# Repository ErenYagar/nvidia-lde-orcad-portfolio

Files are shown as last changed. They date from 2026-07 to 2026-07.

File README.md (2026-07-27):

# PCIe Gen3 x4 → M.2 NVMe adapter

**An interview-ready OrCAD X / Allegro PCB system-design case study.**<br>
This repository documents a six-layer, low-profile PCIe add-in card that physically connects a host PCIe slot to an M.2 M-Key 2280 NVMe SSD. It is a **passive interposer, not a protocol converter**.

**Current status:** `Interview_Digital_Complete_Not_For_Fabrication`<br>
**Not claimed:** PCIe compliance, universal SSD support, chassis compatibility, bench qualification, SI/PI sign-off, thermal validation or fabrication-ready release.

## Start here

1. [Open the bilingual visual portfolio](portfolio/index.html)
2. [Read the technical case study — English](PROJECT_REPORT_EN.md) / [繁體中文](PROJECT_REPORT_ZH.md)
3. [Use the interview walkthrough — English](docs/INTERVIEW_GUIDE.md) / [繁體中文](docs/INTERVIEW_GUIDE_ZH.md)
4. [Trace every claim — English](docs/CLAIM_EVIDENCE_MATRIX.md) / [繁體中文](docs/CLAIM_EVIDENCE_MATRIX_ZH.md)
5. [Read the documentation audit — English](docs/DOCUMENTATION_AUDIT_EN.md) / [繁體中文](docs/DOCUMENTATION_AUDIT_ZH.md)

## What the board actually does

| Boundary | Implementation |
|---|---|
| Host/SSD data | J1 PCIe edge → eight data pairs + REFCLK/sideband → J2 M.2 M-Key 2280 |
| Power | PCIe slot 12 V → TPS25947-family eFuse → TPS543620 6 A buck → 5 mΩ Kelvin shunt → 3.3 V SSD |
| Telemetry | INA238 current monitor + TMP1075 temperature sensor + target-only I²C header |
| PCB baseline | Six layers, 120 × 64 mm preliminary envelope, 1.6 mm nominal |

The system interface and layer intent are defined in [`docs/interface_definition.md`](docs/interface_definition.md) and [`docs/system_block_diagram.md`](docs/system_block_diagram.md).

## Five design decisions

| Decision | Why it is in the case study | Current boundary |
|---|---|---|
| 12 V + eFuse + buck | Makes protection, conversion and hot-loop reviewable | Slot budget/eFuse behavior still open |
| 5 mΩ Kelvin shunt | Enables low-loss current telemetry | Calibration/bench correlation open |
| No added lane conditioning | Preserves transmitter ownership until specs are confirmed | CEM/M.2 controlled pin source blocked |
| L1/L6 referenced to L2/L5 | Makes return-path intent explicit | Width/gap/via geometry pending fabricator |
| Gerber + IPC-2581-C | Provides available manufacturing exchange | ODB++ unsupported; not fab-ready |

Full options and exit conditions: [`docs/architecture_tradeoff.md`](docs/architecture_tradeoff.md).

## Verification snapshot

| Item | Result |
|---|---|
| Native RevK DRC / unconnected / active rats / shape islands | 0 / 0 / 0 / 0 in current gate report |
| Differential-pair objects | 9 native pairs (8 data + REFCLK) |
| PSpice 5 A / 7 A window | Recorded model windows pass the 3.135 V screen; recovery reaches 3.109 V and fails |
| PSpice sweep | 27 cases retained, runtime-limited; no pass inferred |
| 3DX / STEP | Current-board native views and AP242/mm isolated re-import recorded |
| Manufacturing | Gerber, NC Drill, IPC-2581-C, BOM/P&P generated for engineering review |
| Hardware | No board measurement, enumeration, SI/PI or thermal result claimed |

Evidence sources: [`evidence/stage3/stage3_delivery_gate.md`](evidence/stage3/stage3_delivery_gate.md), [`pspice/stage2/profile_results.csv`](pspice/stage2/profile_results.csv), [`evidence/stage3/3d_status.md`](evidence/stage3/3d_status.md), [`manufacturing/stage3_final_revk/README.md`](manufacturing/stage3_final_revk/README.md).

## Repository map

- `schematic/` — connection matrix, symbol pins, footprint assignments and native Capture reports.
- `pcb/` — constraints, differential pairs, 3D model mapping and the native RevK board.
- `pspice/` — command-line profiles, recovery sweep records and model limits.
- `evidence/` — hash-bound gates, native 3DX screens, portfolio views and collision status.
- `manufacturing/` — Gerber, NC Drill, IPC-2581-C, BOM/P&P, STEP and export manifest.
- `scripts/` — standard-library validators and negative fixtures.

## Reproduce the data checks

```powershell
python scripts/validate_csv.py --root .
python scripts/check_bom_fields.py manufacturing/bom.csv
python scripts/check_duplicate_pins.py schematic/connection_matrix.csv schematic/symbol_pinmap.csv
python scripts/check_net_names.py schematic/connection_matrix.csv
python scripts/check_documentation_links.py --root .
python scripts/check_portfolio_i18n.py
python -m unittest discover -s scripts -p "test_*.py" -v
```

Expected interpretation is documented in [`VALIDATION_STATUS.md`](VALIDATION_STATUS.md); repo-specific public-package gaps are reported rather than suppressed.

## Next revision

Rev L must obtain controlled PCIe/M.2 pin sources and the current JLCPCB stack-up, close the PSpice recovery/eFuse gates, replace preliminary mechanical models, then perform DFM, fabrication and bench bring-up. Until then, this is an honest digital interview package—not a board-order instruction.

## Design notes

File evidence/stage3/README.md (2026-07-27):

# Stage 3 evidence

This folder records the audited routing/manufacturing candidate. It does not
claim fabrication readiness, PCIe compliance, completed physical bring-up or
bench qualification.

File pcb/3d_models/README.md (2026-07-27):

# 3D Model Store

本目錄只保存可追溯、授權允許且與 exact MPN／assembly相符的 mechanical models。
MDT420M01501 原廠 STEP 已於 2026-07-24 保存並完成來源與結構驗證；
footprint transform 與 collision review 尚未核准。

## Naming

```text
<manufacturer>_<mpn>_<document-revision>_<download-date>.<step|stp|iges|sab>
```

不得用 `connector.step`、`final.step` 等無法追溯名稱。原始 vendor file若必須保留
官方檔名，mapping CSV仍要記錄 exact MPN與 SHA-256。

## Required record

- manufacturer、exact MPN／assembly revision；
- official product／model URL；
- drawing number／revision；
- download date、login／license限制；
- file size、SHA-256、units；
- original or repaired copy；
- reviewer與 disposition。

## Current inventory and blockers

- `amphenol_mdt420m01501_vendor-c3d-rev-unstated_2026-07-24.stp`：
  exact official product-page model，AP214／mm，SHA-256
  `F5427DE4C21FD8C98D0425E09D63247DC632733ACE2211E52F6E282C68F593CD`。
  Vendor model revision未宣告；Allegro rotation／offset與collision仍待確認。
- PCIe bracket／standoff／exact SSD：尚未選定 exact model。
- Board assembly：Stage 1 native `.brd` 已存在；Stage 2 electrical board尚未建立。

禁止以相近 connector、generic 2280 block或其他專案的 3D model把 blocker標成已完成。

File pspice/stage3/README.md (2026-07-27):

# Stage 3 PSpice power closure

`pw01_recovery_closure_132u_8p2.cir` reruns the exact Stage 2 combined
startup/5 A/7 A/recovery profile with a 132 uF effective output-capacitance
corner and 3 mOhm aggregate ESR.

The value is a simulation candidate, not a released BOM value. It requires
capacitor part-number selection, DC-bias/temperature/tolerance evidence and
layout-parasitic correlation before power design freeze.

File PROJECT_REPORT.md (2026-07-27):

# PCIe Gen3 x4 → M.2 NVMe Adapter — Technical Case Study

語言 / Language：[`繁體中文版`](PROJECT_REPORT_ZH.md)｜[`English full version`](PROJECT_REPORT_EN.md)

**NVIDIA LDE interview portfolio · Rev K / RevK evidence · `Interview_Digital_Complete_Not_For_Fabrication`**<br>
這份報告把 repository 由「檔案清單」改成一個可追溯的 PCB system-design 故事。所有結論都連回原理圖資料、PSpice record、native Allegro/3DX evidence 或製造輸出；未量測或未取得受控來源的項目維持 open/block status。

> **Boundary:** 本板是 PCIe host 與 M.2 NVMe SSD 之間的 passive physical interposer，不是 PCIe protocol converter。未宣稱 PCIe compliance、universal SSD support、chassis compatibility、bench qualification、SI/PI sign-off 或 fabrication-ready。

## 1. Executive summary / 專案摘要

我設計一張 low-profile、half-length、六層的 PCIe Gen3 x4 add-in card，將主機的 PCIe edge connection 引到 M.2 M-Key 2280 NVMe connector。專題的重點不是畫一張漂亮板，而是把 system intent、pin/net interface、power integrity 假設、3DX/STEP mechanical handoff、CAM 輸出與 Python negative tests 串成可審查的工程流程。

目前 RevK 的 digital closure 包含 native board、current-board 3DX views、AP242/mm STEP re-import、DRC/connectivity/shape reports、Gerber/NC Drill/IPC-2581、BOM/P&P 與 validators。剩餘問題被保留在矩陣中：受控 CEM/M.2 physical pin source、JLCPCB stack-up/impedance freeze、exact mechanical context、power-model recovery failure、eFuse validation 與 physical bring-up。

- Board baseline: 120 × 64 mm preliminary envelope, 1.6 mm nominal, six copper layers.
- Power target: 3.3 V / 5 A normal; 7 A / 100 µs is an engineering pulse, not a product rating.
- Current board evidence: DRC 0, unconnected 0, active rats 0, shape islands 0, nine native differential-pair objects.
- Status: digital/interview package complete; fabrication and hardware qualification blocked by documented gates.

## 2. What the board actually does / 功能邊界

### Signal path

The host Root Complex remains the PCIe protocol owner. J1 routes four TX/RX lane pairs, REFCLK and sidebands to J2. J2 is the M.2 M-Key 2280 mating point for an NVMe SSD. There is no retimer, switch, bridge, firmware or packet conversion logic on this board.

### Power path

PCIe slot 12 V is protected, converted and sensed before reaching the SSD. A separate auxiliary path supports telemetry and debug without allowing the external I²C header to back-feed the board.

### Telemetry path

INA238 measures the 5 mΩ Kelvin shunt; TMP1075 measures local board temperature. J3 exposes GND/SCL/SDA/3.3 V sense only. Address, pull-up and alert ownership remain a review item.

See [`docs/interface_definition.md`](docs/interface_definition.md) and [`docs/system_block_diagram.md`](docs/system_block_diagram.md) for the source interface definition.

```mermaid
flowchart LR
  HOST[PCIe Root Complex / Slot] -->|J1: 4 TX/RX pairs + REFCLK + sideband| BOARD[Six-layer interposer]
  BOARD -->|J2: M.2 M-Key 2280| SSD[NVMe SSD]
  HOST -->|12 V slot power| EFUSE[TPS25947 family eFuse]
  EFUSE --> BUCK[TPS543620 6 A synchronous buck]
  BUCK --> SHUNT[5 mΩ Kelvin shunt]
  SHUNT --> SSD
  SHUNT --> INA[INA238 current monitor]
  BOARD --> TMP[TMP1075 temperature sensor]
  INA --> J3[J3 target-only I²C header]
  TMP --> J3
```

## 3. Requirements and verification contract / 需求與驗證

| Requirement | Design response | Current status |
|---|---|---|
| PCIe Gen3 x4 physical connection | Eight data pairs plus REFCLK pair, short paired corridors, no unowned lane capacitors | Logical intent verified; physical pin freeze blocked |
| M.2 M-Key 2280 interface | J2 placement, SSD envelope, longitudinal mechanical baseline | Preliminary; exact mating/chassis context open |
| Low-profile six-layer board | L1 components/high-speed, L2 GND, L3 sideband, L4 power, L5 GND, L6 low-speed/edge breakout | Native baseline verified; fabricator geometry pending |
| 3.3 V / 5 A normal target | eFuse → 6 A buck → Kelvin shunt power chain | Engineering target; not bench-qualified |
| 7 A / 100 µs pulse study | Official buck model profile plus retained raw logs | Simulation-limited; recovery screen fails |
| Reviewable release package | Reports, hash-bound evidence, CAM outputs, STEP and Python checks | Digital package complete; not fab release |

The claim-to-evidence details are in [`docs/CLAIM_EVIDENCE_MATRIX.md`](docs/CLAIM_EVIDENCE_MATRIX.md).

## 4. Architecture and trade-offs / 架構選擇

I compared Architecture A (slot 3.3 V distribution) with Architecture B (slot 12 V plus local conversion). The weighted worksheet scores A 3.85 and B 3.45, but I selected B for this interview project because it exposes eFuse behavior, buck control, current sensing, hot-loop placement and PSpice work in one board. This is an engineering-portfolio decision, not a claim that B is universally superior.

| Decision | Options considered | Selected implementation | Verification / remaining risk |
|---|---|---|---|
| Input power | Slot 3.3 V vs 12 V conversion | 12 V → TPS25947-family → TPS543620 | [`docs/architecture_tradeoff.md`](docs/architecture_tradeoff.md); slot budget and inrush still need controlled-source confirmation |
| Protection | Fuse, load switch, eFuse | Current-limit/soft-start eFuse candidate | Model functional validation failed; ILIM/dVdt/ITIMER/SOA not frozen |
| Buck size | Smaller regulator vs 6 A class | TPS543620, with 5 A normal target and 7 A pulse screen | Official model exists; system recovery is not closed |
| Current sensing | No telemetry vs shunt monitor | 5 mΩ four-terminal Kelvin shunt + INA238 | Routing intent documented; calibration/bench data open |
| Temperature | No sensor vs local monitor | TMP1075 near power/SSD zone | I²C ownership and measured thermal result open |
| High-speed conditioning | Add AC caps/CMC/ESD vs preserve lane | No added lane conditioning before transmitter ownership is confirmed | Avoids an unverified topology change; CEM/M.2 source gate remains |
| Layer strategy | Mixed reference planes vs symmetric references | L1/L6 reference L2/L5; L4 power; L3 sideband | Width/gap/via geometry pending JLCPCB stack-up |
| Manufacturing exchange | ODB++/IPC-356 vs available exports | Gerber + NC Drill + IPC-2581-C; ODB++ unavailable, IPC-356 empty excluded | Output generation verified, DFM/fab approval open |

## 5. Capture and electrical interface / 原理圖與介面

The intended Capture deliverable is a seven-page hierarchy with formal symbols, pin map, footprint assignments, annotation, ERC and netlist reports. The public evidence is deliberately machine-readable:

- [`schematic/connection_matrix.csv`](schematic/connection_matrix.csv) is the logical source of nets, pins and statuses.
- [`schematic/symbol_pinmap.csv`](schematic/symbol_pinmap.csv) records symbol-level pins.
- [`schematic/footprint_assignment.csv`](schematic/footprint_assignment.csv) binds references to packages.
- [`schematic/orcad/stage2/reports/erc_report.txt`](schematic/orcad/stage2/reports/erc_report.txt) is the native-tool ERC evidence.

The key design discipline is to keep a logical name stable while refusing to invent a physical connector pin number. Therefore `PENDING_J1_*` and `PENDING_J2_*` are not silently promoted to `Confirmed_Official`; the B12/CLKREQ# and M.2 pin-32 conflict is called out in [`docs/pcie_m2_pin_mapping.md`](docs/pcie_m2_pin_mapping.md).

## 6. Power design and PSpice / 電源與模擬

The power calculation starts with `P = V × I`, a 5 mΩ shunt, effective capacitor rather than nominal label value, and a stated efficiency assumption. The full assumptions and calculations are in [`docs/power_budget.md`](docs/power_budget.md) and [`docs/component_selection.md`](docs/component_selection.md).

| Profile | Recorded observation | Disposition |
|---|---|---|
| Solver smoke | PSpice command-line solver concluded | Simulated pass; not a power-stage result |
| Startup / soft-start | 820 µs window ended while soft-start was active | Partial, not steady-state proof |
| 5 A steady | 3.149 V minimum in the recorded combined profile | Passes the 3.135 V screen for that model window only |
| 7 A / 100 µs | 3.204 V minimum in the recorded pulse window | Passes that model window only; 8.656 A peak inductor current is a margin concern |
| Recovery | 3.109 V minimum while PGOOD remained high | **Simulated failure** against the 3.135 V lower screen |
| eFuse isolated run | Encrypted model did not reach valid output startup | Functional validation failed / human review required |
| Loop stability / Monte Carlo | Model does not expose a supported small-signal/statistical path | `Not_Supported_By_Model` |
| COUT/ESR/CFF sweep | 27 cases saved with hashes, but runtime-limited | `Not_Concluded_Runtime_Limit`; no pass inferred |

The 132 µF / 3 mΩ / 8.2 pF candidate was a diagnostic rerun, not a released BOM value. The exact runtime record and hashes are in [`pspice/stage3/run_record.md`](pspice/stage3/run_record.md) and [`pspice/stage3/recovery_sweep/recovery_sweep_results.csv`](pspice/stage3/recovery_sweep/recovery_sweep_results.csv). A technically correct next step is to reduce the model/runtime problem, correlate layout parasitics, and rerun before making any supported-SSD claim.

## 7. PCB implementation and high-speed intent / PCB 與高速規劃

The native RevK board contains placement, copper-layer intent, shapes and nine differential-pair objects. The placement order is connector/SSD/mechanical envelope → PCIe corridors → eFuse/buck hot-loop → shunt/telemetry → debug points. L2 and L5 are GND references; L4 contains the named power regions. The current evidence reports DRC 0, unconnected 0, active rats 0 and zero shape islands.

This is digital PCB closure, not SI/PI closure. Pair widths, gaps, via drill/pad, anti-pads, reference layer, length skew and back-drill remain `Pending_Fabricator_Confirmation` until the actual JLCPCB stack-up and governing PCIe/M.2 requirements are loaded into Constraint Manager. See [`pcb/constraints.csv`](pcb/constraints.csv), [`pcb/differential_pairs.csv`](pcb/differential_pairs.csv) and [`evidence/stage3/constraint_manager_status.md`](evidence/stage3/constraint_manager_status.md).

## 8. Mechanical review, 3DX and STEP / 機構與 3D

Native 3DX views are evidence of the current board database, not decoration. The repository keeps engineering UI views in [`evidence/stage3/3dx_native_revk/`](evidence/stage3/3dx_native_revk/) and cleaner portfolio views in [`evidence/stage3/portfolio_revk/`](evidence/stage3/portfolio_revk/). The assembly STEP is AP242/mm and has an isolated native DRA readback recorded in [`evidence/stage3/3d_status.md`](evidence/stage3/3d_status.md).

The SSD body and several mechanical bodies are conservative or drawing-derived envelopes. Exact chassis, bracket, standoff, cable and mating J2 transforms are not all controlled, so `3D-01`/`3D-08` can be preliminary-clear while other collision cases remain blocked. A rendered image cannot upgrade a missing model to a collision Pass.

## 9. Manufacturing and release / 製造輸出

| Output | Current state | Boundary |
|---|---|---|
| Gerber artwork | Generated and hash-listed | Engineering review; not DFM approval |
| NC Drill | Generated, two drill files | Tooling/board-house review still required |
| IPC-2581-C | Generated | Intelligent exchange present; not a fabrication sign-off |
| BOM / P&P | Generated preliminary | Procurement, alternates and assembly review open |
| STEP | Generated preliminary and re-imported | Exact mechanical fit open |
| IPC-356 | Empty output excluded | Not claimed as delivered |
| ODB++ | Not supported by installed tool | Not claimed as delivered |

The package-level status and artifact hashes are in [`manufacturing/stage3_final_revk/README.md`](manufacturing/stage3_final_revk/README.md), [`manufacturing/stage3_final_revk/export_status.csv`](manufacturing/stage3_final_revk/export_status.csv) and [`manufacturing/stage3_final_revk/artifact_manifest.csv`](manufacturing/stage3_final_revk/artifact_manifest.csv).

## 10. Automation and negative tests / 自動化

The project uses standard-library Python (`csv`, `argparse`, `pathlib`, `unittest`) as a review layer around native Cadence reports. Typical commands are:

```powershell
python scripts/validate_csv.py --root .
python scripts/check_bom_fields.py manufacturing/bom.csv
python scripts/check_duplicate_pins.py schematic/connection_matrix.csv schematic/symbol_pinmap.csv
python scripts/check_net_names.py schematic/connection_matrix.csv
python scripts/check_documentation_links.py --root .
python scripts/check_portfolio_i18n.py
python -m unittest discover -s scripts -p "test_*.py" -v
```

Negative fixtures cover missing BOM columns/MPN, duplicate pins, invalid nets, Stage 2 missing pin/pad mismatch/unplaced component, stale hash, missing evidence and false routing claims. The validators test data contracts; they do not parse proprietary `.brd`/`.dsn` binaries or replace human review of native Cadence reports.

## 11. Results and limitations / 結果與限制

| Area | Result | Confidence |
|---|---|---|
| System architecture and interface narrative | Closed as a reviewable design intent | Verified against source docs |
| Native board digital closure | DRC/connectivity/shape counters closed for RevK | Verified by current gate report |
| Power topology | Implemented as a design baseline | Preliminary |
| Official buck profile | 5 A and 7 A windows recorded; recovery fails | Simulation-limited |
| eFuse behavior | Isolated validation did not conclude | Blocked/open |
| Constraint Manager | Pair objects exist; impedance geometry not frozen | Blocked by stack-up/spec |
| 3DX/STEP | Current-board views and round-trip evidence exist | Verified for handoff loop; fit preliminary |
| Manufacturing files | Digital outputs generated | Preliminary, not fab-ready |
| Physical bring-up | No board measurement | Open |

## 12. Rev L / next revision plan

Rev L should be a controlled ECO, not a cosmetic redraw:

1. Obtain legal PCIe CEM and M.2 controlled specifications; freeze J1/J2 physical pins and record revision/page evidence.
2. Import the current JLCPCB six-layer stack-up; calculate and freeze width/gap/via geometry and update Constraint Manager.
3. Close the 3.109 V recovery issue with a faster/partitioned model or measured correlation; rerun 5 A, 7 A/100 µs and line/load corners.
4. Validate TPS25947 current-limit, soft-start, inrush and latch-off behavior with a supported model or bench plan.
5. Replace preliminary mechanical envelopes with exact vendor STEP/drawing transforms; rerun `3D-01`–`3D-08`.
6. Run DFM/CAM review, obtain a board-house quote, fabricate a small lot, and then execute safe power-up → SSD insertion → enumeration → link width/speed → NVMe identify → stress → thermal sequence.

## 13. Demonstrated skills / 展示的能力

- Translating a system requirement into connector, lane, sideband, power and telemetry interfaces.
- Making an architecture trade-off visible instead of hiding it in a schematic.
- Building a Capture-to-Allegro source chain with symbol/pin/footprint traceability.
- Reasoning about buck current, effective capacitance, Kelvin sensing, hot-loop placement and transient limits.
- Defining differential-pair intent and reference-plane strategy without inventing fabricator geometry.
- Using native 3DX/STEP as an auditable MCAD handoff, not as a substitute for exact fit.
- Preserving failed/partial simulation evidence and writing validators/negative tests around native-tool reports.
- Communicating scope, uncertainty and release gates—the core behavior expected from a junior board-design engineer.

## 14. Interview walkthrough / 面試用法

- **30 seconds:** show the hero image and say “passive PCIe Gen3 x4 to M.2 adapter; six layers; protected 12 V to 3.3 V power; current result is digital interview closure, not a fabricated product.”
- **2 minutes:** use the architecture diagram, explain why Architecture B was selected, then show DRC/connectivity and 3DX/STEP evidence.
- **5 minutes:** open the Capture matrix, power profile table, nine differential pairs and manufacturing status. Mention the 3.109 V recovery failure before the interviewer asks.
- **10 minutes:** walk through the claim matrix, the B12/Pin32 pin-source gate, JLCPCB stack-up dependency, eFuse validation gap, and the Rev L closure plan.

The complete question-and-answer script is [`docs/INTERVIEW_GUIDE.md`](docs/INTERVIEW_GUIDE.md); the claim-to-evidence index is [`docs/CLAIM_EVIDENCE_MATRIX.md`](docs/CLAIM_EVIDENCE_MATRIX.md).

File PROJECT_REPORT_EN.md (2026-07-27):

# PCIe Gen3 x4 → M.2 NVMe Adapter — Technical Case Study (English)

繁體中文版：[`PROJECT_REPORT_ZH.md`](PROJECT_REPORT_ZH.md)｜Current master report with evidence links: [`PROJECT_REPORT.md`](PROJECT_REPORT.md)

**Status: `Interview_Digital_Complete_Not_For_Fabrication`**

## 1. Executive summary

This project is a low-profile, half-length, six-layer PCIe Gen3 x4 add-in card that physically connects a host PCIe edge connector to an M.2 M-Key 2280 NVMe SSD. It is a passive physical interposer, not a protocol converter: the host Root Complex and the NVMe controller remain the protocol endpoints.

The public package connects Capture interface data, native Allegro placement and constraints, 3DX/STEP handoff, PSpice profiles, CAM outputs, BOM/P&P and Python validators. It does not claim PCIe compliance, universal SSD support, chassis compatibility, bench qualification or fabrication readiness.

## 2. Actual function and boundary

- **Signal:** J1 PCIe edge → four lanes of TX/RX, REFCLK and sidebands → J2 M.2 M-Key 2280.
- **Power:** `P12V_SLOT` → TPS25947 family eFuse → TPS543620 6 A buck → 5 mΩ Kelvin shunt → `P3V3_NVME`.
- **Telemetry:** INA238 current monitor, TMP1075 temperature sensor and target-only I²C header.
- **Excluded:** PCIe switch, retimer, bridge, firmware, packet conversion and host enumeration logic.

Source documents: [`docs/interface_definition.md`](docs/interface_definition.md) and [`docs/system_block_diagram.md`](docs/system_block_diagram.md).

## 3. Requirements and verification contract

| Requirement | Design response | Current status |
|---|---|---|
| PCIe Gen3 x4 physical path | Eight data pairs, REFCLK and sidebands | Logical intent present; physical pin freeze blocked |
| M.2 M-Key 2280 | J2 placement, SSD envelope and retention baseline | Preliminary |
| Six layers / 1.6 mm nominal | L1/L6 signal, L2/L5 GND, L3 control, L4 power | Native baseline present; fabricator geometry pending |
| 3.3 V / 5 A normal target | eFuse, 6 A buck and Kelvin shunt | Engineering target; not bench-qualified |
| 7 A / 100 µs pulse study | Official buck-model transient profile | Simulation-limited |
| Reviewable release package | Reports, hashes, 3DX, STEP, CAM and validators | Digital package complete |

## 4. Architecture and design decisions

I compared slot 3.3 V distribution with slot 12 V plus local conversion. Architecture B was selected because it exposes protection, conversion, current sensing, hot-loop placement and PSpice reasoning in one interview project; it is not presented as universally superior.

| Decision | Selection | Reason and remaining risk |
|---|---|---|
| Input power | 12 V + eFuse + buck | Reviewable protection/conversion; slot budget and inrush are not closed by a controlled source |
| Regulator | TPS543620, 6 A class | 5 A normal and short pulse study; recovery still fails |
| Current sense | 5 mΩ four-terminal Kelvin shunt + INA238 | Low drop and observable rail; calibration/bench data open |
| High-speed conditioning | No added AC caps, termination, CMC or ESD | Waits for transmitter ownership and CEM/M.2 source confirmation |
| Layer strategy | L1/L6 referenced to L2/L5, L4 power | Width/gap/via depend on JLCPCB stack-up |
| Manufacturing exchange | Gerber + NC Drill + IPC-2581-C | ODB++ unsupported; empty IPC-356 excluded |

## 5. Capture and electrical interface

`schematic/connection_matrix.csv` is the logical source; `symbol_pinmap.csv`, `footprint_assignment.csv` and the native ERC report provide pin-to-footprint traceability. Because the controlled PCIe CEM/M.2 documents are not included in the public package, J1/J2 critical physical pins remain `Pending_Human_Verification`. The B12/CLKREQ# and M.2 pin-32 revision conflict is recorded instead of guessed.

## 6. Power and PSpice

The power estimate uses `P = V × I`, a 5 mΩ shunt, effective capacitance and explicit efficiency assumptions.

| Profile | Observation | Disposition |
|---|---|---|
| Solver smoke | Command-line solver concluded | Simulated |
| 5 A steady | 3.149 V minimum in the recorded window | Passes that model window only |
| 7 A / 100 µs | 3.204 V minimum in the recorded window | Passes that model window only |
| Recovery | 3.109 V, below the 3.135 V screen | **Simulated failure** |
| eFuse isolated run | No valid output startup reached | Functional validation failed |
| COUT/ESR/CFF sweep | 27 cases stopped by runtime limit | Not concluded |

The 132 µF candidate is not a released BOM value. No supported-SSD claim is inferred from the partial or failed runs.

## 7. PCB and high-speed intent

The RevK native board contains placement, power shapes, return-path intent and nine differential-pair objects (eight data plus REFCLK). The current gate report records DRC 0, unconnected 0, active rats 0 and zero shape islands.

This is digital PCB closure, not SI/PI sign-off. Pair width, gap, via, anti-pad, reference layer, skew and back-drill must wait for the JLCPCB stack-up and governing specification.

## 8. Mechanical review, 3DX and STEP

Native 3DX screenshots, portfolio views and AP242/mm STEP re-import are bound to the current RevK board hash. SSD, J2, standoff, bracket and host-chassis inputs are not all exact controlled models. Collision cases therefore remain `Preliminary_Clear` or `Blocked_Missing_Exact_Model`; a polished image cannot upgrade a missing model to Pass.

## 9. Manufacturing outputs

Gerber, NC Drill, IPC-2581-C, BOM, preliminary P&P, assembly-drawing evidence and STEP are exported. IPC-356 was empty and excluded; ODB++ is unsupported by the installed tool. This is an engineering-review package, not a direct fabrication release.

## 10. Automation and negative tests

The Python layer uses `csv`, `argparse`, `pathlib` and `unittest` to check CSV schemas, BOM fields, duplicate pins, net naming and Stage 2/3 evidence contracts. Negative fixtures cover missing columns/MPN, duplicate pins, invalid nets, pad mismatch, unplaced components, stale hashes, missing evidence and false routing claims. Python does not parse proprietary `.brd`/`.dsn` files and does not replace native Cadence review.

## 11. Results and limitations

| Area | Result |
|---|---|
| System architecture | Reviewable design intent closed |
| Native PCB digital closure | RevK DRC/connectivity/shape counters closed |
| Power topology | Preliminary baseline |
| PSpice | 5 A/7 A windows recorded; recovery failure |
| Constraint Manager | Pair objects present; impedance geometry not frozen |
| 3DX/STEP | Handoff loop verified; exact fit preliminary |
| Manufacturing | Digital outputs generated; not fab-ready |
| Hardware | No physical measurement claimed |

## 12. Rev L plan

Obtain controlled CEM/M.2 specifications, freeze J1/J2 physical pins, import the current JLCPCB stack-up, close recovery and eFuse behavior, replace exact mechanical models, then perform DFM, fabrication, safe power-up, enumeration, Gen3 x4 link, NVMe identify, stress and thermal testing.

## 13. Demonstrated skills

Requirements decomposition, architecture trade-offs, Capture/Allegro traceability, buck/shunt/power reasoning, differential-pair constraints, 3DX/STEP handoff, CAM automation, negative testing, failure disclosure and release-gate communication.

## 14. Interview walkthrough

- **30 seconds:** “I designed a passive PCIe Gen3 x4 to M.2 2280 physical adapter and built the Capture, power, Allegro, 3DX/STEP, CAM and validation workflow.”
- **2 minutes:** Explain Architecture B, DRC/connectivity, 3DX/STEP and the power chain.
- **5 minutes:** Show the 3.109 V recovery failure, nine pair objects, the pin-source gate and fabrication blockers.
- **10 minutes:** Use the [bilingual interview guide](docs/INTERVIEW_GUIDE.md) and [claim matrix](docs/CLAIM_EVIDENCE_MATRIX.md) for an evidence-based design review.

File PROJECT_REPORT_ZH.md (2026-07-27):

# PCIe Gen3 x4 → M.2 NVMe 轉接板：技術專題報告（繁體中文）

英文完整版：[`PROJECT_REPORT_EN.md`](PROJECT_REPORT_EN.md)｜目前混合版主報告：[`PROJECT_REPORT.md`](PROJECT_REPORT.md)

**狀態：`Interview_Digital_Complete_Not_For_Fabrication`**

## 1. 專案摘要

本專題設計一張 low-profile、half-length、六層 PCIe Gen3 x4 add-in card，將主機 PCIe edge connector 實體連接到 M.2 M-Key 2280 NVMe SSD。它是 passive physical interposer，不是 protocol converter；Host Root Complex 與 NVMe controller 仍是協定端點。

目前完成的工作包含 Capture 介面資料、Allegro native board、placement、differential-pair objects、3DX/STEP handoff、PSpice profile、CAM 輸出、BOM/P&P 與 Python validators。Fabrication release、PCIe compliance、通用 SSD、chassis fit 與實體 bring-up 均未宣稱完成。

## 2. 實際功能與邊界

- **訊號：** J1 PCIe edge → 4 lanes 的 TX/RX、REFCLK、sideband → J2 M.2 M-Key 2280。
- **供電：** `P12V_SLOT` → TPS25947 family eFuse → TPS543620 6 A buck → 5 mΩ Kelvin shunt → `P3V3_NVME`。
- **遙測：** INA238 電流 monitor、TMP1075 溫度 sensor、target-only I²C header。
- **不包含：** PCIe switch、retimer、bridge、firmware、封包轉換或 host enumeration logic。

來源：[interface definition](docs/interface_definition.md)、[system block diagram](docs/system_block_diagram.md)。

## 3. 需求與驗證契約

| 需求 | 設計回應 | 目前狀態 |
|---|---|---|
| PCIe Gen3 x4 physical path | 八組 data pairs、REFCLK、sideband | Logical intent 有；physical pin freeze blocked |
| M.2 M-Key 2280 | J2 placement、SSD envelope、retention baseline | Preliminary |
| 六層、1.6 mm nominal | L1/L6 signal、L2/L5 GND、L3 control、L4 power | Native baseline 有；fabricator geometry pending |
| 3.3 V / 5 A normal | eFuse、6 A buck、Kelvin shunt | Engineering target，未 bench-qualified |
| 7 A / 100 µs pulse | Official buck model transient profile | Simulation-limited |
| 可審查交付 | reports、hash、3DX、STEP、CAM、validators | Digital package complete |

## 4. 架構選擇與設計決策

我比較了 slot 3.3 V distribution 與 slot 12 V + local conversion。最後選 Architecture B，因為它能在一個面試專題中呈現 eFuse、buck control、current sensing、hot-loop placement 與 PSpice；這不代表 B 在所有產品上都優於 A。

| 決策 | 選擇 | 理由與未完成風險 |
|---|---|---|
| 輸入電源 | 12 V + eFuse + buck | 可審查保護與轉換；slot budget/inrush 未由 controlled source 關閉 |
| Regulator | TPS543620 6 A | 5 A normal 與短暫 pulse；recovery 仍失敗 |
| 電流感測 | 5 mΩ 四端 Kelvin shunt + INA238 | 低壓降、可遙測；calibration/bench 未完成 |
| 高速調整 | 暫不加 AC caps、termination、CMC、ESD | 等 transmitter ownership 與 CEM/M.2 pin source 確認 |
| Layer strategy | L1/L6 參考 L2/L5，L4 為 power | Width/gap/via 等 JLCPCB stack-up 確認 |
| Manufacturing exchange | Gerber + NC Drill + IPC-2581-C | ODB++ 不支援；IPC-356 空檔排除 |

## 5. Capture 與電氣介面

`schematic/connection_matrix.csv` 是 logical source；`symbol_pinmap.csv`、`footprint_assignment.csv` 與 native ERC report 形成 pin-to-footprint traceability。由於受控 PCIe CEM/M.2 文件尚未納入公開 package，J1/J2 critical physical pins 保持 `Pending_Human_Verification`。B12/CLKREQ# 與 M.2 pin 32 的版本衝突被記錄，而不是猜測。

## 6. 電源與 PSpice

功率估算使用 `P = V × I`、5 mΩ shunt、effective capacitance 與明示的效率假設。主要結果：

| Profile | 結果 | 狀態 |
|---|---|---|
| Solver smoke | command-line solver concluded | Simulated |
| 5 A steady | 3.149 V minimum in recorded window | 僅該 model window pass |
| 7 A / 100 µs | 3.204 V minimum in recorded window | 僅該 model window pass |
| Recovery | 3.109 V，低於 3.135 V screen | **Simulated failure** |
| eFuse isolated run | 未達有效 output startup | Functional validation failed |
| COUT/ESR/CFF sweep | 27 cases 被 runtime limit 中止 | Not concluded |

因此目前不能由模擬推導 supported-SSD claim，也不能把 132 µF candidate 當成 released BOM。

## 7. PCB 與高速設計

RevK native board 已有 placement、power shapes、return-path intent 與九組 differential-pair objects（八組 data + 一組 REFCLK）。目前 gate report 記錄 DRC 0、unconnected 0、active rats 0、shape islands 0。

這是 digital PCB closure，不是 SI/PI sign-off。Pair width、gap、via、anti-pad、reference layer、skew 與 back-drill 必須等 JLCPCB stack-up 與 governing spec 到位後才能 freeze。

## 8. 機構、3DX 與 STEP

Native 3DX screenshots、portfolio views 與 AP242/mm STEP re-import 都已綁定目前 RevK board hash。SSD、J2、standoff、bracket 與 host chassis 並非全部 exact controlled models，因此碰撞案例只能是 `Preliminary_Clear` 或 `Blocked_Missing_Exact_Model`，不能由漂亮圖片升級為 Pass。

## 9. 製造輸出

Gerber、NC Drill、IPC-2581-C、BOM、preliminary P&P、assembly drawing evidence 與 STEP 均已輸出。IPC-356 為空檔並排除；安裝工具不支援 ODB++。所以這是 engineering review package，不是直接上傳板廠的 fabrication release。

## 10. 自動化與 negative tests

Python 使用 `csv`、`argparse`、`pathlib`、`unittest`，檢查 CSV schema、BOM 欄位、duplicate pins、net naming、Stage 2/3 evidence contract。Negative fixtures 覆蓋 missing column/MPN、duplicate pin、invalid net、pad mismatch、unplaced component、stale hash、missing evidence 與 false routing claim。Python 不解析 proprietary `.brd`/`.dsn`，也不取代 native Cadence review。

## 11. 結果與限制

| 區域 | 結果 |
|---|---|
| System architecture | Reviewable design intent closed |
| Native PCB digital closure | RevK DRC/connectivity/shape counters closed |
| Power topology | Preliminary baseline |
| PSpice | 5 A/7 A windows recorded；recovery failure |
| Constraint Manager | Pair objects 有；impedance geometry 未 freeze |
| 3DX/STEP | Handoff loop verified；exact fit preliminary |
| Manufacturing | Digital outputs generated；not fab-ready |
| Hardware | No physical measurement claimed |

## 12. Rev L 計畫

取得受控 CEM/M.2 規格、凍結 J1/J2 physical pins、匯入當期 JLCPCB stack-up、關閉 recovery 與 eFuse、替換 exact mechanical models，再執行 DFM、下板、上電、enumeration、Gen3 x4 link、NVMe identify、stress 與 thermal sequence。

## 13. 展示的能力

需求拆解、架構 trade-off、Capture/Allegro traceability、buck/shunt/power reasoning、differential-pair constraint、3DX/STEP handoff、CAM automation、negative testing、failure disclosure 與 release-gate communication。

## 14. 面試說法

- **30 秒：** 我設計的是 passive PCIe Gen3 x4 到 M.2 2280 physical adapter，並完成 Capture、power、Allegro、3DX/STEP、CAM 與驗證流程。
- **2 分鐘：** 說明 Architecture B、DRC/connectivity、3DX/STEP 與 power chain。
- **5 分鐘：** 主動展示 3.109 V recovery failure、nine pairs、pin-source gate 與 fabrication blockers。
- **10 分鐘：** 使用 [雙語面試指南](docs/INTERVIEW_GUIDE.md) 與 [claim matrix](docs/CLAIM_EVIDENCE_MATRIX.md) 做 evidence-based design review。

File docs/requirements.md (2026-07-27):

# Requirements and Traceability

## 系統邊界

本專案設計單一 PCIe Gen3 x4 Add-in Card 至單一 M.2 2280 M-Key NVMe SSD。外部系統包含 host PCIe slot、NVMe SSD、I²C reader 與量測儀器；板上不包含 PCIe switch、retimer、redriver、MCU 或第二顆 SSD。

## Requirement matrix

| ID | Requirement | 類型 | 來源／理由 | 驗證方法 | 目前狀態 |
|---|---|---|---|---|---|
| SYS-001 | 板卡應提供 PCIe Gen3 x4 host-to-NVMe data path | Functional | 專案目標；[PCI-SIG CEM 3.0](https://pcisig.com/PCIExpress/Specs/CEM/CardElectromechanical_3.0) | net review、constraint report、planned enumeration | `Planned` |
| SYS-002 | 應支援單一 M.2 2280 M-Key NVMe SSD | Functional／Mechanical | 專案目標；M.2 governing spec 待取得 | drawing review、3D clearance、planned fit check | `Pending_Human_Verification` |
| SYS-003 | 板形應為 low-profile、half-length | Mechanical | 專案目標；PCIe CEM mechanical definition | outline dimension audit、bracket／chassis check | `Pending_Human_Verification` |
| IF-001 | Lane 0–3、P/N、TX/RX、REFCLK 與 sideband mapping 必須逐 pin 可追溯 | Interface | governing PCIe／M.2 requirements | 雙來源 pin review、CSV checker、schematic inspection | `Pending_Human_Verification` |
| IF-002 | 板上不得任意增加 PCIe lane AC coupling、termination、CMC 或 ESD | Signal integrity | 避免未經規格支持的 channel discontinuity | schematic BOM audit、design review | `Planned` |
| IF-003 | PERST#、CLKREQ#、PEWAKE#、PRSNT 應依 applicable specification 實作 | Interface | PCIe CEM／M.2 | pin map review、ERC、planned functional test | `Pending_Human_Verification` |
| PWR-001 | 主電源路徑應為 12 V slot → eFuse → buck → 3.3 V NVMe | Power | architecture decision | schematic review、netlist、planned power-up | `Planned` |
| PWR-002 | eFuse 應提供受控 slew／inrush、current protection 與 fault／PG visibility | Protection | Rev A safety／debug requirement；已選 [TI TPS259472LRPWR](https://www.ti.com/product/TPS25947/part-details/TPS259472LRPWR) | [power budget](power_budget.md)、ILIM／dV/dt／ITIMER／SOA 計算、PSpice、planned bench fault test | `Engineering_Assumption` |
| PWR-003 | 3.3 V buck 應以 5 A steady-state 為設計點 | Power | engineering target，不是 SSD universal rating | calculation、thermal estimate、PSpice、planned load test | `Engineering_Assumption` |
| PWR-004 | 電源應以 7 A / 100 µs load pulse 作 transient validation stimulus | Power transient | margin test；不是 continuous rating | PSpice load-step profile、planned electronic-load test | `Engineering_Assumption` |
| PWR-005 | 若 slot power、thermal 或 transient Gate 不通過，應限制支援 SSD 清單 | Safety／Product | 防止 overclaim | [supported SSD matrix](../validation/supported_ssd_matrix.csv)、release checklist 與 per-device evidence | `Planned` |
| MON-001 | 應量測 3.3 V NVMe rail 的 current、bus voltage 與 calculated power | Telemetry | debug／validation goal；[TI INA238](https://www.ti.com/product/INA238/part-details/INA238AIDGSR) | register readback、DMM correlation；尚未量測 | `Not_Yet_Measured` |
| MON-002 | 應提供 PCB 鄰近溫度 sensing，並明示不等同 SSD junction temperature | Telemetry | thermal debug；[TI TMP1075](https://www.ti.com/product/TMP1075/part-details/TMP1075DR) | I²C readback、reference thermometer correlation | `Not_Yet_Measured` |
| MON-003 | 應提供獨立 1×4 I²C header：GND、SCL、SDA、3.3 V sense，禁止外部回灌 | Interface／Safety | 專案邊界；[ADI ADP198](https://www.analog.com/en/products/adp198.html) reverse-current-blocking function | U5／RISO1 schematic review、label review、unpowered injection and output-short checks | `Planned` |
| PCB-001 | PCB 應使用六層結構，L1/L2 與 L6/L5 提供連續高速 reference | Layout | architecture baseline | stack-up／plane review | `Engineering_Assumption` |
| PCB-002 | 最終 impedance geometry 必須由投板當下板廠 stack-up 凍結 | Manufacturing | [JLCPCB calculator guide](https://jlcpcb.com/help/article/user-guide-to-the-jlcpcb-impedance-calculator) | 保存 calculator、stack-up、quote evidence | `Pending_Fabricator_Confirmation` |
| PCB-003 | PCIe pairs 應以短、直、同層、對稱 transition 與鄰近 return vias 為原則 | Signal integrity | return-path control | Constraint Manager report、layout review | `Planned` |
| PCB-004 | Buck hot loop、switch-node keepout、Kelvin shunt 與 thermal vias 應完成專項 review | Power integrity | datasheet／layout best practice | layout review checklist、DRC | `Planned` |
| CAD-001 | OrCAD schematic 必須可重開、annotation 可重現、ERC 無未解釋項 | Tool／Quality | portfolio quality gate | native round-trip、ERC log | `Planned` |
| SIM-001 | 每個 PSpice profile 應記錄 model、condition、time step、stop time、probe 與 criteria | Simulation | reproducibility | profile review、run log | `Planned` |
| SIM-002 | 不支援的 loop stability／Monte Carlo 應標為 `Not_Supported_By_Model`，不得偽造 | Integrity | evidence policy | model／license audit | `Planned` |
| REL-001 | Release package 應包含 Gerber、NC Drill、IPC netlist、BOM、P&P、assembly drawing 與 checklist | Manufacturing | handoff readiness | CAM／package manifest audit | `Planned` |
| VAL-001 | Bring-up 應依 visual → shorts → current-limited power → rails → SSD → enumeration → stress 順序 | Validation／Safety | controlled bring-up | test traveler 與 debug log | `Planned` |
| VAL-002 | 實測前，enumeration、link width／speed、power、ripple、thermal 均維持 `Not_Yet_Measured` | Integrity | truth-in-evidence rule | repository status audit | `Not_Yet_Measured` |
| DOC-001 | 每個 critical data row 應有 source、status 與 review note | Traceability | project quality gate | CSV validation、peer review | `Planned` |
| DOC-002 | 所有對外材料不得宣稱 PCIe compliance | Portfolio integrity | project scope | README／slides／resume text audit | `Planned` |

## 驗收情境

1. **Pin conflict negative case**：同一 connector pin 指向不同 net 時，checker 必須 exit `1`，且 Gate 1 不得通過。
2. **Missing source negative case**：critical power／pin／impedance row 標為 `Confirmed_Official` 但沒有 `Source_Document` 時必須失敗。
3. **Power margin failure**：7 A pulse 造成 unacceptable droop、current limit 或 thermal margin 不足時，修正 power stage 或限制 SSD，不可修改 pass criteria 掩蓋問題。
4. **Fabricator change**：stack-up revision 改變時，重新計算 geometry 並重跑 Constraint Gate，不沿用舊 trace width。
5. **No hardware case**：即使 CAD 與 simulation 完整，只能報告 `Planned` bring-up／`Not_Yet_Measured` results。

## 需求變更控制

新增 SSD form factor、Gen4／Gen5、額外 connector、retimer 或 MCU 均視為 scope change，必須建立新 requirement、architecture review 與 revision；Rev A 不預留 speculative circuitry。

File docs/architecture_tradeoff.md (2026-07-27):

# Power Architecture Trade-off

## 問題定義

NVMe SSD 需要 3.3 V 電源。Rev A 有兩個合理來源：

- **Architecture A**：直接使用 PCIe slot 3.3 V，經 eFuse／load switch、sense 與 filtering 後送至 SSD。
- **Architecture B**：使用 PCIe slot 12 V，經 eFuse 後由 synchronous buck 轉為 3.3 V。

本比較評估的不只是 BOM 數量，也包含 slot power boundary、inrush、thermal、PSpice 可驗證性、layout difficulty 與 NVIDIA LDE 面試價值。

## 比較矩陣

評分採 1（不利）至 5（有利）；分數是 `Engineering_Assumption`，在正式 power budget 前只用於決策排序。

| 評估面向 | 權重 | A：slot 3.3 V | B：12 V + buck | 判讀 |
|---|---:|---:|---:|---|
| 電路簡潔度 | 15% | 5 | 2 | A 元件少、轉換損耗少 |
| 可用電流／power flexibility | 20% | 2 | 4 | B 可能較容易配置較高 3.3 V load，但仍受 CEM slot budget 限制 |
| Inrush／fault control | 10% | 4 | 4 | 兩者皆可用 eFuse；B 還需管理 buck startup |
| Efficiency／thermal | 15% | 5 | 3 | A 少一級轉換；B 必須實證 efficiency 與溫升 |
| Noise／SI coexistence | 10% | 5 | 3 | B 增加 switch node 與 hot loop |
| PSpice／power-debug 展示價值 | 15% | 2 | 5 | B 可展示 startup、transient、control 與 layout judgment |
| Layout／bring-up 風險 | 10% | 5 | 3 | B 的 placement、return path 與 thermal 難度較高 |
| BOM／availability | 5% | 5 | 3 | B 料件較多且 exact variants 必須管控 |
| **加權分數** | **100%** | **3.85** | **3.45** | 分數不是唯一決策依據 |

## 決策

Rev A **暫定採 Architecture B**：

```text
P12V_SLOT
  -> TPS25947-family eFuse
  -> P12V_PROTECTED
  -> TPS543620 synchronous buck
  -> P3V3_PRE_SENSE
  -> 5 mΩ Kelvin shunt
  -> P3V3_NVME
```

原因不是 B 的加權分數較高，而是本作品集的主要目標包含 power budget、soft-start、inrush、load transient、Power Good、PSpice 與 power-layout review。這些能力與 LDE／board design 面試的關聯度高，且可以用明確 Gate 控制風險。

決策狀態為 `Engineering_Assumption`，尚未 Power Design Freeze。

## B 架構的強制退出條件

若任一條成立，Rev A 必須回到 Architecture A 或限制支援 SSD：

1. 正式 CEM 資料顯示 slot 12 V power／inrush 無法涵蓋定義負載與 margin。
2. TPS543620 在實際 Vin、temperature、frequency、inductor 與 PCB thermal 條件下不能支援 5 A steady-state。
3. 7 A / 100 µs stimulus 觸發 unacceptable droop、current limit 或 instability，且合理 Cout／layout 無法修正。
4. eFuse SOA、latch behavior 或 current-limit tolerance 與 buck startup 不相容。
5. switching converter 與 PCIe lane 的 placement／return-path isolation 在 low-profile half-length outline 內無法成立。
6. exact parts、footprints、models 或供應狀態無法在 release 前確認。

## 主要元件決策邊界

- [TPS543620](https://www.ti.com/product/TPS543620) 的官方產品頁列出 4–18 V input、6 A synchronous buck、Power Good、soft-start 與 PSpice transient model。這只證明元件功能，不代表本系統已通過 5 A／7 A case。
- [TPS25947](https://www.ti.com/product/TPS25947) family 提供可調 soft-start／current protection 及不同 fault behavior；已由 TI Rev. C truth table 選定 `TPS259472LRPWR`（active current limit、PG／PGTH、latch-off）。此確認只涵蓋料號功能與 Pin，不代表 slot power、ILIM、dV/dt、SOA 或 fault coordination 已通過。
- 5 mΩ shunt、INA238 gain range、rail drop、power dissipation 與 error budget必須整體計算，不以單一額定值選料。

## Decision record

| 項目 | 結論 | 狀態 | 下一個證據 |
|---|---|---|---|
| Power source | 優先 12 V slot | `Engineering_Assumption` | CEM slot power review |
| Protection | TPS259472LRPWR | `Engineering_Assumption` | ILIM／dV/dt／ITIMER／SOA 與 slot-power coordination |
| Buck | TPS543620 | `Engineering_Assumption` | component calculation + PSpice |
| Load envelope | 5 A normal；7 A / 100 µs stimulus | `Engineering_Assumption` | target SSD data + transient result |
| Fallback | Architecture A 或 restricted SSD list | `Planned` | Gate 2 decision |

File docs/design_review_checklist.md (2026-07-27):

# Design Review Checklist

本清單是 release gate，不是工作完成宣告。未勾選項目均為 `Planned`；只有附 evidence path、reviewer 與日期的項目才可勾選。

## SRR — System Requirements Review

- [ ] 系統邊界固定為 PCIe Gen3 x4、單一 M.2 2280 M-Key NVMe。
- [ ] Low-profile、half-length mechanical requirement 已由適用 CEM 文件確認。
- [ ] In-scope／out-of-scope 與不宣稱 PCIe compliance 的限制已簽核。
- [ ] 每個 requirement 具有來源、verification method 與 status。
- [ ] 5 A normal 與 7 A / 100 µs transient 已明示為 design stimulus。
- [ ] 所有實機結果仍為 `Not_Yet_Measured`，除非有原始量測 evidence。

## PDR — Architecture and Component Review

- [ ] Architecture A／B 比較的假設、權重與退出條件已 review。
- [ ] PCIe slot power／inrush boundary 已由 [PCI-SIG CEM 3.0](https://pcisig.com/PCIExpress/Specs/CEM/CardElectromechanical_3.0) 確認。
- [ ] TPS543620 operating point、switching frequency、inductor、Cin、Cout、feedback、soft-start 與 thermal 已計算。
- [ ] TPS25947 exact orderable MPN、latch-off／auto-retry、PG／FLT、current limit、timer 與 slew 已確認。
- [ ] INA238 shunt range、calibration、error budget 與 Kelvin connection 已確認。
- [ ] TMP1075 address、placement 與量測語意已確認。
- [ ] MDT420M01501 與 MDT320M01001 exact drawings／3D files 可追溯。
- [ ] `pcb/3d_model_mapping.csv` 的 critical model hash、datum、transform與 collision evidence通過 `check_3d_models.py`。
- [ ] 每個實裝料具有 lifecycle、datasheet status、footprint status 與 alternative。
- [ ] Top risks 有 owner、mitigation 與 closure evidence。

## Gate 1 — Pin Mapping Freeze

- [ ] PCIe edge 與 M.2 connector 的 orientation／view definition 已鎖定。
- [ ] Lane 0–3 的 TX/RX direction 已以 host 與 device 視角交叉確認。
- [ ] 每組 differential pair 的 P/N polarity 已確認。
- [ ] REFCLK P/N 已確認。
- [ ] PERST#、CLKREQ#、PEWAKE# 的 direction、voltage domain 與 pull-up ownership 已確認。
- [ ] PRSNT pins／lane-width indication 已確認。
- [ ] M-Key pin definition 與 no-connect／reserved pins 已確認。
- [ ] AC coupling transmitter ownership 已確認，且 BOM 沒有重複 capacitor。
- [ ] 每個 critical row 具 governing spec 與第二份公開原廠設計 evidence。
- [ ] `check_duplicate_pins.py` 與 `check_net_names.py` 通過。
- [ ] `Pending_Human_Verification` critical pins 為 0。

## Schematic CDR

- [ ] 七頁 hierarchy 與 page-to-page ports 一致。
- [ ] Symbols 以 exact datasheet pinout 建立並完成 independent check。
- [ ] Power net、signal net、sideband、test point 命名符合規則。
- [ ] eFuse／buck compensation or internally compensated design、enable、PG、fault path 完整。
- [ ] I²C address、pull-ups、header pinout 與 back-power prevention 完整。
- [ ] Test points 可量測 input、protected 12 V、3.3 V、PGOOD、I²C 與 GND。
- [ ] Annotation、BOM、connection matrix 與 footprint assignment 一致。
- [ ] ERC 無未解釋 error／warning。
- [ ] Native project 可關閉後重新開啟，且 netlist 可重建。

## Gate 2 — Power Design Freeze

- [ ] Target SSD official power information 或明確 restricted envelope 已建立。
- [ ] Slot input、eFuse、buck、shunt 與 connector 的 steady-state power budget 已閉合。
- [ ] 5 A case 包含 efficiency、loss、junction／board temperature 與 derating。
- [ ] 7 A / 100 µs case 包含 inductor current、current limit、Cout droop 與 recovery。
- [ ] MLCC DC-bias、tolerance、temperature 與 aging 影響已納入。
- [ ] Inductor saturation、RMS current 與 thermal rating 已確認。
- [ ] Shunt power、pulse、TCR 與 INA238 full-scale 均有 margin。
- [ ] eFuse startup SOA 與 fault recovery sequence 已確認。
- [ ] Gate failure 時的 Architecture A／restricted SSD fallback 已決策。

## PSpice Review

- [ ] Vendor model URL、revision、download date 與 hash 已保存。
- [ ] Vendor example circuit 可在本機重現，或已記錄 limitation。
- [ ] Startup、input ramp、soft-start、inrush profiles 已建立。
- [ ] 10→100% load step 與 100→10% release 已建立。
- [ ] 7 A / 100 µs pulse 已建立且條件清楚。
- [ ] Line transient、ripple、inductor current、switch-node 與 PGOOD 已建立。
- [ ] Tolerance／derating profiles 已建立。
- [ ] 每個 profile 有 time step、stop time、probe、criteria 與 expected behavior。
- [ ] Loop stability／Monte Carlo 若模型或 license 不支援，已標為 `Not_Supported_By_Model`。
- [ ] 所有圖表標為 `Simulated`，且不描述成 measured。

## Gate 3 — PCB Constraint Freeze

- [ ] 投板當下 JLCPCB 1.6 mm 六層 stack-up 與 quote evidence 已保存。
- [ ] Differential impedance geometry 由 [JLCPCB calculator](https://jlcpcb.com/help/article/user-guide-to-the-jlcpcb-impedance-calculator) 與 governing spec 決定。
- [ ] L1/L2 與 L6/L5 reference 關係已確認。
- [ ] Pair spacing、intra-pair skew、length、via count 與 layer-transition rule 已輸入 Constraint Manager。
- [ ] Plane-crossing prohibition 與 return-via rule 已輸入。
- [ ] Power current／width rules 已由 copper temperature-rise estimate 支持。
- [ ] Constraint export 可追溯至 source table，無 silent default。

## Placement and Routing Review

- [ ] Board outline、edge-finger datum、bracket、M.2 connector、2280 standoff 與 keepout 已確認。
- [ ] 1:1 connector／standoff print check 已完成。
- [ ] SSD top／bottom component envelope 與 chassis clearance 已確認。
- [ ] PCIe breakout 短、直、對稱，pair 無不必要 layer change。
- [ ] 每個 high-speed transition 有鄰近 GND return vias。
- [ ] Pair 無跨 plane split、void 或 reference discontinuity。
- [ ] Buck Cin–switch–inductor–Cout hot loop 最小化。
- [ ] Switch-node copper 受控並遠離 PCIe lane／telemetry sense。
- [ ] Shunt high-current path 與 Kelvin sense 分離。
- [ ] Thermal vias、copper spreading 與 solder-mask intent 已 review。
- [ ] Test points 在裝上 SSD／bracket 後仍可接近。
- [ ] DRC、unconnected report、return-path review 與 power-layout review 無未解釋項。

## Manufacturing Release Review

- [ ] Gerber／ODB++ output 只由實際可用 license 產生。
- [ ] NC Drill、IPC netlist、BOM、P&P、assembly drawing 與 fabrication notes 版本一致。
- [ ] CAM preview 檢查 board outline、drill、mask、paste、legend、edge fingers 與 slots。
- [ ] Controlled-impedance notes 與 stack-up revision 一致。
- [ ] DNI、polarity、pin-1、connector／standoff assembly notes 清楚。
- [ ] AVL 與 lifecycle 在 release date 重新確認。
- [ ] Release archive 具有 revision、date、manifest 與 checksum。

## Bring-up Readiness Review

- [ ] Visual inspection、short check 與 current-limited startup 順序已寫入 traveler。
- [ ] 無 SSD 上電的 voltage、current、PGOOD、ripple criteria 已定義。
- [ ] SSD 安裝後的 inrush／steady-state criteria 已定義。
- [ ] Linux `lspci -vv`、`nvme-cli`、`fio`、`smartctl`、`dmesg` evidence 保存方式已定義。
- [ ] Windows Device Manager、HWiNFO、CrystalDiskInfo／Mark 只作輔助證據。
- [ ] Cold boot、warm boot、不同 SSD 與 thermal stress test matrix 已定義。
- [ ] Fault tree、debug log 與 ECO template 可用。
- [ ] 未執行項目保持 `Planned`／`Not_Yet_Measured`。

## Portfolio Claim Audit

- [ ] README、slides、resume 與口頭稿沒有「PCIe compliant」或等價誤導。
- [ ] 每個數字可連回 official source、calculation、simulation 或 measurement。
- [ ] `Estimated`、`Simulated` 與 `Not_Yet_Measured` 在圖表標題／caption 可見。
- [ ] 未完成 Gate 與設計限制被主動揭露。
- [ ] 面試回答能說明 trade-off、failure mode、verification method 與 ECO path，而非只背規格值。

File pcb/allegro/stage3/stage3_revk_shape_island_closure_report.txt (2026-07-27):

AUDIT|STAGE3_REVK_SHAPE_ISLAND_CLOSURE|25.1_S040
SOURCE_REVJ_POWER_PLANES_SHA256|8B6D0C33D19083539C2BB4A085946B1B7E497F232747259FB62230CDA859069F
VIA_PADSTACK|S3_VIA_D0P20_P0P45|DRILL_MM|0.20|PAD_MM|0.45
VIA|P3V3_NVME|(31.4278 42.7)|(ETCH/TOP ETCH/BOTTOM)
VIA|P3V3_NVME|(99.0 61.0)|(ETCH/TOP ETCH/BOTTOM)
VIA|P3V3_PRE_SENSE|(83.7 49.55)|(ETCH/TOP ETCH/BOTTOM)
P3V3_NVME_N_BRANCHES|1
P3V3_PRE_SENSE_N_BRANCHES|1
P3V3_NVME_UNCONNECTED|0
P3V3_PRE_SENSE_UNCONNECTED|0
DRC_STATE|t
DRC_COUNT|0
FINAL_VIA_GEOMETRY|Pending_Fabricator_Confirmation
FAB_READY_CLAIM|PROHIBITED

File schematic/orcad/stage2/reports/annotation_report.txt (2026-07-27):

Stage 2 Capture Annotation Audit
Tool interface: OrCAD Capture 25.1 DBO/ISCF batch after native GUI ERC
DSN: C:/project/orcad_project/nvidia-lde-orcad-portfolio/schematic/orcad/stage2/native_25_1/PCIE_GEN3_X4_NVME_ADAPTER_REVA_STAGE2_ELECTRICAL.dsn
DSN_SHA256: 64261FAF970518F368E9EF253A3A45221CCB31A39DCB3D761A88AD4A55D0320C
Annotated_Reference_Count: 61
Unique_Reference_Count: 61
02_PCIE_EDGE_INTERFACE: 1
03_M2_NVME_INTERFACE: 1
04_POWER_INPUT_PROTECTION: 11
05_3V3_POWER: 22
06_POWER_TELEMETRY: 8
07_DEBUG_AND_TESTPOINTS: 18
Result: PASS

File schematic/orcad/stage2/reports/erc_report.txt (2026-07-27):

Stage 2 Electrical Connectivity and ERC Audit
Method: OrCAD Capture 25.1 S040 native GUI ERC + DBO reopen + ISCF connectivity audit
Native Capture GUI ERC: Executed_2026-07-24_21:00_Asia_Taipei
ERC_Report: schematic/orcad/stage2/native_25_1/PCIE_GEN3_X4_NVME_ADAPTER_REVA_STAGE2_ELECTRICAL.DRC
ERC_Report_SHA256: D0043343B76331BD9B987E3013F9A86B03B905B07D3A7DA215F26813708F8814
ERC_Error_Records: 0
ERC_Warning_Records: 0
Post_ERC_DBO_Page_Count: 7
Post_ERC_DBO_Part_Instance_Count: 61
Native_DSN_SHA256: 64261FAF970518F368E9EF253A3A45221CCB31A39DCB3D761A88AD4A55D0320C
Controlled PCI-SIG/M.2 governing specifications: Access_Exception_Documented
Expected_Design_Nets: 53
Actual_ISCF_Nets: 54
Physical_Pin_Endpoints: 251
Missing_Design_Nets: NONE
Documented_Extra_Nets: P3V3_SLOT_UNUSED
P3V3_SLOT_UNUSED disposition: intentionally isolated J1 slot-power contacts
Scope_Limitation: ERC result covers configured Capture electrical and physical rules only
Compliance/Fab-ready claim: PROHIBITED
Result: PASS_WITH_DOCUMENTED_LIMITATIONS

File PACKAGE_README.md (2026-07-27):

# NVIDIA LDE OrCAD RevK interview package

Status：`Interview_Digital_Complete`

Fabrication_Ready：`false`

This archive is the curated interview handoff for the RevK native Allegro board. It includes the current board database, reusable SKILL sources, package/STEP mapping library, Capture reports, PSpice raw recovery evidence, current-board 3DX captures, portfolio views and engineering manufacturing exports.

Primary board SHA-256：

`C772E9C3CD7A04A2CE3FBD1F5AE659E0935B786B235B17354DB83371BB4FF3EA`

Important limitations：

- Do not upload this archive to a PCB fabricator.
- Differential-pair impedance geometry is still `Pending_Fabricator_Confirmation`.
- PCIe CEM／M.2 controlled-spec sign-off is incomplete.
- PSpice governing recovery is a disclosed 3.109 V failure; the 27 candidate cases were runtime-limited.
- Exact mechanical context and physical bring-up are not complete.
- IPC-356 zero-byte output is excluded; its console log is retained under diagnostics.
- ODB++ is `Not_Supported_By_Installed_Tool`; IPC-2581-C is included.

Start with the root `README.md`, then review:

1. `evidence/stage3/stage3_delivery_gate.md`
2. `evidence/stage3/constraint_manager_status.md`
3. `manufacturing/stage3_final_revk/README.md`
4. `manufacturing/stage3_final_revk/artifact_manifest.csv`
5. `validation/stage3_fabrication_and_bringup_gate.md`

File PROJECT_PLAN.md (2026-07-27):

# 專案執行計畫

## 目標與成功條件

目標是在八週內建立一套可審查、可追溯、可由 Cadence native flow 延伸至投板的 Rev A 設計作品集。成功不以「文件很多」判定，而以需求閉環、design gate、可重現工具輸出與誠實的證據狀態判定。

成功條件：

1. PCIe Gen3 x4、M.2 M-Key、sideband 與 power connectivity 均可追溯至來源。
2. 5 A steady-state 與 7 A / 100 µs transient stimulus 均有計算、PSpice 設定與 pass/fail criteria。
3. 六層 stack-up、impedance geometry 與 routing constraints 由投板當下板廠資料凍結。
4. OrCAD、PSpice、PCB 與製造輸出均能由同一版 source data 重建。
5. 實機未測項目持續標為 `Not_Yet_Measured`，不宣稱 compliance。

## 八週工作分解

| 時程 | 工作包 | 可交付成果 | Gate／驗收 |
|---|---|---|---|
| Week 1 | Repository baseline | 核心文件、CSV schema、初版 BOM／net matrix／constraints、四個檢查器 | 檔案 manifest 完整；valid fixtures 通過；negative fixtures 正確失敗 |
| Week 1–2 | Architecture and power definition | A/B trade-off、推薦與備選料、power／thermal／derating 計算 | Power Design Gate；slot power 與 exact MPN 已確認 |
| Week 2–3 | OrCAD Capture | 七頁階層式 schematic、symbols、footprints、ERC、netlist | Pin Mapping Gate；native project round-trip；ERC 無未解釋項 |
| Week 3–4 | PSpice | startup、inrush、load／line transient、ripple、tolerance profiles | 每個 profile 可重現；結果只依實際 run 標為 `Simulated` |
| Week 4–6 | PCB implementation | outline、placement、stack-up、constraints、routing reviews、DRC | PCB Constraint Gate；return path、mechanical、DRC 全數審查 |
| Week 6–7 | Release and bring-up preparation | Gerber、drill、BOM、P&P、assembly、release package、test plan | CAM／release checklist 通過；未下板項目為 `Planned` |
| Week 7–8 | Portfolio packaging | 10 頁簡報、三種 pitch、履歷 bullets、問答、project story | 技術主張皆可連回文件或工具證據 |

## Design gates

### Gate 1 — Pin Mapping Freeze

通過條件：

- PCIe edge 與 M.2 connector 的 lane 0–3、P/N、TX/RX direction 已逐 pin 覆核。
- REFCLK、PERST#、CLKREQ#、PEWAKE# 與 PRSNT 已確認。
- AC coupling capacitor ownership 已由 governing specification 確認；本板沒有未經證實的額外 coupling。
- 每個 critical row 都有 official source 與第二份公開原廠設計交叉檢查。
- `Pending_Human_Verification` 數量為 0，且 reviewer／日期留痕。

未通過時：不得進行正式 Capture 接線或宣稱 pin map 正確。

### Gate 2 — Power Design Freeze

通過條件：

- PCIe slot 12 V pin、available power、inrush／hot-plug 邊界由正式 CEM 資料確認。
- exact TPS25947-family MPN、fault response、current limit、slew rate 與 thermal SOA 已決定。
- 5 A steady-state 與 7 A / 100 µs stimulus 的 input、output、inductor、shunt、loss、temperature rise 與 derating 已計算。
- TPS543620 transient model 已保存版本、URL、取得日期與 hash。
- 支援的 SSD 清單與排除條件已建立；超出 verified envelope 的 SSD 不列為支援。

未通過時：限制支援範圍，不以 6 A nominal rating 推論 7 A transient 能力。

### Gate 3 — PCB Constraint Freeze

通過條件：

- 投板當下的 JLCPCB 1.6 mm 六層 stack-up 與 impedance calculator evidence 已保存。
- differential impedance、trace geometry、reference layer、via rule、spacing、skew 與 length rule 已由適用規格及 stack-up 共同決定。
- L1/L2 與 L6/L5 reference relationship 無 plane split；layer transition 有鄰近 return vias。
- high-current loop、switch-node keepout、Kelvin sense、thermal via 與 test-point access 已審查。

未通過時：所有 geometry 維持 `Pending_Fabricator_Confirmation`，不得 release。

## 執行順序與相依性

```mermaid
flowchart LR
    R["Requirements + source log"] --> A["Architecture decision"]
    A --> P["Power calculations"]
    R --> M["Pin mapping"]
    P --> G2{"Power Gate"}
    M --> G1{"Pin Gate"}
    G1 --> S["OrCAD schematic"]
    G2 --> S
    S --> PS["PSpice profiles"]
    S --> C["PCB constraints"]
    C --> G3{"Constraint Gate"}
    G3 --> L["Placement + routing"]
    PS --> RV["Release review"]
    L --> RV
    RV --> B["Planned bring-up"]
    RV --> I["Interview package"]
```

## 工作紀律

- 每項結論都先記錄 source、assumption 與 status，再進入 CAD。
- 每個里程碑只升級有證據的狀態；`Planned` 不等於 `Simulated`，`Simulated` 不等於 measured。
- 任何 model convergence failure、tool limitation 或 license limitation 都保存 log，不補畫波形。
- Native Cadence files 只由已驗證的 GUI／batch flow 產生；Tcl／SKILL automation 若使用，標為 experimental 並保留人工覆核。
- 任一變更若影響需求、pin mapping、power、constraint 或 manufacturing output，必須記錄於 `CHANGELOG.md` 並重新跑受影響的 gate。

## 發行判定

Rev A 只有在三個 Gate、ERC、PSpice review、DRC、footprint／mechanical review 與 CAM checklist 全數無未解釋項目時才可標記 `Release_Candidate`。是否製作實體板是另一個決策；未製作時，bring-up 與量測仍維持 `Planned`／`Not_Yet_Measured`。

## 2026-07-23 Gate snapshot

- Gate 1 未通過：NVIDIA 公開資料已提供 lane／sideband 候選交叉檢查，但 CEM 3.0
  的 B12 為 reserved，而較新設計把它用作 `CLKREQ#`；M.2 pin 32 也有 GND／NC
  revision 差異。所有 critical physical Pin 繼續保持 `PENDING_*`。
- Gate 2 未通過：TPS543620 與 TPS25947x 官方 PSpice ZIP、版本與 SHA-256 已保存，
  但 isolated TPS25947x smoke test 功能驗收失敗；slot power、inrush、eFuse 設定與
  7 A／100 µs canonical transient 尚未關閉。
- Gate 3 未通過：JLCPCB 當期 quote／stack-up／calculator evidence 尚未凍結，
  geometry 繼續為 `Pending_Fabricator_Confirmation`。
- Capture executable 與可見 license 已確認；Rev A native save／reopen／ERC／netlist
  round-trip 尚未完成。

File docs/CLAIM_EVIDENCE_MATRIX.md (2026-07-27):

# Claim / evidence matrix

語言 / Language：[`繁體中文版`](CLAIM_EVIDENCE_MATRIX_ZH.md)｜English canonical version is this file

Status vocabulary: `VERIFIED` = directly supported by a current repository artifact; `PRELIMINARY` = design intent or review evidence, not a released qualification; `SIMULATION-LIMITED` = a recorded simulation result with model/runtime boundary; `BLOCKED` = a required input or gate is missing; `OPEN` = not yet measured or not concluded.

| Claim | Status | Why it matters | Evidence path | What it proves | What it does not prove |
|---|---|---|---|---|---|
| The board is a passive PCIe-to-M.2 physical interposer, not a protocol converter | VERIFIED | Prevents an incorrect system description | [`docs/interface_definition.md`](interface_definition.md) | Host and SSD remain protocol endpoints; logical lanes and sidebands are defined | Successful host enumeration or protocol compliance |
| Architecture B is 12 V slot input → eFuse → synchronous buck → shunt → 3.3 V SSD | PRELIMINARY | Shows the power trade-off and review boundary | [`docs/architecture_tradeoff.md`](architecture_tradeoff.md), [`docs/system_block_diagram.md`](system_block_diagram.md) | Selected topology and rationale | Closed component settings or bench power performance |
| Six-layer 120 × 64 mm low-profile baseline exists | PRELIMINARY | Defines the mechanical/electrical design envelope | [`evidence/stage3/final_release_status.md`](../evidence/stage3/final_release_status.md), [`evidence/stage3/3d_status.md`](../evidence/stage3/3d_status.md) | Current native board baseline | CEM-controlled outline, chassis fit, or fabrication release |
| Current RevK native board reports DRC=0, unconnected=0, active rats=0 and shape islands=0 | VERIFIED | Demonstrates digital PCB closure | [`evidence/stage3/stage3_delivery_gate.md`](../evidence/stage3/stage3_delivery_gate.md) | These current-board report counters | SI/PI, manufacturability, or electrical performance |
| Eight data pairs plus one REFCLK pair are defined | VERIFIED | Makes high-speed intent reviewable | [`pcb/differential_pairs.csv`](../pcb/differential_pairs.csv), [`evidence/stage3/constraint_manager_status.md`](../evidence/stage3/constraint_manager_status.md) | Nine logical/native pair objects exist | Frozen impedance geometry or routed eye quality |
| PCIe lane, sideband and power logical names are complete | PRELIMINARY | Provides a stable source interface | [`schematic/connection_matrix.csv`](../schematic/connection_matrix.csv), [`docs/interface_definition.md`](interface_definition.md) | P/N naming and net intent | Correct physical J1/J2 pin numbers |
| Critical J1/J2 physical pin mapping is frozen | BLOCKED | Incorrect pin mapping can damage function or violate the spec | [`docs/pcie_m2_pin_mapping.md`](pcie_m2_pin_mapping.md) | The unresolved conflict is documented | Any claim that B12/Pin32 or all critical pins are confirmed |
| No extra lane AC caps, termination, CMC or ESD are inserted | PRELIMINARY | Avoids changing transmitter ownership before source review | [`docs/interface_definition.md`](interface_definition.md) | Current design choice | That the choice is compliant under every CEM/M.2 revision |
| 3.3 V / 5 A is the normal design target | PRELIMINARY | Establishes the power sizing target | [`docs/power_budget.md`](power_budget.md), [`docs/component_selection.md`](component_selection.md) | Engineering target and calculation basis | Qualified continuous SSD support |
| 7 A / 100 µs is an engineering transient pulse | SIMULATION-LIMITED | Tests transient headroom above the nominal target | [`pspice/stage2/profile_results.csv`](../pspice/stage2/profile_results.csv) | A recorded profile and threshold window | A supported SSD power envelope or thermal endurance |
| Startup, 5 A, 7 A and PGOOD windows were run with the official buck macro-model | SIMULATION-LIMITED | Shows a repeatable power-analysis workflow | [`pspice/stage2/profile_results.csv`](../pspice/stage2/profile_results.csv) | Raw profile dispositions and observations | Layout parasitics, thermal behavior, or silicon guarantee |
| The completed 88 µF official-model run reaches 3.109 V in recovery | SIMULATION-LIMITED | A visible failure is more credible than a hidden pass | [`pspice/stage2/profile_results.csv`](../pspice/stage2/profile_results.csv) | Recovery screen failure and retained diagnostic | A final capacitor recommendation or stable design |
| The 27-corner COUT/ESR/CFF sweep concluded | OPEN | Prevents overclaiming a tuning result | [`pspice/stage3/recovery_sweep/recovery_sweep_results.csv`](../pspice/stage3/recovery_sweep/recovery_sweep_results.csv), [`pspice/stage3/run_record.md`](../pspice/stage3/run_record.md) | Cases, hashes and runtime-limited dispositions | Any sweep pass/fail closure |
| The TPS25947x eFuse behavior is validated | BLOCKED | Inrush and fault protection are system safety gates | [`pspice/stage2/profile_results.csv`](../pspice/stage2/profile_results.csv) | The public profile table records `Fail_Functional_Validation` and its limitation | Current-limit, latch-off, SOA or inrush proof |
| INA238 and TMP1075 telemetry paths are designed | PRELIMINARY | Demonstrates observability and debug intent | [`docs/interface_definition.md`](interface_definition.md), [`schematic/connection_matrix.csv`](../schematic/connection_matrix.csv) | Shunt/temperature/I²C source paths | Correct address, firmware, calibration, or measured telemetry |
| Native 3DX screenshots are tied to the current board | VERIFIED | Makes the visual portfolio traceable | [`evidence/stage3/3dx_native_revk/`](../evidence/stage3/3dx_native_revk/), [`evidence/stage3/3d_status.md`](../evidence/stage3/3d_status.md) | RevK board status and native view evidence | Exact host chassis or connector mating fit |
| Assembly STEP exports in AP242/mm and re-imports into an isolated native DRA | VERIFIED | Demonstrates an MCAD handoff loop | [`evidence/stage3/3d_status.md`](../evidence/stage3/3d_status.md), [`manufacturing/stage3_final_revk/pcie_gen3_x4_nvme_adapter_reva_revk_final_preliminary.step`](../manufacturing/stage3_final_revk/pcie_gen3_x4_nvme_adapter_reva_revk_final_preliminary.step) | Units/orientation/readback record | Exact model transforms or production mechanical acceptance |
| All 3D collision cases pass | BLOCKED | Collision proof depends on exact models and rules | [`evidence/stage3/3d_status.md`](../evidence/stage3/3d_status.md), [`pcb/3d_model_mapping.csv`](../pcb/3d_model_mapping.csv) | Preliminary/blocked dispositions are recorded | A `Pass` for missing exact models |
| Gerber, NC Drill and IPC-2581-C are generated | VERIFIED | Shows digital manufacturing-output generation | [`manufacturing/stage3_final_revk/export_status.csv`](../manufacturing/stage3_final_revk/export_status.csv), [`manufacturing/stage3_final_revk/README.md`](../manufacturing/stage3_final_revk/README.md) | Files exist with export records | DFM approval or a board-house quote |
| ODB++ is complete and IPC-356 is usable | OPEN | Prevents a false manufacturing-format claim | [`manufacturing/stage3_final_revk/export_status.csv`](../manufacturing/stage3_final_revk/export_status.csv) | ODB++ unsupported and IPC-356 empty are disclosed | Any claim that those formats were delivered |
| Supported SSD list is qualified | PRELIMINARY | Limits the user-facing product claim | [`validation/supported_ssd_matrix.csv`](../validation/supported_ssd_matrix.csv) | Reference-policy structure and constraints | Universal SSD compatibility or bench qualification |
| CSV validators and negative fixtures are repeatable | VERIFIED | Shows rule-driven design automation | [`scripts/validate_csv.py`](../scripts/validate_csv.py), [`scripts/test_validators.py`](../scripts/test_validators.py), [`scripts/testdata/`](../scripts/testdata/) | Schema/negative-test behavior | Correctness of native binary databases or board performance |
| Fabrication-ready release exists | BLOCKED | Separates interview closure from a board-house release | [`evidence/stage3/final_release_status.md`](../evidence/stage3/final_release_status.md), [`manufacturing/stage3_final_revk/README.md`](../manufacturing/stage3_final_revk/README.md) | The explicit false status and blockers | That the board can be uploaded without ECO/DFM review |
| Physical enumeration, Gen3 x4 link, NVMe identify and thermal results exist | OPEN | These are the final hardware validation steps | [`PROJECT_PLAN.md`](../PROJECT_PLAN.md), [`VALIDATION_STATUS.md`](../VALIDATION_STATUS.md) | The gap is acknowledged | Any measured hardware outcome |

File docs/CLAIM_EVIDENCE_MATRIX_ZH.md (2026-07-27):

# Claim / Evidence Matrix（繁體中文）

English version：[`CLAIM_EVIDENCE_MATRIX.md`](CLAIM_EVIDENCE_MATRIX.md)

狀態定義：`VERIFIED` = 有目前 repository artifact 直接支持；`PRELIMINARY` = 設計意圖或初步審查；`SIMULATION-LIMITED` = 有模型／runtime 邊界的模擬結果；`BLOCKED` = 必要輸入或 gate 缺少；`OPEN` = 尚未量測或尚未結論。

| Claim | 狀態 | 為何重要 | Evidence | 證明什麼 | 不證明什麼 |
|---|---|---|---|---|---|
| 板子是 passive PCIe-to-M.2 physical interposer，不是 protocol converter | VERIFIED | 避免錯誤描述系統功能 | [`docs/interface_definition.md`](interface_definition.md) | Host 與 SSD 仍是協定端點 | 成功 enumeration 或 compliance |
| Architecture B 為 12 V → eFuse → buck → shunt → 3.3 V | PRELIMINARY | 說明電源 trade-off | [`docs/architecture_tradeoff.md`](architecture_tradeoff.md) | topology 與選擇理由 | 完整元件設定或 bench performance |
| 六層、120 × 64 mm、1.6 mm nominal baseline 存在 | PRELIMINARY | 定義設計 envelope | [`evidence/stage3/final_release_status.md`](../evidence/stage3/final_release_status.md) | 目前 native baseline | CEM outline、chassis fit、fab release |
| RevK native board DRC=0、unconnected=0、active rats=0、shape islands=0 | VERIFIED | 證明 digital PCB closure | [`evidence/stage3/stage3_delivery_gate.md`](../evidence/stage3/stage3_delivery_gate.md) | 目前 board counters | SI/PI、製造性或電氣性能 |
| 有八組 data pairs 加一組 REFCLK pair | VERIFIED | 讓高速意圖可審查 | [`pcb/differential_pairs.csv`](../pcb/differential_pairs.csv) | 九組 logical/native pair objects | Frozen impedance 或 eye quality |
| PCIe lane、sideband、power logical names 完整 | PRELIMINARY | 提供穩定 source interface | [`schematic/connection_matrix.csv`](../schematic/connection_matrix.csv) | P/N naming 與 net intent | J1/J2 正確 physical pin numbers |
| J1/J2 critical physical pins 已 freeze | BLOCKED | 錯誤 mapping 會破壞功能 | [`docs/pcie_m2_pin_mapping.md`](pcie_m2_pin_mapping.md) | B12/Pin32 conflict 被記錄 | 所有 pin 已 Confirmed |
| 沒有加入 lane AC caps、termination、CMC、ESD | PRELIMINARY | 保留 transmitter ownership | [`docs/interface_definition.md`](interface_definition.md) | 目前設計選擇 | 所有規格版本下的 compliance |
| 3.3 V / 5 A 是 normal design target | PRELIMINARY | 定義 power sizing | [`docs/power_budget.md`](power_budget.md) | engineering target | qualified continuous SSD support |
| 7 A / 100 µs 是 transient pulse study | SIMULATION-LIMITED | 測試 transient headroom | [`pspice/stage2/profile_results.csv`](../pspice/stage2/profile_results.csv) | profile 與 threshold window | supported SSD power rating |
| Startup、5 A、7 A、PGOOD profile 已執行 | SIMULATION-LIMITED | 顯示可重複的 power analysis | [`pspice/stage2/profile_results.csv`](../pspice/stage2/profile_results.csv) | raw disposition 與觀察 | layout parasitics、thermal、silicon guarantee |
| 88 µF official-model recovery 到 3.109 V | SIMULATION-LIMITED | failure 沒有被隱藏 | [`pspice/stage2/profile_results.csv`](../pspice/stage2/profile_results.csv) | recovery screen failure | final capacitor recommendation |
| 27-case COUT/ESR/CFF sweep 已結案 | OPEN | 防止誤稱 tuning pass | [`pspice/stage3/recovery_sweep/recovery_sweep_results.csv`](../pspice/stage3/recovery_sweep/recovery_sweep_results.csv) | cases、hash、runtime disposition | sweep pass/fail closure |
| TPS25947x eFuse behavior 已 validation | BLOCKED | inrush/fault 是安全 gate | [`pspice/stage2/profile_results.csv`](../pspice/stage2/profile_results.csv) | `Fail_Functional_Validation` | current-limit、latch-off、SOA proof |
| INA238/TMP1075 telemetry paths 已設計 | PRELIMINARY | 建立 observability | [`docs/interface_definition.md`](interface_definition.md) | shunt/temp/I²C paths | address、calibration、measured telemetry |
| Native 3DX screenshots 綁定目前 board | VERIFIED | 讓視覺 evidence 可追溯 | [`evidence/stage3/3dx_native_revk/`](../evidence/stage3/3dx_native_revk/) | RevK status 與 native views | exact host/chassis mating fit |
| AP242/mm STEP 可 export 且可 isolated re-import | VERIFIED | 證明 MCAD handoff loop | [`evidence/stage3/3d_status.md`](../evidence/stage3/3d_status.md) | units/orientation/readback | exact transforms 或 production acceptance |
| 所有 3D collision cases 都 Pass | BLOCKED | 需要 exact model/rule | [`evidence/stage3/3d_status.md`](../evidence/stage3/3d_status.md) | preliminary/blocked dispositions | 缺模型時的 Pass |
| Gerber、NC Drill、IPC-2581-C 已生成 | VERIFIED | 證明 digital manufacturing output | [`manufacturing/stage3_final_revk/export_status.csv`](../manufacturing/stage3_final_revk/export_status.csv) | files 與 export records | DFM approval 或 board-house quote |
| ODB++ 完整且 IPC-356 可用 | OPEN | 防止格式 overclaim | [`manufacturing/stage3_final_revk/export_status.csv`](../manufacturing/stage3_final_revk/export_status.csv) | 不支援／空檔已揭露 | 這兩種格式已交付 |
| Supported SSD list 已 qualification | PRELIMINARY | 限制產品聲明 | [`validation/supported_ssd_matrix.csv`](../validation/supported_ssd_matrix.csv) | reference-policy structure | universal compatibility 或 bench qualification |
| CSV validators 與 negative fixtures 可重複 | VERIFIED | 展示 rule-driven automation | [`scripts/`](../scripts/) | schema/negative-test behavior | native binary correctness 或 board performance |
| Fabrication-ready release 已存在 | BLOCKED | 區分 interview closure 與板廠 release | [`evidence/stage3/final_release_status.md`](../evidence/stage3/final_release_status.md) | 明確 false status 與 blockers | 可直接下單 |
| Physical enumeration、Gen3 x4、NVMe identify、thermal 已完成 | OPEN | 這是最終硬體驗證 | [`PROJECT_PLAN.md`](../PROJECT_PLAN.md) | gap 被承認 | 任何 measured hardware outcome |

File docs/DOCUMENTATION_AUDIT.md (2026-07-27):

# Documentation audit — NVIDIA LDE OrCAD portfolio

語言 / Language：[`繁體中文版`](DOCUMENTATION_AUDIT_ZH.md)｜[`English full version`](DOCUMENTATION_AUDIT_EN.md)

Audit date: 2026-07-27  
Scope: public repository at `ErenYagar/nvidia-lde-orcad-portfolio`  
Method: repository file inventory, path checks, evidence/status review, claim scan, and validator execution.

## 1. What the repository is

This is a self-directed, interview-oriented PCB system-design case study for a six-layer PCIe Gen3 x4 add-in card that provides a physical PCIe-to-M.2 M-Key 2280 NVMe connection. The board does not translate PCIe protocol, enumerate a device by itself, or contain a PCIe switch/retimer. The host Root Complex and the NVMe controller remain the protocol endpoints; the board contributes connector pin mapping, power delivery, telemetry, placement, constraints, mechanical review, and release automation.

The current public baseline is Rev K / RevK evidence with status `Interview_Digital_Complete_Not_For_Fabrication`. The repository deliberately keeps native design artifacts and evidence close to the explanation, while excluding private credentials, personal contact data, and oversized/private simulation binaries.

## 2. Evidence that is already strong

| Area | Current evidence | Audit reading |
|---|---|---|
| System intent | [`docs/interface_definition.md`](interface_definition.md), [`docs/system_block_diagram.md`](system_block_diagram.md) | Clear host/edge/M.2/SSD/power/telemetry boundaries; passive interposer is explicit. |
| Architecture choice | [`docs/architecture_tradeoff.md`](architecture_tradeoff.md) | Options, weighted trade-off, selected 12 V + eFuse + buck chain, and exit conditions are recorded. |
| Component reasoning | [`docs/component_selection.md`](component_selection.md) | Official links, candidates, alternatives, and assumptions are separated. |
| Capture/electrical interface | [`schematic/connection_matrix.csv`](../schematic/connection_matrix.csv), [`schematic/symbol_pinmap.csv`](../schematic/symbol_pinmap.csv), [`schematic/orcad/stage2/reports/erc_report.txt`](../schematic/orcad/stage2/reports/erc_report.txt) | Reviewable machine-readable source tables and native-tool reports exist. |
| Power simulation | [`pspice/stage2/profile_results.csv`](../pspice/stage2/profile_results.csv), [`pspice/stage3/run_record.md`](../pspice/stage3/run_record.md) | Results are recorded with limitations; the 3.109 V recovery failure is not hidden. |
| PCB closure | [`evidence/stage3/stage3_delivery_gate.md`](../evidence/stage3/stage3_delivery_gate.md), [`evidence/stage3/constraint_manager_status.md`](../evidence/stage3/constraint_manager_status.md) | Current board has native DRC/connectivity/shape closure and nine differential pairs; impedance freeze is not claimed. |
| 3D/MCAD | [`evidence/stage3/3d_status.md`](../evidence/stage3/3d_status.md), [`evidence/stage3/3dx_native_revk/`](../evidence/stage3/3dx_native_revk/) | Native 3DX screens and AP242/mm STEP round-trip are hash-bound to RevK. |
| Manufacturing outputs | [`manufacturing/stage3_final_revk/README.md`](../manufacturing/stage3_final_revk/README.md), [`manufacturing/stage3_final_revk/export_status.csv`](../manufacturing/stage3_final_revk/export_status.csv) | Gerber, NC Drill, IPC-2581, BOM and preliminary P&P are present, but the package is explicitly not a fab release. |
| Automation | [`scripts/validate_csv.py`](../scripts/validate_csv.py), [`scripts/test_validators.py`](../scripts/test_validators.py) and the other `check_*.py` scripts | CSV schemas, negative fixtures, and repeatable command-line checks make the evidence auditable. |

## 3. Missing or weak evidence (result-only gaps)

These are not documentation failures; they are genuine engineering gates that the current result does not close.

1. The governing PCIe CEM/M.2 controlled specifications are not available in the public package, so critical J1/J2 physical pin numbers remain `Pending_Human_Verification`. The documented B12/CLKREQ# and M.2 pin-32 conflict is intentionally not guessed.
2. JLCPCB's current controlled-impedance six-layer stack-up and calculator output are not frozen. Pair width/gap, via geometry, anti-pad, reference-layer, skew and back-drill values therefore remain pending.
3. Exact mechanical context is incomplete: host chassis, bracket drawing, standoffs, cable and mating J2/SSD models are not all controlled exact models. Collision records are preliminary or blocked, not Pass.
4. The governing official-model PSpice sequence contains a 3.109 V recovery minimum against a 3.135 V lower screen. The 27-corner sweep and 132 uF candidate were runtime-limited; they are not a pass.
5. The isolated TPS25947x smoke run did not reach a valid output startup. Consequently there is no closed eFuse inrush/current-limit/latch-off claim.
6. No physical board, oscilloscope, Bode/impedance measurement, thermal camera, NVMe enumeration, or Gen3 x4 bench result is included. DRC and simulation are not substitutes for those measurements.
7. IPC-356 was empty and excluded; ODB++ is unavailable in the installed tool. IPC-2581-C is included as the intelligent manufacturing exchange instead.

## 4. Missing design reasons

Several items are intentionally absent rather than forgotten:

- No PCIe AC-coupling capacitors, termination, CMC, or ESD parts were added because transmitter ownership and the controlled pin specification were not closed.
- No protocol converter, retimer, switch, firmware, or host-side enumeration logic is in the architecture because the requested function is a passive physical adapter.
- No universal-SSD statement is made because the power, mechanical, firmware, and thermal envelope has not been qualified across devices.
- No fabricated-board result is represented by a 3DX render; portfolio images are presentation views backed by the native board and status reports.
- Raw/oversized private artifacts are not copied into the public repository; the manifest records the public evidence boundary.

## 5. Repetition and overclaim risks found before this audit

The earlier documents repeated the same status vocabulary and limitation paragraph in several places without a single claim-to-evidence index. That made it easy for a reader to see `DRC=0` or `STEP exported` without immediately seeing what those facts do not prove. The new report, matrix and interview guide use the same links and explicitly separate `VERIFIED`, `PRELIMINARY`, `SIMULATION-LIMITED`, `BLOCKED`, and `OPEN`.

The following phrases must always be qualified in portfolio copy: `PCIe compliance`, `fabrication-ready`, `universal SSD`, `chassis compatibility`, `bench qualification`, `exact fit`, `SI sign-off`, and `thermal validation`. In this repository they are used only to state that the claim is not made or is still open.

## 6. Evidence not previously surfaced enough

The repository contains useful evidence that was easy to miss from the old README: the native ERC report, the nine-pair constraint status, the power/shape audit, the AP242 re-import result, the 27-case recovery-sweep manifest, the eFuse failed-validation record, and the negative CSV fixtures. The revised entry points link these artifacts directly instead of listing directories without context.

## 7. Documentation acceptance criteria

- A reader can answer what the board does, what it deliberately does not do, and where each important claim is proven within two clicks.
- Every quantitative claim in the report has a source/status link or is labeled an engineering assumption.
- Simulation failures and runtime limits remain visible.
- Portfolio language is suitable for an interview but never implies PCIe compliance, fabrication release, universal SSD support, chassis fit, or bench qualification.
- Existing Cadence binaries, board files, simulation logs, CAM files and evidence images are preserved byte-for-byte.

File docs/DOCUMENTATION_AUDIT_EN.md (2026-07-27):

# Documentation Audit (English)

繁體中文版：[`DOCUMENTATION_AUDIT_ZH.md`](DOCUMENTATION_AUDIT_ZH.md)｜Current master audit: [`DOCUMENTATION_AUDIT.md`](DOCUMENTATION_AUDIT.md)

Scope: public repository `ErenYagar/nvidia-lde-orcad-portfolio`. Method: file inventory, path checks, evidence/status review, claim scan and Python validators.

## 1. Repository position

This is an interview-oriented PCB system-design case study for a six-layer PCIe Gen3 x4 add-in card to M.2 M-Key 2280 NVMe physical interposer. It does not implement PCIe protocol conversion, a retimer, a switch or firmware. The engineering story connects system intent, pin/net interfaces, power assumptions, 3DX/STEP, CAM and automated checks.

The public baseline is Rev K / RevK evidence with status `Interview_Digital_Complete_Not_For_Fabrication`.

## 2. Strong evidence already present

| Area | Evidence | Audit conclusion |
|---|---|---|
| System intent | [`docs/interface_definition.md`](interface_definition.md), [`docs/system_block_diagram.md`](system_block_diagram.md) | Host, edge, M.2, SSD, power and telemetry boundaries are explicit |
| Architecture | [`docs/architecture_tradeoff.md`](architecture_tradeoff.md) | Options, selection rationale and exit conditions are recorded |
| Capture | [`schematic/connection_matrix.csv`](../schematic/connection_matrix.csv), ERC report | Machine-readable source and native reports are retained |
| PSpice | [`pspice/stage2/profile_results.csv`](../pspice/stage2/profile_results.csv) | The 3.109 V recovery failure is visible |
| PCB | [`evidence/stage3/stage3_delivery_gate.md`](../evidence/stage3/stage3_delivery_gate.md) | Native DRC/connectivity/shape closure and nine pair objects are evidenced |
| 3D/MCAD | [`evidence/stage3/3d_status.md`](../evidence/stage3/3d_status.md) | Native 3DX and AP242/mm STEP round-trip are hash-bound |
| Manufacturing | [`manufacturing/stage3_final_revk/README.md`](../manufacturing/stage3_final_revk/README.md) | Gerber, NC Drill, IPC-2581, BOM/P&P exist but are not a fab release |
| Automation | [`scripts/`](../scripts/) | Schema, negative fixtures and command-line checks are repeatable |

## 3. Genuine open engineering evidence

1. Controlled PCIe CEM/M.2 specifications are not included; J1/J2 physical pins remain `Pending_Human_Verification`.
2. The current JLCPCB stack-up and impedance width/gap/via geometry are not frozen.
3. Exact host chassis, bracket, standoff, cable, J2 and SSD models are incomplete; collisions remain preliminary or blocked.
4. The official buck model reaches 3.109 V in recovery against a 3.135 V screen; the 27-case sweep is runtime-limited.
5. The TPS25947x isolated run did not reach valid output startup.
6. No physical board, oscilloscope, Bode/impedance, thermal-camera, NVMe-enumeration or Gen3 x4 bench results are included.
7. IPC-356 was empty and ODB++ is limited by the installed tool; IPC-2581-C is the available intelligent exchange.

## 4. Deliberately absent design elements

- Lane AC capacitors, termination, CMC and ESD were not added before transmitter ownership is confirmed by controlled sources.
- No protocol converter, retimer, switch or firmware is present because this is a passive adapter.
- No universal-SSD, chassis-compatibility or bench-qualification claim is made.
- A 3DX render is handoff/placement evidence, not proof of exact fit or physical test.

## 5. Overclaim risks

`PCIe compliance`, `fabrication-ready`, `universal SSD`, `chassis compatibility`, `bench qualification`, `exact fit`, `SI sign-off` and `thermal validation` must always be qualified as unclaimed or incomplete. The claim matrix links each boundary to evidence.

## 6. Documentation acceptance standard

- A reader can find what the board does, does not do and where the evidence lives within two clicks.
- Every quantitative claim has a status or evidence path.
- Failures, runtime limits, missing models and fabrication blockers remain visible.
- Original Cadence binaries, PCB, PSpice, CAM and images are not rewritten.

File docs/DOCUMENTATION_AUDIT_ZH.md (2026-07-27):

# 文件審查報告（繁體中文）

English version：[`DOCUMENTATION_AUDIT_EN.md`](DOCUMENTATION_AUDIT_EN.md)｜目前主審查檔：[`DOCUMENTATION_AUDIT.md`](DOCUMENTATION_AUDIT.md)

審查範圍：public repository `ErenYagar/nvidia-lde-orcad-portfolio`。方法包含檔案盤點、路徑檢查、evidence/status review、claim scan 與 Python validators。

## 1. Repository 定位

這是一個面試導向的 PCB system-design case study，主題是六層 PCIe Gen3 x4 add-in card 到 M.2 M-Key 2280 NVMe 的 physical interposer。它不做 PCIe protocol conversion、retimer、switch 或 firmware。重點是把 system intent、pin/net interface、power assumptions、3DX/STEP、CAM 與自動化檢查連成一條可追溯流程。

目前 public baseline 是 Rev K / RevK evidence，狀態為 `Interview_Digital_Complete_Not_For_Fabrication`。

## 2. 已有的強證據

| 領域 | 證據 | 審查結論 |
|---|---|---|
| System intent | [`docs/interface_definition.md`](interface_definition.md)、[`docs/system_block_diagram.md`](system_block_diagram.md) | Host、edge、M.2、SSD、power、telemetry 邊界清楚 |
| Architecture | [`docs/architecture_tradeoff.md`](architecture_tradeoff.md) | Options、選擇理由與 exit conditions 有記錄 |
| Capture | [`schematic/connection_matrix.csv`](../schematic/connection_matrix.csv)、ERC report | Machine-readable source 與 native report 有保存 |
| PSpice | [`pspice/stage2/profile_results.csv`](../pspice/stage2/profile_results.csv) | 3.109 V recovery failure 沒有被隱藏 |
| PCB | [`evidence/stage3/stage3_delivery_gate.md`](../evidence/stage3/stage3_delivery_gate.md) | Native DRC/connectivity/shape closure 與九組 pair objects 有證據 |
| 3D/MCAD | [`evidence/stage3/3d_status.md`](../evidence/stage3/3d_status.md) | Native 3DX 與 AP242/mm STEP round-trip 有 hash 綁定 |
| Manufacturing | [`manufacturing/stage3_final_revk/README.md`](../manufacturing/stage3_final_revk/README.md) | Gerber、NC Drill、IPC-2581、BOM/P&P 已輸出但非 fab release |
| Automation | [`scripts/`](../scripts/) | Schema、negative fixtures 與 command-line checks 可重複 |

## 3. 真正未關閉的工程證據

1. PCIe CEM/M.2 controlled specifications 未納入 public package，J1/J2 physical pins 仍為 `Pending_Human_Verification`。
2. JLCPCB 當期 stack-up、impedance width/gap/via 尚未 freeze。
3. Exact host chassis、bracket、standoff、cable、J2 與 SSD models 不完整，因此 collision 只能 preliminary 或 blocked。
4. 官方 buck model 的 recovery 最低 3.109 V，低於 3.135 V screen；27-case sweep runtime-limited。
5. TPS25947x eFuse isolated run 未達有效 output startup。
6. 沒有 physical board、oscilloscope、Bode/impedance、thermal camera、NVMe enumeration 或 Gen3 x4 bench results。
7. IPC-356 為空檔，ODB++ 受安裝工具限制；IPC-2581-C 作為可用替代交換格式。

## 4. 有意不加入的設計

- 沒有自行添加 lane AC capacitors、termination、CMC、ESD，因 transmitter ownership 尚未由 controlled specification 確認。
- 沒有 protocol converter、retimer、switch 或 firmware，因本案是 passive adapter。
- 沒有 universal-SSD、chassis compatibility 或 bench qualification 宣稱。
- 3DX render 只作 placement/hand-off evidence，不代替 exact fit 或 physical test。

## 5. 主要 overclaim 風險

`PCIe compliance`、`fabrication-ready`、`universal SSD`、`chassis compatibility`、`bench qualification`、`exact fit`、`SI sign-off` 與 `thermal validation` 必須在所有對外材料中加上「未宣稱／尚未完成」的限定。Claim matrix 已將這些限制與 evidence 綁定。

## 6. 審查後的文件標準

- 讀者兩次點擊內能知道板子做什麼、不做什麼、證據在哪裡。
- 每個量化 claim 都有 status 或 evidence path。
- Failure、runtime limit、missing model 與 fabrication blocker 保持可見。
- 原始 Cadence binary、PCB、PSpice、CAM 與圖片未被改寫。

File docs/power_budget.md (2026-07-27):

# 電源預算與 Power Design Gate

## 文件狀態

- 設計階段：Rev A pre-freeze
- 架構：`P12V_SLOT` → TPS259472L eFuse → TPS543620 → `P3V3_PRE_SENSE` → 5 mΩ Kelvin shunt → `P3V3_NVME`
- 正常負載：3.3 V / 5 A
- 壓力測試：3.3 V / 7 A、100 µs；這是 `Engineering_Assumption`，不是 TPS543620 的連續額定宣稱
- 計算狀態：`Estimated`
- 模擬與量測狀態：`Planned` / `Not_Yet_Measured`

## 一頁結論

| 項目 | 正常 5 A | 7 A / 100 µs | 判讀 |
|---|---:|---:|---|
| SSD 輸出功率 | 16.500 W | 23.100 W | `P = V × I` |
| 5 mΩ shunt 壓降 | 25.05 mV | 35.05 mV | shunt 電流含 SSD 5/7 A 與下游 local 10 mA |
| shunt 損耗 | 0.126 W | 0.246 W | 100 µs 值不是連續熱額定 |
| `P3V3_PRE_SENSE` | 3.325 V / 5.010 A | 3.335 V / 7.010 A | feedback 在 shunt 後的 `P3V3_NVME` 時的估算 |
| Buck 輸出端需求 | 16.659 W | 23.379 W | `P = VPRE × ISHUNT`，未重複加總 shunt loss |
| Buck 輸入功率，η=90% 假設 | 18.509 W | 25.976 W | 效率尚待 PSpice／bench；此處是保守預算假設 |
| 12 V 端 Buck 電流 | 1.542 A | 2.165 A | 未含 eFuse 損耗 |
| eFuse 損耗，28.2 mΩ typ | 0.068 W | 0.134 W | 以 slot-side 1.548 A / 2.176 A 估算 |
| Slot 12 V 估算電流 | 1.548 A | 2.176 A | 未加入 connector/copper loss |

計算細節與機器可讀數字保留於原始工作包；public package 以本文件與
`pspice/stage2/profile_results.csv` 作為可審查摘要。PCIe CEM 插槽允許功率、inrush 與 12 V tolerance 尚未以
可授權的正式規格完成覆核，所以本文件**不宣告 Power Design Freeze**。

## 預算邊界

1. 5 A 是 SSD branch 的設計點；INA238、TMP1075、PGOOD pull-up 與 LED 的合計先保留
   10 mA allowance。現行接法為 shunt 後 `P3V3_NVME` 經 FB1 至 `P3V3_AUX`，所以 shunt、
   Buck output 與 upstream 計算使用 5.010 A / 7.010 A。
2. Buck 預算效率固定用 90%，目的為估計上游功率，不把它當作 TPS543620 保證值。
3. eFuse 計算使用 28.2 mΩ typical 與 45 mΩ worst-case 兩個 datasheet 值；worst-case 正常負載
   以 1.548 A 估算約 0.108 W。
4. Connector、edge finger、plane、via 與電感 core loss 尚未納入 slot 電流；layout 完成後必須
   由實際銅幾何補算。
5. 7 A 載入會使 TPS543620 超過 6 A continuous rating；只有 100 µs transient profile 通過且
   無 hiccup、PGOOD fault、過度 droop 或元件額定超限時，才可列為支援情境。

## 電壓回授與 shunt 壓降

Rev A 首選由 `P3V3_NVME` 端做 Kelvin feedback，使控制器補償 shunt 的 25.05 mV 正常壓降。
這條 sense trace 不承載負載電流，必須遠離 SW node，並在 OrCAD/ERC 與 layout review 中確認
沒有錯接。若模型或穩定度審查不允許 remote sense，則改在 `P3V3_PRE_SENSE` sense，並把
25.05 mV / 35.05 mV 壓降直接列入 SSD 端電壓 pass/fail。

## Power Design Gate

下列項目全部完成才可 Freeze：

- 以正式 PCIe CEM 文件確認 slot power、12 V operating range 與 inrush envelope。
- 取得目標 SSD 的 vendor power envelope；若超過本預算，建立明確 supported-SSD list。
- 依 [Supported SSD matrix](../validation/supported_ssd_matrix.csv) 保存 reference
  model／capacity／firmware與 qualification evidence；目前 supported-device table為空。
- 在 OrCAD PSpice 實跑 startup、5 A normal、5→7 A/100 µs、line transient 與 tolerance profiles。
- 驗證 high current-limit 模式下 7 A pulse 的 peak inductor current，不得碰到 8.6 A minimum
  high-side limit；模型量得的 margin 必須記錄。
- 以確切 MLCC 料號的 DC-bias 曲線確認 `COUT_EFFECTIVE ≥ 44 µF`；44 µF 只是初版下限。
- 以 PCB 實際銅面重算 TPS543620、TPS259472L、L1 與 shunt 溫升。
- 實板確認 `P3V3_NVME` 在正式 SSD tolerance 內；正式 tolerance 未確認前，內部設計目標用
  3.135 V 至 3.465 V（±5%）並標 `Engineering_Assumption`。
- 依官方 TPS25947 資料與本文件後續建立 eFuse setting worksheet；public package 未包含 worksheet
  關閉 UVLO、OVCSEL、CdVdt、RILM、CITIMER、PGTH、SOA 與 fault-policy corners；
  特別確認 472L 的 active-current-limit／thermal latch 行為是否符合系統需求。

## 可追溯來源

- TI, **TPS543620 datasheet Rev. C**, SLUSDR5C：4–18 V、6 A、Table 7-4/7-5、Table 8-2、
  Equation 6–19。<https://www.ti.com/lit/ds/symlink/tps543620.pdf>
- TI, **TPS25947 datasheet Rev. C**, SLVSFC9C：TPS259472L 功能、RON、ILIM、dVdt 與 thermal。
  <https://www.ti.com/lit/ds/symlink/tps25947.pdf>
- TI, **INA238 datasheet Rev. B**, SLYS025B：ADCRANGE 與 shunt full-scale。
  <https://www.ti.com/lit/ds/symlink/ina238.pdf>
- Vishay, **WSK2512 Power Metal Strip Resistors, 4-Terminal**：ordering code 與額定。
  <https://www.vishay.com/docs/30108/wsk2512.pdf>

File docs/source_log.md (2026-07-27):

# Source Log

存取日期：2026-07-23。此表記錄官方來源的存在與預定用途；`Confirmed_Official` 表示來源本身已由原廠／標準組織發布，不代表本板設計已因此完成驗證。

| ID | 官方來源 | 發行者／版本或日期 | 使用章節／圖表 | 支援的設計決策 | 來源狀態 | 設計審查狀態 |
|---|---|---|---|---|---|---|
| SRC-001 | [PCI Express Card Electromechanical Specification Revision 3.0](https://pcisig.com/PCIExpress/Specs/CEM/CardElectromechanical_3.0) | PCI-SIG；Rev 3.0；2013-07-21 | 受控本的 connector pin、power、PRSNT、mechanical 章節；尚未取得 | edge mechanical、slot power／inrush、PRSNT、sideband boundary | `Confirmed_Official` | `Pending_Human_Verification` |
| SRC-002 | [PCI Express CEM specification overview](https://pcisig.com/specification-overview/pci-express-cem) | PCI-SIG；動態入口 | Specification overview 全頁 | 確認 CEM 與 Base Specification 的治理關係及版本入口 | `Confirmed_Official` | `Pending_Human_Verification` |
| SRC-003 | [NVM Express Base Specification](https://nvmexpress.org/specification/nvm-express-base-specification/) | NVM Express；ratified revision portal；存取 2026-07-23 | revision／download index | NVMe protocol 背景與 validation vocabulary | `Confirmed_Official` | `Planned` |
| SRC-004 | [NVMe Power Governance webinar](https://nvmexpress.org/wp-content/uploads/NVMe_Power_Governance_Webinar_FINAL.pdf) | NVM Express；webinar deck；日期依 PDF | power state／power governance slides | 5 A normal 與 7 A / 100 µs stimulus 的治理背景；不可取代目標 SSD datasheet | `Confirmed_Official` | `Planned` |
| SRC-005 | [PCI Express M.2 Specification Revision 5.1 landing page](https://pcisig.com/PCIExpress/Spec/M.2/_5.1) | PCI-SIG；Rev 5.1；2024-05-20；存取 2026-07-23 | 公開 metadata；受控 pin table／ECN 副本尚未保存 | 候選 governing revision；J2 pin、key、power、sideband、reserved／NC 必須由受控本確認 | `Confirmed_Official` | `Pending_Human_Verification` |
| SRC-006 | [Jetson AGX Orin Developer Kit Carrier Board Specification](https://developer.nvidia.com/assets/embedded/secure/jetson/agx_orin/jetson_agx_orin_devkit_carrier_board_specification_sp) | NVIDIA；SP-10900-001 v1.2；2024-12；存取 2026-07-23；local SHA-256 `D817A69767B9E11EFAA9B54037B87039A16BFF3E5A7C41255CE3B75E47322CAC` | Table 2-8 pp.14–15；Table 2-13 pp.19–20；local `evidence/official_sources/NVIDIA_Jetson_AGX_Orin_Carrier_Board_Spec_SP-10900-001_v1.2.pdf` | CEM x8 與 M.2 M-Key 的第二份公開原廠候選 mapping 交叉檢查；不取代 governing spec | `Confirmed_Official` | `Pending_Human_Verification` |
| SRC-007 | [Cadence PCB Design and Analysis](https://www.cadence.com/en_US/home/tools/pcb-design-and-analysis.html) | Cadence；動態產品頁 | OrCAD X／PSpice／Allegro capability sections | 工具能力與 native database 邊界 | `Confirmed_Official` | `Planned` |
| SRC-008 | [OrCAD X and PSpice FAQ](https://www.cadence.com/en_US/home/tools/pcb-design-and-analysis/orcad/faqs.html) | Cadence；動態 FAQ | license、PSpice、compatibility FAQ | license tier、PSpice feature、database compatibility 注意事項 | `Confirmed_Official` | `Pending_Human_Verification` |
| SRC-009 | [TPS543620 product page](https://www.ti.com/product/TPS543620) | Texas Instruments；datasheet Rev C；model Rev A portal | Features、design tools／simulation、package／ordering | 6 A buck selection、PG、model availability | `Confirmed_Official` | `Pending_Human_Verification` |
| SRC-010 | [TPS543620 datasheet](https://www.ti.com/lit/ds/symlink/tps543620.pdf) | Texas Instruments；SLUSDR5C；Rev C；2021-06 | Table 5-1；Sections 6–8；Tables 7-4／7-5／8-2；Figure 8-30；Equations 6–20 | U2 pin map、1 MHz MODE/FSEL、L/C/feedback、current limit、layout、thermal | `Confirmed_Official` | `Pending_Human_Verification` |
| SRC-011 | [TPS259472LRPWR orderable page](https://www.ti.com/product/TPS25947/part-details/TPS259472LRPWR) | Texas Instruments；exact orderable；存取 2026-07-23 | ordering／package／status fields | eFuse exact MPN 與 ordering identity | `Confirmed_Official` | `Engineering_Assumption` |
| SRC-012 | [TPS25947 datasheet](https://www.ti.com/lit/ds/symlink/tps25947.pdf) | Texas Instruments；SLVSFC9C；Rev C；2026-05 | device comparison；Table 5-1；Sections 6–8；SOA／ILIM／dVdt equations | U1 pins 1–10、latch-off、PG／PGTH、SOA 與設定值計算方法 | `Confirmed_Official` | `Pending_Human_Verification` |
| SRC-013 | [INA238AIDGSR product page](https://www.ti.com/product/INA238/part-details/INA238AIDGSR) | Texas Instruments；exact orderable；存取 2026-07-23 | features、package／ordering | power monitor exact MPN、range 與 package | `Confirmed_Official` | `Pending_Human_Verification` |
| SRC-014 | [INA238 datasheet](https://www.ti.com/lit/ds/symlink/ina238.pdf) | Texas Instruments；SLYS025B；Rev B | Table 4-1；ADC range／register／layout sections | U3 pin map、ADCRANGE=1、shunt full-scale、calibration、averaging | `Confirmed_Official` | `Pending_Human_Verification` |
| SRC-015 | [TMP1075DR product page](https://www.ti.com/product/TMP1075/part-details/TMP1075DR) | Texas Instruments；SOIC-8 exact orderable；存取 2026-07-23 | features、package／ordering | board-temperature monitor exact MPN 與 package | `Confirmed_Official` | `Pending_Human_Verification` |
| SRC-016 | [TMP1075 datasheet](https://www.ti.com/lit/ds/symlink/tmp1075.pdf) | Texas Instruments；current revision at access date | Table 5-1；address、register、operating、layout sections | U4 pin map、address straps、accuracy 與 placement semantics | `Confirmed_Official` | `Pending_Human_Verification` |
| SRC-017 | [Amphenol PCIe M.2 Gen3／Gen4 connector overview](https://www.amphenol-cs.com/media/wysiwyg/files/documentation/datasheet/ssio/ssio_pcie_m2.pdf) | Amphenol Communications Solutions；family datasheet | product-selection table、mechanical family overview | connector family、key、height、data-rate capability 初篩 | `Confirmed_Official` | `Pending_Human_Verification` |
| SRC-018 | [MDT420M01501 product page](https://www.amphenol-cs.com/product/mdt420m01501.html)／[CMDT420X01501 drawing](https://cdn.amphenol-cs.com/media/wysiwyg/files/drawing/cmdt420x01501.pdf) | Amphenol；exact part Active；0.5 mm pitch、4.2 mm height、Key M、30 µin Au；drawing Rev A Released 2021-11-19；4 pages；存取 2026-07-23 | exact-part drawing／STEP 入口已確認；本機 automated download 被 CDN 403 阻擋，尚無 local PDF／hash／overlay | 主選 connector identity 與 source acquisition；pad、hold-down、datum、origin、keepout、seating plane仍不可 freeze | `Confirmed_Official` | `Pending_Human_Verification` |
| SRC-019 | [MDT320M01001 product page](https://www.amphenol-cs.com/product/mdt320m01001.html)／[MDTXXXXXX001 family drawing](https://cdn.amphenol-cs.com/media/wysiwyg/files/drawing/mdtxxxxxx001.pdf) | Amphenol；exact part Active；0.5 mm pitch、3.2 mm height、Key M、30 µin Au；產品頁連結為 generic family drawing；存取 2026-07-23 | generic drawing／STEP 入口已確認；exact suffix applicability、revision、local hash與1.0 mm stack-height差異待審 | 備選 connector 不可視為 drop-in；footprint 與 Z-chain維持 pending | `Confirmed_Official` | `Pending_Human_Verification` |
| SRC-020 | [WSK2512 four-terminal datasheet](https://www.vishay.com/docs/30108/wsk2512.pdf) | Vishay；document 30108；current revision at access date | Electrical Specifications、Dimensions、Global Part Numbering | `WSK25125L000FEA` identity、5 mΩ、1%、four-terminal land、power／TCR review | `Confirmed_Official` | `Pending_Human_Verification` |
| SRC-021 | [JLCPCB Impedance Calculator Guide](https://jlcpcb.com/help/article/user-guide-to-the-jlcpcb-impedance-calculator) | JLCPCB；動態製程文件；存取 2026-07-23 | layer count、finished thickness、copper、routing/reference layer、target、pair gap與 coplanar gap input；4–8 layer calculator default material說明 | calculator input、material selection、stack-up mapping與 evidence 保存方式 | `Confirmed_Official` | `Pending_Fabricator_Confirmation` |
| SRC-022 | [JLCPCB multilayer standard laminated structures](https://jlcpcb.com/help/article/multi-layer-pcb-standard-laminated-structures) | JLCPCB；動態製程文件；存取 2026-07-23 | 6-layer／1.6 mm controlled-impedance候選；outer 1／2 oz、inner 0.5／1／2 oz ordering options；可用結構持續更新 | 投板時六層 1.6 mm stack-up候選；不得當成已凍結 order cross-section | `Confirmed_Official` | `Pending_Fabricator_Confirmation` |
| SRC-023 | [ADP198 product page](https://www.analog.com/en/products/adp198.html) | Analog Devices；production status；ADP198ACPZ-R7 | product status、package、model links | J3 3.3 V sense path reverse-current blocking 與 lifecycle | `Confirmed_Official` | `Engineering_Assumption` |
| SRC-024 | [ADP198 datasheet Rev. G](https://www.analog.com/media/en/technical-documentation/data-sheets/adp198.pdf) | Analog Devices；Rev G；2013-08 | Table 1；Table 5；Timing／Applications；CP-8-10 outline | U5 pin map、reverse current、EN／SEL、timing、package | `Confirmed_Official` | `Pending_Human_Verification` |
| SRC-025 | [XGL5050-152 product page](https://www.coilcraft.com/en-us/products/power/shielded-inductors/molded-inductor/xgl/xgl5050/xgl5050-152/) | Coilcraft；exact value page；存取 2026-07-23 | electrical specifications、dimensions、terminals | L1 1.5 µH、DCR、Isat、Irms 與 footprint candidate | `Confirmed_Official` | `Pending_Human_Verification` |
| SRC-026 | [C3225X7R1E106K250AC product page](https://product.tdk.com/en/search/capacitor/ceramic/mlcc/info?part_no=C3225X7R1E106K250AC) | TDK；exact MPN；存取 2026-07-23 | Production status、ratings、dimensions、characteristic data | C4/C5 10 µF 25 V X7R input candidate | `Confirmed_Official` | `Pending_Human_Verification` |
| SRC-027 | [C3225X7R1C226M250AC product page](https://product.tdk.com/en/search/capacitor/ceramic/mlcc/info?part_no=C3225X7R1C226M250AC) | TDK；exact MPN；存取 2026-07-23 | Production status、ratings、dimensions、characteristic data | C11–C14 22 µF 16 V X7R output candidate | `Confirmed_Official` | `Pending_Human_Verification` |
| SRC-028 | [2N7002 datasheet](https://www.diodes.com/datasheet/download/2N7002.pdf) | Diodes Incorporated；DS11303 Rev 40-2；2024-07 | pin-out、ordering information、maximum ratings、SOT-23 outline | Q1 G/S/D pin map、2N7002-7-F ordering 與 LED buffer limits | `Confirmed_Official` | `Pending_Human_Verification` |
| SRC-029 | [BLM21PG221SN1D datasheet](https://www.murata.com/en-eu/api/pdfdownloadapi?cate=cgsubChipFerriBead&partno=BLM21PG221SN1D) | Murata；product search datasheet；updated 2025-08-21 | ratings、packaging、dimensions、frequency characteristic | FB1 telemetry filter candidate 與 package | `Confirmed_Official` | `Pending_Human_Verification` |
| SRC-030 | [SMBJ family page](https://www.littelfuse.com/products/tvs-diodes/surface-mount/smbj.aspx) | Littelfuse；dynamic family page | electrical table、package／part selector | D2 DNP footprint candidate；不作已核准 clamp 宣稱 | `Confirmed_Official` | `Pending_Human_Verification` |
| SRC-031 | [Samtec TSW family page](https://www.samtec.com/products/tsw) | Samtec；dynamic family page | ordering code、dimensions、footprint | J3 TSW-104-08-L-S-RA candidate drawing與採購核對 | `Confirmed_Official` | `Pending_Human_Verification` |
| SRC-032 | [C1608X7R1C105K080AC product page](https://product.tdk.com/en/search/capacitor/ceramic/mlcc/info?part_no=C1608X7R1C105K080AC) | TDK；exact MPN；存取 2026-07-23 | Production status、1 µF／16 V／X7R ratings、dimensions | C18 protected sense-output capacitor candidate | `Confirmed_Official` | `Pending_Human_Verification` |
| SRC-033 | [DigiKey product search](https://www.digikey.com/) | DigiKey；authorized distributor dynamic pages；存取 2026-07-23 | qty-1 public price、stock、distributor lifecycle label | `manufacturing/cost_estimate.csv` budgetary price snapshot | `Engineering_Assumption` | `Estimated` |
| SRC-034 | [TPS543620 PSpice Transient Model SLUM787A](https://www.ti.com/lit/mo/slum787a/slum787a.zip) | Texas Instruments；web Rev A；internal Final 1.1／JUL2024；存取 2026-07-23；ZIP SHA-256 `6D335BA1C367AEED5340D26EC9D954BE63B2A30960C966F0CA5B50B3E54F9C7D` | `tps543620_trans.lib` SHA-256 `EDA49ED925B97ABB34C956E87C5DF490AB0EFB605D2C0F7792D67E8CDEC2441F`；feature/limitation PDF；`pspice/vendor_models/source_model_manifest.csv` | Buck transient model provenance、model capability 與 AC-01 limitation | `Confirmed_Official` | `Pending_Human_Verification` |
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

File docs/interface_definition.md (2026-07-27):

# 介面定義

## 文件目的與狀態

本文件定義 Rev A PCIe Gen3 x4 Add-in Card（AIC）轉 M.2 M-Key 2280 NVMe 的邏輯介面邊界。它是 Capture 接線、Constraint Manager 分類及 bring-up 的共同輸入，不是 PCIe compliance 證明。

截至 2026-07-23，PCIe CEM 3.0 與 M.2 controlled specification 的實體 Pin mapping 尚未完成雙來源逐 Pin 覆核。因此：

- 邏輯訊號名稱、方向與設計所有權已定義。
- J1 PCIe edge 與 J2 M.2 的實體 Pin number 一律維持 `Pending_Human_Verification`。
- 不得從網路圖片、第三方 pinout 或記憶填入 Pin number。
- `schematic/connection_matrix.csv` 是連接真相來源；本文件僅描述介面契約。
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

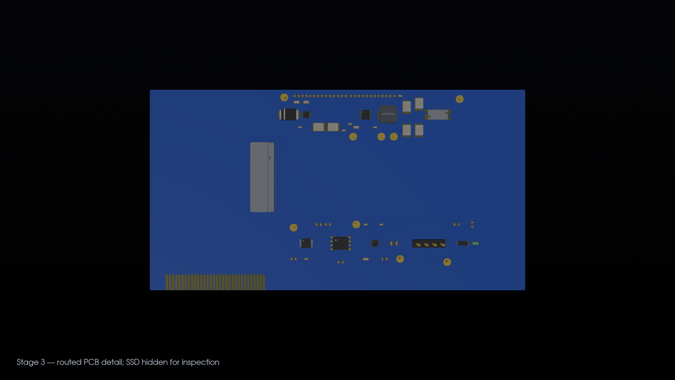
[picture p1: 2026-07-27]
evidence/stage3/portfolio_revk/stage3_top_pcb_detail.png

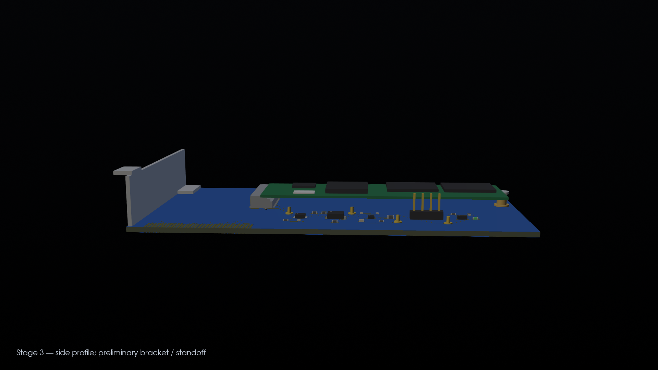
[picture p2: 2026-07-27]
evidence/stage3/portfolio_revk/stage3_side.png

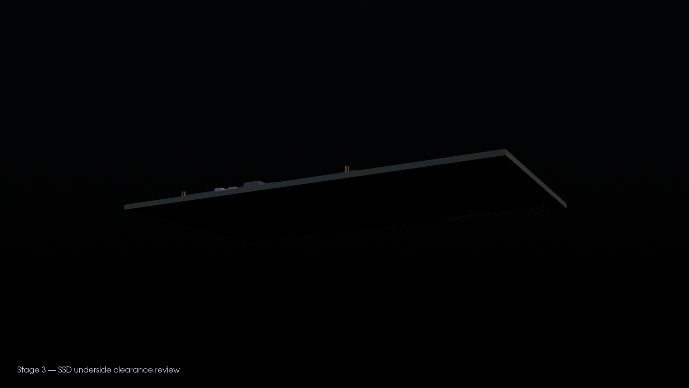
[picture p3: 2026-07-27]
evidence/stage3/portfolio_revk/stage3_ssd_underside.png

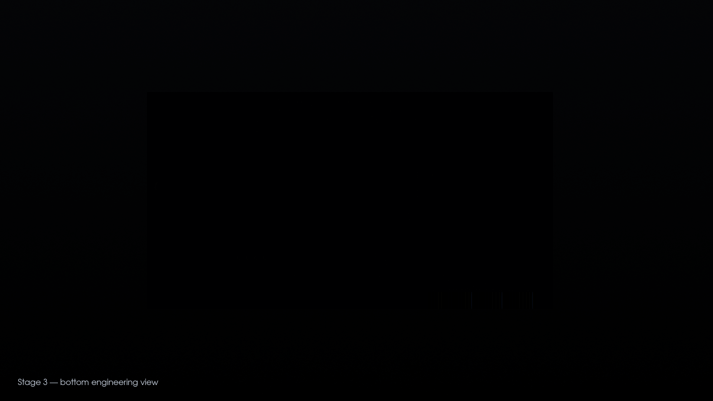
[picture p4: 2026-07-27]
evidence/stage3/portfolio_revk/stage3_bottom.png

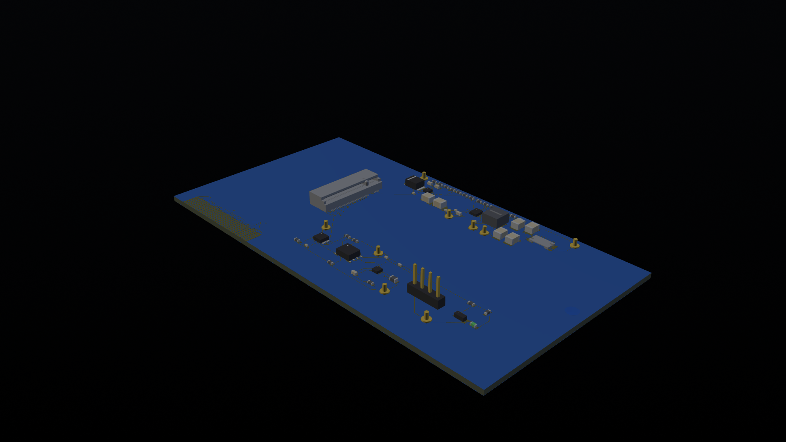
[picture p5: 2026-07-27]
evidence/stage3/portfolio_revk/stage3_hero_isometric_pcb_detail.png

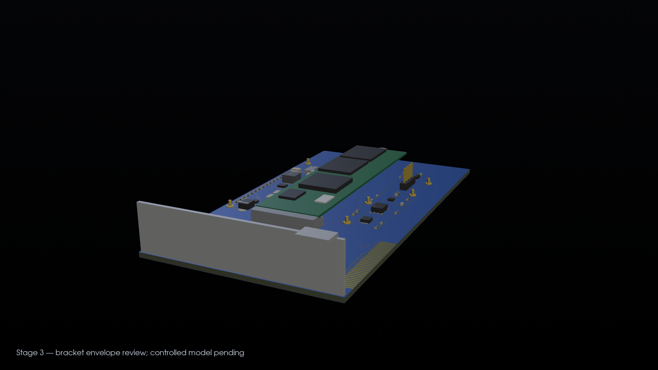
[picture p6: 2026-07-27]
evidence/stage3/portfolio_revk/stage3_bracket_review.png

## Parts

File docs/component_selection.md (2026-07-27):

# 元件候選集與 Rev A 推薦組

## 選型原則

本文件只把原廠資料已能支持的能力標成 `Confirmed_Official`。應用中的電流、熱、footprint、
供應鏈與模型相容性仍需在對應 Gate 完成。價格是 2026-07-23 的 qty-1 budgetary snapshot，
不是採購報價，也不會使尚未完成的 selection gate 自動關閉。

## Rev A 推薦組

| 功能 | 推薦料號／名義值 | 已知官方能力 | 專案狀態與理由 |
|---|---|---|---|
| eFuse | TI `TPS259472LRPWR` | 2.7–23 V family、active current limit、PG/PGTH、pin-selectable OVC；`L` variant在 thermal shutdown後 latch-off | exact MPN／Pin／fault behavior 為 `Confirmed_Official`；它不等同 ITIMER 到期即關斷的 `TPS259474L` circuit-breaker，OVCSEL、RILM、CdVdt、ITIMER、PGTH與SOA均保持 `Pending_Human_Verification` |
| Buck | TI `TPS543620RPYR` | 4–18 V、6 A、0.5–7 V、PGOOD、可選 0.5–4 ms soft-start、官方 PSpice transient model | `Engineering_Assumption`；1 MHz、high current-limit、1 ms soft-start baseline |
| 電感 | Coilcraft `XGL5050-152MEC` | 1.5 µH、DCR 4.7 mΩ typ/5.7 mΩ max、Isat 9.8 A（20% drop）、Irms 17.1 A（40°C rise） | 官方電氣值為 `Confirmed_Official`；footprint、hot inductance、core-loss、thermal 與供應仍待確認 |
| Buck local Cin | 2 × TDK `C3225X7R1E106K250AC` + HF bypass | 10 µF / 25 V / X7R / 1210、TDK `Production`；TI 要求 VIN–PGND local ceramic 與高頻 bypass | exact MPN 已進 BOM 但仍為 `Engineering_Assumption`；12 V DC-bias 未 Freeze |
| Buck Cout | 4 × TDK `C3225X7R1C226M250AC`；有效值設計下限 44 µF | 22 µF / 16 V / X7R / ±20% / 1210、TDK `Production` | exact MPN 已進 BOM 但仍為 `Engineering_Assumption`；88 µF nominal 不能等同 88 µF effective |
| Shunt | Vishay `WSK25125L000FEA` | WSK2512 四端、`5L000 = 0.005 Ω`、`F = 1%`、`EA` lead-free tape/reel | ordering identity `Confirmed_Official`；land pattern、pulse 與系統熱審查仍 pending |
| Power monitor | TI `INA238AIDGSR` | 16-bit I²C power monitor、2.7–5.5 V supply、ADCRANGE=1 為 ±40.96 mV | `Engineering_Assumption`；5 mΩ 時 nominal full-scale ±8.192 A，7 A=35 mV |
| Temperature | TI `TMP1075DR` | 1.7–5.5 V、I²C、D package | `Engineering_Assumption`；量 PCB local temperature，不宣稱 SSD controller junction temperature |

## 被動料候選但未核准

- Cin candidate：TDK `C3225X7R1E106K250AC`，10 µF / 25 V / X7R / 1210。
- Cout candidate：TDK `C3225X7R1C226M250AC`，22 µF / 16 V / X7R / ±20% / 1210。
- 上述 MPN 均為 `Pending_Human_Verification`：需在原廠 SimSurf/characteristic data 以 12 V 或
  3.3 V DC bias、溫度、AC ripple 取得 effective capacitance，再同步 manufacturing BOM。
- 若兩顆 Cin 在 12 V 的合計有效值不滿足設計需求，增加相同 MLCC 顆數或使用已驗證的
  25 V polymer bulk；不可只用 nominal µF 作結論。

原 Murata `GRM32ER71A226KE20L` 在 2026-07-23 的授權通路資料為 NRND，
`GRM188R71A105KA61D` 為 Obsolete；兩者已退出 Rev A 推薦組。原
`GRM21BR71E106KA73L` 未能以原廠／授權通路資料完成 lifecycle 證明，也不再作主選。

## A／B 組比較與相容性

下表的 `Drop-in` 只表示機械／Pin 層級候選，不代表可以跳過 simulation、thermal、
SI/PI、firmware 或 mechanical review。價格為 qty-1、USD、2026-07-23 snapshot。

| 功能 | Set A／單價 | Set B／單價 | Lifecycle／模型 | Drop-in 或必要 ECO | 結論 |
|---|---|---|---|---|---|
| PCIe edge | `CUSTOM-PCIE-GEN3-X4-EDGE`／PCB quote | N/A | Board feature／無模型 | 必須跟 CEM 與板廠共同凍結 | 無採購型 second source |
| M.2 connector | `MDT420M01501`／$4.09 | `MDT320M01001`／$2.42 | 兩者 Active；無 PSpice | Drawing、height、1:1 print、STEP fit 後才可判定 | B 是機構備選，不先稱 drop-in |
| eFuse | `TPS259472LRPWR`／$1.72 | `TPS259474LRPWR`／$1.72 | 兩者 Active；TPS25947 family transient model | RPW footprint 相同候選；overcurrent 行為不同，需設定與 fault-policy ECO | A 保留 latch-off baseline |
| Buck | `TPS543620RPYR`／$3.16 | `TPS543820RPYR`／約 $4.37 | 兩者 Active；A 有官方 PSpice，B model availability 待下載 smoke test | TI 宣稱 pin-to-pin family compatibility；仍需 BOM、MODE、thermal、transient 全重跑 | B 是 7 A pulse 失敗時首選 ECO |
| Current monitor | `INA238AIDGSR`／$3.26 | `INA226AIDGSR`／$2.66 | 兩者 Active；以 analytical/register model 為主 | DGS-10 相同不代表 Pin／register drop-in；需 symbol、firmware、range ECO | A 的 ±40.96 mV range 更符合本案 |
| Temperature | `TMP1075DR`／$0.54 | `TMP1075DGKR`／約 $0.46 | 兩者 Active；power transient 不需模型 | SOIC-8 與 VSSOP-8 不同 footprint | B 需要 PCB ECO |
| Sense reverse blocker | `ADP198ACPZ-R7`／$1.41 | `NO_EXACT_BACKUP_SELECTED` | A 為 Production；LTspice listed、PSpice 不宣稱 | 任何替代品都要證明 unpowered reverse-block／leakage | 未選定 B 是 release blocker |
| 5 mΩ Kelvin shunt | `WSK25125L000FEA`／$2.37 | `NO_EXACT_DROP_IN_SELECTED` | A Active；primitive R + parasitic | 必須同為四端、pulse/TC/land pattern 通過 | 未選定 B 是 supply-chain blocker |
| Inductor | `XGL5050-152MEC`／$4.11 | `XGL5050-182MEC`／quote | 兩者 Active；primitive L/DCR，飽和與 core loss 不完整 | 同系列 footprint 候選；L、DCR、Isat 變更需重算 | B 不是數值 drop-in |
| AUX ferrite | `BLM21PG221SN1D`／$0.11 | `RC0805JR-070RL`／約 $0.10 | 兩者 Active；primitive | B 會移除濾波功能，必須先通過 PI/EMI review | B 是 DNI／debug ECO，不是 second source |
| Buck Cin | `C3225X7R1E106K250AC`／$0.62 | `CL32B106KAULNNE`／$0.45 | 兩者 Active/Production；可用 vendor characteristic data | 1210 nominal match；仍比較 height、DC-bias、ESR/ESL、ripple | A 推薦 |
| Buck Cout | `C3225X7R1C226M250AC`／$0.61 | `GRM32ER71C226KEA8L`／$0.86 | 兩者 Active/Production；vendor curve + primitive | 1210；tolerance、thickness、DC-bias 與 land pattern 要重審 | A 推薦 |
| 小信號 MLCC／R | BOM 中 exact MPN／$0.10–0.15 | BOM `Alternative_Part` | selected exact parts為 Active/Production；primitive | 相同 case 不等於核准 AVL；value/tolerance/voltage/TCR 要逐列關閉 | 未列 exact B 的 resistor row 保持 blocker |
| Indicator | `2N7002-7-F` + `LTST-C190KGKT`／$0.35 | `2N7002ET1G` + `SML-E12M8WT86`／quote | 主選 Active；MOSFET vendor model／LED 無需模型 | G/S/D 與 LED polarity/brightness 都要 cross-probe | B 需 symbol/assembly ECO |
| Header／TP | `TSW-104-08-L-S-RA` + `S1751-46R`／$0.82 + $0.30 ea. | Header B 未選；TP `Keystone 5006` | 主選 Active；無 PSpice | Drill、tail、mating clearance、probe access 不同 | Header B 未選是 release blocker |
| Retention／bracket | `TBD_M2_2280_STANDOFF` + custom bracket／quote | 未選 | mechanical-only | 先凍結 connector stack height、CEM datum、chassis fit | 未完成，不可交付組裝 |

## 成本基準

- `manufacturing/bom.csv` 的 `Estimated_Cost_USD` 定義為 qty-1 unit cost；同一 line
  有多顆時以 `Quantity × unit cost` 計算。
- `manufacturing/cost_estimate.csv` 保存來源、存取日與 extended cost。
- 已有 exact MPN 且 Rev A 為 Populate 的 electronics priced subtotal 是 **US$30.79**。
- subtotal 不含 J1 PCB/controlled impedance、C2/C3、R1–R6、MH1、BR1、assembly、
  shipping、tax、tariff、reel fee 與 Coilcraft marketplace shipping。
- `TBD_AFTER_CEM` 與 `Quote_Required` 是刻意保留的 Gate，不是零成本。

## 主要候選比較

| 功能 | 候選 | 相對優點 | 風險／使用條件 | 結論 |
|---|---|---|---|---|
| eFuse | TPS259472L | Active current limit、PG、pin-selected clamp；限流／clamp造成 thermal shutdown後 latch-off | OVCSEL、RILM、dVdt、ITIMER、SOA與 fault recovery 需在 CEM review 後計算 | Rev A baseline；fault policy需依 [power budget](power_budget.md) 與官方資料後續關閉；public package 未包含 worksheet |
| eFuse | TPS259474L | ITIMER後 circuit-breaker shutdown、PG、adjustable OVLO；`L` variant保持 latch-off | 對 transient、overvoltage與desired behavior不同 | 備選；若要求 immediate circuit-breaker latch，再走 ECO |
| eFuse | TPS259470L | Adjustable OVLO、FLT | 無 PG/PGTH，與目前 sequencing 需求不完全相符 | 不推薦 Rev A |
| Buck | TPS543620 | 6 A、小型、官方 transient model、與計畫一致 | 7 A 只可當短 pulse；thermal margin 要驗證 | Rev A 推薦 |
| Buck | TPS543820 | 8 A、datasheet 宣稱與 TPS543620 pin-to-pin compatible | BOM、MODE、thermal 與模型需重新走 Gate | 若 7 A pulse 失敗的首選 ECO |
| Telemetry | INA238 | 85 V common-mode、16-bit、可選 ±40.96 mV range | 7 A 只剩 5.96 mV nominal headroom 到 full-scale | Rev A 推薦；tolerance 必測 |
| Temperature | TMP1075 | 簡單、I²C、標準封裝 | 只代表 sensor/PCB 溫度 | Rev A 推薦 |

## 關鍵設定

- `RFSEL = 11.8 kΩ, 1%`：TPS543620 nominal 1 MHz。
- `RMODE = 11.3 kΩ, 1%`：High current-limit、4 pF ramp、1 ms soft-start；與 TI
  TPS543620 Rev. C 3.3 V / 1 MHz reference（Figure 8-30）一致。
- `L1 = 1.5 µH`：TI Table 8-2 的 3.3 V / 1 MHz / 6 A recommended 值，允許範圍 1–3.3 µH。
- `RFB_BOTTOM = 4.99 kΩ, 1%`、`RFB_TOP = 28.0 kΩ, 1%`：以 0.5 V nominal reference
  得 3.305 V nominal；最終值需配合 Kelvin sense 位置與 tolerance profile。
- `CFF = 33 pF candidate/DNI-capable`：採 TI 3.3 V / 1 MHz reference baseline；
  只能在 loop/transient review 後 Freeze。
- eFuse `CdVdt`、`RILM`、`ITIMER`、`PGTH` 與 `OVCSEL`：全部維持 `TBD_AFTER_CEM_*`。
  先由正式 slot power／inrush、Buck startup、eFuse SOA 與 fault policy 算出 target，再用
  TI equation／calculator 和 tolerance profile 選值；不得把 datasheet example 當成 Rev A 設定。

## Selection Gate

1. Datasheet revision、orderable suffix、lifecycle 與 footprint 四項一致。
2. L1 的 Isat 必須高於 PSpice 量得的 worst-case peak，且以 hot DCR/Irms 檢查溫升。
3. Cin/Cout 必須以 exact MPN 的 DC-bias 曲線通過有效電容下限。
4. INA238 設 `ADCRANGE=1` 時，含 shunt +1%、load overshoot 的 `|VSHUNT| < 40.96 mV`。
5. 任何 7 A profile 觸發 current limit、hiccup、PGOOD fault 或 rail 超限，即限制 supported SSD
   或改評 TPS543820；不得把短 pulse 結果外推成連續 7 A。

## 官方來源

- <https://www.ti.com/lit/ds/symlink/tps543620.pdf>
- <https://www.ti.com/product/TPS543620>
- <https://www.ti.com/lit/ds/symlink/tps25947.pdf>
- <https://www.ti.com/product/TPS25947>
- <https://www.ti.com/lit/ds/symlink/ina238.pdf>
- <https://www.ti.com/lit/ds/symlink/tmp1075.pdf>
- <https://www.vishay.com/docs/30108/wsk2512.pdf>
- <https://www.coilcraft.com/en-us/products/power/shielded-inductors/molded-inductor/xgl/xgl5050/xgl5050-152/>

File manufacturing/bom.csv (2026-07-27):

Reference_Designator | Quantity | Manufacturer | Manufacturer_Part_Number | Description | Package | Operating_Voltage | Current_Rating | Temperature_Rating | Key_Datasheet_Limits | PSpice_Model_Availability | Footprint_Availability | Lifecycle | Estimated_Cost_USD | Alternative_Part | Selection_Rationale | Datasheet_Review_Status | Assembly_Disposition | Source_URL | Notes
J1 | 1 | PCB Fabricator | CUSTOM-PCIE-GEN3-X4-EDGE | PCIe x4 gold-finger edge interface | PCB edge feature | Per PCIe CEM | Pending CEM review | Pending CEM review | Thickness finger geometry plating and bevel require CEM plus fabricator review | Not applicable | Custom footprint pending CEM mechanical review | Not applicable | Included_in_PCB_quote | None standardized PCB feature | Required host interface; not a purchased connector | Pending_Human_Verification | PCB_Feature | https://pcisig.com/PCIExpress/Specs/CEM/CardElectromechanical_3.0 | Do not release until official pin and mechanical review
J2 | 1 | Amphenol CS | MDT420M01501 | M.2 Key M 67-contact right-angle connector | SMT 0.5 mm pitch 4.2 mm height | 50 V connector rating | 1 A per contact per product page | -40 to 85 degC | Actual multi-pin power capacity and land pattern require drawing review | Not applicable | Manufacturer symbol footprint and 3D listed | Active | 4.09 | MDT320M01001 | Active stocked M-key connector with mechanical data and margin above Gen3 requirement | Confirmed_Official | Populate | https://www.amphenol-cs.com/product/mdt420m01501.html | Drawing revision and 2280 standoff geometry must be archived
U1 | 1 | Texas Instruments | TPS259472LRPWR | 5.5 A eFuse with active current limit PGOOD and latch-off | VQFN-HR-10 RPW | 2.7 to 23 V | 0.5 to 6 A programmable | -40 to 125 degC | OVC current-limit dVdt ITIMER and PGTH values remain calculation-controlled | Official transient model available | TI land pattern available | Active | 1.72 | TPS259474LRPWR | Provides input protection soft-start current limit and power-good with deterministic latch-off | Confirmed_Official | Populate | https://www.ti.com/product/TPS25947/part-details/TPS259472LRPWR | Orderable latch-off suffix and RPW package confirmed from TI device comparison; TPS259474L changes overcurrent behavior and is not a drop-in substitution without review
U2 | 1 | Texas Instruments | TPS543620RPYR | 4 to 18 V 6 A synchronous buck with PGOOD | VQFN-HR-14 RPY | 4 to 18 V | 6 A | -40 to 150 degC junction | Frequency mode current-limit soft-start and passive values require calculator plus simulation | Official PSpice transient model available | TI land pattern and CAD listed | Active | 3.16 | TPS543820RPYR | Discrete inductor path demonstrates power-stage calculation and layout while retaining official model | Confirmed_Official | Populate | https://www.ti.com/product/TPS543620 | Normal target is 5 A; 7 A 100 us remains a planned transient verification
U3 | 1 | Texas Instruments | INA238AIDGSR | 16-bit I2C current voltage and power monitor | VSSOP-10 DGS | 2.7 to 5.5 V supply | Shunt-selected | -40 to 125 degC | ADC range calibration averaging and ALERT require firmware/test configuration | No power-stage model required | TI land pattern available | Active | 3.26 | INA226AIDGSR | Provides independent high-side SSD telemetry in hand-assembly-friendly package | Confirmed_Official | Populate | https://www.ti.com/product/INA238/part-details/INA238AIDGSR | Address straps and calibration register values pending
U4 | 1 | Texas Instruments | TMP1075DR | Digital local temperature sensor with I2C | SOIC-8 D | 1.7 to 5.5 V | Microamp-class sensor | -55 to 125 degC | Accuracy depends on temperature range and placement thermal coupling | No model required | TI land pattern available | Active | 0.54 | TMP1075DGKR | SOIC package lowers prototype assembly risk and shares telemetry bus | Confirmed_Official | Populate | https://www.ti.com/product/TMP1075 | Sensor measures local board temperature not SSD junction temperature
U5 | 1 | Analog Devices | ADP198ACPZ-R7 | Reverse-current-blocking high-side switch for I2C header sense | LFCSP-8 CP-8-10 | 1.65 to 6.5 V | 1 A continuous | -40 to 85 degC orderable range | Reverse output-to-input current is bounded by the official datasheet; EN and SEL straps still require design review | LTspice model listed; PSpice model not claimed | Manufacturer package drawing and CAD listed | Production | 1.41 | NO_EXACT_REVERSE_BLOCK_BACKUP_SELECTED | Prevents an externally driven sense pin from powering P3V3_AUX while preserving near-rail high-impedance sensing | Confirmed_Official | Populate | https://www.analog.com/en/products/adp198.html | Exact LFCSP pin map is confirmed; system reverse-drive test remains Planned
RSH1 | 1 | Vishay Dale | WSK25125L000FEA | 5 mOhm four-terminal current-sense resistor | WSK2512 Kelvin | 3.3 V rail | 5.01 A normal and 7.01 A for 100 us | Pending exact temperature-characteristic review | 0.1255 W at 5.01 A and 0.2457 W during the 7.01 A pulse | Passive model | Manufacturer ECAD listed | Active | 2.37 | NO_EXACT_DROP_IN_BACKUP_SELECTED | Four-terminal construction supports Kelvin measurement and the INA238 range | Confirmed_Official | Populate | https://www.vishay.com/docs/30108/wsk2512.pdf | Exact ordering identity is confirmed; land pattern pulse rating and hot tolerance remain review gates
L1 | 1 | Coilcraft | XGL5050-152MEC | 1.5 uH shielded power inductor | XGL5050 molded SMD | 12 V to 3.3 V conversion | 9.8 A Isat at 20 percent drop and 17.1 A Irms at 40 degC rise | Pending exact operating-temperature review | 4.7 mOhm typical DCR and 5.7 mOhm maximum DCR; calculated 7.909 A pulse peak | Passive model | Manufacturer land pattern listed | Active | 4.11 | XGL5050-182MEC after ripple and transient re-analysis | Matches the TPS543620 3.3 V 1 MHz recommended inductance and calculated peak-current margin | Confirmed_Official | Populate | https://www.coilcraft.com/en-us/products/power/shielded-inductors/molded-inductor/xgl/xgl5050/xgl5050-152/ | Exact footprint height hot inductance core loss and supply remain Power Design Gate items
FB1 | 1 | Murata | BLM21PG221SN1D | 220 ohm at 100 MHz telemetry-rail ferrite bead | 0805 metric 2012 | 3.3 V | Telemetry rail only; rated-current verification pending | -55 to 125 degC | DCR max 45 mOhm and rated current 2 A; impedance and DC-bias behavior require PI review | Passive model | Manufacturer land pattern listed | Active | 0.11 | RC0805JR-070RL only if PI review permits bead removal | Isolates telemetry noise without entering the NVMe load-current path | Confirmed_Official | Populate | https://www.murata.com/en-us/products/productdetail?partno=BLM21PG221SN1%23 | Do not release until the latest approval sheet and P3V3_AUX droop are reviewed
C1;C6;C7;C9;C15;C16;C17 | 7 | Murata | GRM155R71H104KE14D | 0.1 uF 50 V X7R bypass capacitor | 0402 metric 1005 | 50 V | Signal-dependent ripple current | -55 to 125 degC | Effective capacitance and placement depend on each local loop | Primitive C plus ESR and ESL corner | Manufacturer land pattern listed | Active | 0.10 | C1005X7R1H104K050BE | One exact candidate covers eFuse input buck HF and local IC bypass positions | Engineering_Assumption | Populate | https://www.murata.com/en-us/products/productdetail?partno=GRM155R71H104KE14%23 | C1 eFuse input; C6 and C7 buck VIN HF; C9 BOOT; C15 U3; C16 U4; C17 U5 VIN
C2 | 1 | Pending selection | TBD_AFTER_CEM_DVDT_REVIEW | eFuse dVdt programming capacitor | 0603 reserved | At least 25 V | Charge-current dependent | Pending_Human_Verification | Value must satisfy confirmed PCIe slot inrush and TPS25947 slew equations | Primitive C after value freeze | Generic 0603 land pattern | Pending_Human_Verification | TBD_AFTER_CEM | Exact alternative selected with final value | Reserved connection closes the schematic without pretending the inrush value is frozen | Pending_Human_Verification | Populate | https://www.ti.com/lit/ds/symlink/tps25947.pdf | Power Design Freeze blocker
C3 | 1 | Pending selection | TBD_AFTER_CEM_ITIMER_REVIEW | eFuse fault-timer programming capacitor | 0603 reserved | At least 25 V | Fault-blanking dependent | Pending_Human_Verification | Value must coordinate eFuse SOA buck inrush and confirmed slot limits | Primitive C after value freeze | Generic 0603 land pattern | Pending_Human_Verification | TBD_AFTER_CEM | Exact alternative selected with final value | Reserved connection closes the schematic while keeping fault timing uncommitted | Pending_Human_Verification | Populate | https://www.ti.com/lit/ds/symlink/tps25947.pdf | Power Design Freeze blocker
C4;C5 | 2 | TDK | C3225X7R1E106K250AC | 10 uF 25 V X7R buck input capacitor | 1210 metric 3225 | 25 V | Input-ripple dependent | -55 to 125 degC | Effective capacitance at 12 V and RMS ripple require current characteristic data | TDK equivalent-circuit and DC-bias data listed | Manufacturer land pattern listed | Production | 0.62 | CL32B106KAULNNE | Matches the TI local ceramic input baseline while preserving derating review | Engineering_Assumption | Populate | https://product.tdk.com/en/search/capacitor/ceramic/mlcc/info?part_no=C3225X7R1E106K250AC | Place directly between U2 VIN and PGND; exact retained capacitance is not yet frozen
C8 | 1 | Murata | GRM188R71A225KE15D | 2.2 uF 10 V X7R BP5 capacitor | 0603 metric 1608 | 10 V | Low current | -55 to 125 degC | TI reference application uses 2.2 uF on BP5 | Primitive C plus ESR and ESL corner | Manufacturer land pattern listed | Active | 0.15 | C1608X7R1A225K080AC | Implements the official TPS543620 3.3 V reference application | Engineering_Assumption | Populate | https://www.murata.com/en-us/products/productdetail?partno=GRM188R71A225KE15%23 | Exact MLCC characteristic and footprint audit remain pending
C10 | 1 | Murata | GRM1555C1H330JA01D | 33 pF 50 V C0G feed-forward capacitor | 0402 metric 1005 | 50 V | Low current | -55 to 125 degC | TI 3.3 V 1 MHz reference value; loop stability still requires model support | Primitive C plus parasitic corner | Manufacturer land pattern listed | Active | 0.10 | C1005C0G1H330J050BA | Implements the official reference starting point without claiming final loop closure | Engineering_Assumption | Populate | https://www.murata.com/en-us/products/productdetail?partno=GRM1555C1H330JA01%23 | May be DNI only after transient and loop review
C11;C12;C13;C14 | 4 | TDK | C3225X7R1C226M250AC | 22 uF 16 V X7R buck output capacitor | 1210 metric 3225 | 16 V | Output-ripple and transient dependent | -55 to 125 degC | 88 uF nominal with a 44 uF effective lower-bound assumption pending DC-bias confirmation | TDK equivalent-circuit and DC-bias data listed | Manufacturer land pattern listed | Production | 0.61 | GRM32ER71C226KEA8L | Four-device baseline improves layout distribution but does not by itself prove the 7 A pulse | Engineering_Assumption | Populate | https://product.tdk.com/en/search/capacitor/ceramic/mlcc/info?part_no=C3225X7R1C226M250AC | Place on P3V3_PRE_SENSE; exact DC-bias curve and PSpice transient are release gates
C18 | 1 | TDK | C1608X7R1C105K080AC | 1 uF 16 V X7R protected sense-output capacitor | 0603 metric 1608 | 16 V | Low current | -55 to 125 degC | ADP198 timing data uses a 1 uF load condition; short energy remains bounded by RISO1 | Primitive C plus ESR and ESL corner | Manufacturer land pattern listed | Production | 0.12 | C0603C105K4RAC | Provides a defined local load on the reverse-current-blocked sense path | Engineering_Assumption | Populate | https://product.tdk.com/en/search/capacitor/ceramic/mlcc/info?part_no=C1608X7R1C105K080AC | Verify turn-on and external short behavior on hardware
R1 | 1 | Pending selection | TBD_AFTER_CEM_EFUSE_UVLO_TOP | eFuse EN and UVLO upper-divider resistor | 0603 | 12 V | Low current | Pending_Human_Verification | Value depends on confirmed slot operating range and TPS25947 threshold tolerance | Primitive R after value freeze | Generic 0603 land pattern | Pending_Human_Verification | TBD_AFTER_CEM | Exact alternative selected with final value | Reserved so Capture connectivity is complete while the threshold stays unfrozen | Pending_Human_Verification | Populate | https://www.ti.com/lit/ds/symlink/tps25947.pdf | Power Design Freeze blocker
R2 | 1 | Pending selection | TBD_AFTER_CEM_EFUSE_UVLO_BOTTOM | eFuse EN and UVLO lower-divider resistor | 0603 | 12 V | Low current | Pending_Human_Verification | Value depends on confirmed slot operating range and TPS25947 threshold tolerance | Primitive R after value freeze | Generic 0603 land pattern | Pending_Human_Verification | TBD_AFTER_CEM | Exact alternative selected with final value | Reserved so Capture connectivity is complete while the threshold stays unfrozen | Pending_Human_Verification | Populate | https://www.ti.com/lit/ds/symlink/tps25947.pdf | Power Design Freeze blocker
R3 | 1 | Pending selection | TBD_AFTER_CEM_EFUSE_OVCSEL | eFuse OVCSEL programming resistor | 0603 | 12 V | Low current | Pending_Human_Verification | Value depends on the confirmed slot transient envelope and clamp coordination | Primitive R after value freeze | Generic 0603 land pattern | Pending_Human_Verification | TBD_AFTER_CEM | Exact alternative selected with final value | Reserved connection closes the symbol without inventing the clamp setting | Pending_Human_Verification | Populate | https://www.ti.com/lit/ds/symlink/tps25947.pdf | Power Design Freeze blocker
R4 | 1 | Pending selection | TBD_AFTER_CEM_EFUSE_PGTH_TOP | eFuse PGTH upper-divider resistor | 0603 | 12 V | Low current | Pending_Human_Verification | Value depends on approved power-good threshold and tolerance | Primitive R after value freeze | Generic 0603 land pattern | Pending_Human_Verification | TBD_AFTER_CEM | Exact alternative selected with final value | Reserved connection prevents an unconnected control pin without inventing a threshold | Pending_Human_Verification | Populate | https://www.ti.com/lit/ds/symlink/tps25947.pdf | Power Design Freeze blocker
R5 | 1 | Pending selection | TBD_AFTER_CEM_EFUSE_PGTH_BOTTOM | eFuse PGTH lower-divider resistor | 0603 | 12 V | Low current | Pending_Human_Verification | Value depends on approved power-good threshold and tolerance | Primitive R after value freeze | Generic 0603 land pattern | Pending_Human_Verification | TBD_AFTER_CEM | Exact alternative selected with final value | Reserved connection prevents an unconnected control pin without inventing a threshold | Pending_Human_Verification | Populate | https://www.ti.com/lit/ds/symlink/tps25947.pdf | Power Design Freeze blocker
R6 | 1 | Pending selection | TBD_AFTER_CEM_EFUSE_ILIM | eFuse current-limit programming resistor | 0603 | Analog control | Low current | Pending_Human_Verification | Use RILM equals 3334 divided by ILIM only after slot and downstream coordination | Primitive R after value freeze | Generic 0603 land pattern | Pending_Human_Verification | TBD_AFTER_CEM | Exact alternative selected with final value | Explicitly keeps the safety-critical current limit outside the unverified baseline | Pending_Human_Verification | Populate | https://www.ti.com/lit/ds/symlink/tps25947.pdf | Power Design Freeze blocker
R7;R14;R17;R18 | 4 | Yageo | RC0603FR-0710KL | 10 kOhm 1 percent pull-up resistor | 0603 metric 1608 | 3.3 V | Low current | -55 to 155 degC | PG and ALERT open-drain pull-ups; bus loading must be reviewed | Primitive R | Manufacturer land pattern listed | Active | 0.10 | CRG0603F10K | R7 pulls PGOOD_12V and R14 pulls PGOOD_3V3 while R17 and R18 pull ALERT nets | Engineering_Assumption | Populate | https://www.yageo.com/en/ProductSearch/PartNumberSearch?partnumber=RC0603FR-0710KL | Pull-up source is P3V3_AUX
R8 | 1 | Yageo | RC0603FR-0711K8L | 11.8 kOhm 1 percent TPS543620 frequency-select resistor | 0603 metric 1608 | Analog control | Low current | -55 to 155 degC | TI 3.3 V reference application selects nominal 1 MHz | Primitive R | Manufacturer land pattern listed | Active | 0.10 | EXACT_SECOND_SOURCE_PENDING_AVL | Uses the official 1 MHz starting point for the Rev A calculations | Engineering_Assumption | Populate | https://www.ti.com/lit/ds/symlink/tps543620.pdf | Re-evaluate if EMI thermal or transient results change switching frequency
R9 | 1 | Yageo | RC0603FR-0711K3L | 11.3 kOhm 1 percent TPS543620 MODE resistor | 0603 metric 1608 | Analog control | Low current | -55 to 155 degC | Selects high current limit CRAMP 4 pF and 1 ms soft-start per TI Table 7-4 | Primitive R | Manufacturer land pattern listed | Active | 0.10 | EXACT_SECOND_SOURCE_PENDING_AVL | Matches the official 3.3 V 1 MHz reference application | Engineering_Assumption | Populate | https://www.ti.com/lit/ds/symlink/tps543620.pdf | 7 A pulse remains a PSpice criterion and not a proven capability
R10 | 1 | Yageo | RC0603FR-0716K9L | 16.9 kOhm 1 percent buck EN upper-divider resistor | 0603 metric 1608 | 12 V | Low current | -55 to 155 degC | TI 3.3 V reference application starting value | Primitive R | Manufacturer land pattern listed | Active | 0.10 | EXACT_SECOND_SOURCE_PENDING_AVL | Provides a datasheet-backed baseline while eFuse ramp coordination remains planned | Engineering_Assumption | Populate | https://www.ti.com/lit/ds/symlink/tps543620.pdf | Verify start threshold and no oscillatory interaction with eFuse
R11 | 1 | Yageo | RC0603FR-076K04L | 6.04 kOhm 1 percent buck EN lower-divider resistor | 0603 metric 1608 | 12 V | Low current | -55 to 155 degC | TI 3.3 V reference application starting value | Primitive R | Manufacturer land pattern listed | Active | 0.10 | EXACT_SECOND_SOURCE_PENDING_AVL | Provides a datasheet-backed baseline while eFuse ramp coordination remains planned | Engineering_Assumption | Populate | https://www.ti.com/lit/ds/symlink/tps543620.pdf | Verify start threshold and no oscillatory interaction with eFuse
R12 | 1 | Yageo | RC0603FR-0728KL | 28.0 kOhm 1 percent buck feedback upper resistor | 0603 metric 1608 | 3.3 V | Low current | -55 to 155 degC | Remote senses P3V3_NVME after the 5 mOhm shunt | Primitive R | Manufacturer land pattern listed | Active | 0.10 | EXACT_SECOND_SOURCE_PENDING_AVL | Matches the TI 3.3 V reference ratio and compensates nominal shunt drop at the load | Engineering_Assumption | Populate | https://www.ti.com/lit/ds/symlink/tps543620.pdf | Kelvin routing and loop stability are release gates
R13 | 1 | Yageo | RC0603FR-074K99L | 4.99 kOhm 1 percent buck feedback lower resistor | 0603 metric 1608 | 3.3 V | Low current | -55 to 155 degC | Remote feedback ratio yields about 3.305 V nominal before tolerance | Primitive R | Manufacturer land pattern listed | Active | 0.10 | EXACT_SECOND_SOURCE_PENDING_AVL | Matches the official TPS543620 3.3 V reference application | Engineering_Assumption | Populate | https://www.ti.com/lit/ds/symlink/tps543620.pdf | Final tolerance profile must include resistor and reference error
R15;R16 | 2 | Yageo | RC0603FR-074K7L | 4.7 kOhm 1 percent I2C pull-up resistor | 0603 metric 1608 | 3.3 V | Low current | -55 to 155 degC | Value depends on cable bus capacitance and selected clock | Primitive R | Manufacturer land pattern listed | Active | 0.10 | EXACT_SECOND_SOURCE_PENDING_AVL | Provides local pull-ups for the independent debug bus | Engineering_Assumption | Populate | https://www.ti.com/lit/ds/symlink/ina238.pdf | Do not connect to host PCIe SMBus
R19 | 1 | Yageo | RC0603FR-071KL | 1 kOhm 1 percent LED current-limit resistor | 0603 metric 1608 | 3.3 V | Approximately 1 mA pending LED Vf | -55 to 155 degC | Indicator current must not load the PGOOD open-drain node directly | Primitive R | Manufacturer land pattern listed | Active | 0.10 | EXACT_SECOND_SOURCE_PENDING_AVL | Drives D1 through Q1 so TP6 remains the authoritative logic node | Engineering_Assumption | Populate | https://www.diodes.com/datasheet/download/2N7002.pdf | Confirm brightness and current before assembly release
RISO1 | 1 | Yageo | RC0603FR-0710KL | 10 kOhm 1 percent header sense current-limiter | 0603 metric 1608 | 3.3 V | 0.33 mA nominal short-current upper estimate | -55 to 155 degC | Must preserve high-impedance measurement accuracy and bound an accidental short | Primitive R | Manufacturer land pattern listed | Active | 0.10 | CRG0603F10K | Works after U5 reverse-current blocking and is not a power-delivery path | Engineering_Assumption | Populate | https://www.analog.com/media/en/technical-documentation/data-sheets/adp198.pdf | Verify with the intended meter and reverse-drive test
Q1 | 1 | Diodes Incorporated | 2N7002-7-F | Small-signal N-channel MOSFET for PGOOD LED buffer | SOT-23 | 60 V VDS | 0.21 A at 25 degC | -55 to 150 degC junction | 3.3 V gate operation is used only for the low-current indicator | Vendor SPICE model listed | Manufacturer land pattern listed | Active | 0.20 | 2N7002ET1G after pin-map audit | Prevents the LED branch from directly loading the TPS543620 PGOOD node | Confirmed_Official | Populate | https://www.diodes.com/part/view/2N7002 | Pin map and low-current operation require local symbol audit
D1 | 1 | Lite-On | LTST-C190KGKT | Green PGOOD indicator LED | 0603 metric 1608 | 3.3 V through R19 | Approximately 1 mA | -55 to 85 degC | Forward voltage brightness and polarity require incoming inspection | No model required | Manufacturer land pattern listed | Active | 0.15 | SML-E12M8WT86 after brightness and polarity review | Visual indicator only; TP6 remains authoritative | Pending_Human_Verification | Populate | https://optoelectronics.liteon.com/en-global/Led/led-component | Verify exact datasheet revision polarity and brightness before purchase
D2 | 1 | Littelfuse | SMBJ14A | Optional unidirectional 14 V TVS footprint | DO-214AA SMB | 12 V rail | Transient-dependent | -65 to 150 degC junction | Standoff clamp energy and TPS25947 absolute maximum require joint review | Vendor model availability pending | Manufacturer land pattern listed | Active | 0.00 | None if eFuse-only protection is approved | Provides an explicit DNP option without claiming a valid PCIe slot transient solution | Pending_Human_Verification | DNP | https://www.littelfuse.com/products/tvs-diodes/surface-mount/smbj.aspx | Cost is zero only because Rev A disposition is DNP; do not populate until clamp coordination is reviewed
J3 | 1 | Samtec | TSW-104-08-L-S-RA | Right-angle 1x4 2.54 mm I2C debug header | Through-hole right-angle | 3.3 V sense only | Signal plus low-current sense | -55 to 125 degC family dependent | Pin 4 is sense output and must never accept external power | Not applicable | Manufacturer footprint available | Active | 0.82 | NO_EXACT_DROP_IN_BACKUP_SELECTED | Accessible independent telemetry interface without MCU or host SMBus connection | Pending_Human_Verification | Populate | https://www.samtec.com/products/tsw | Exact plating and tail option must be verified before order
TP1; TP2; TP3; TP4; TP5; TP6; TP7; TP8; TP9 | 9 | Harwin | S1751-46R | Surface-mount test point | SMT loop | Per test node | Instrument probe only | -40 to 125 degC family dependent | Accessibility and creepage checked in placement review | Not applicable | Manufacturer footprint available | Active | 0.30 | Keystone 5006 after land-pattern review | Provides repeatable access to five rails plus PGOOD two alert nets and probe ground | Pending_Human_Verification | Populate | https://www.harwin.com/products/S1751-46R/ | TP1 P12V_SLOT; TP2 P12V_PROTECTED; TP3 P3V3_PRE_SENSE; TP4 P3V3_NVME; TP5 P3V3_AUX; TP6 PGOOD_3V3; TP7 INA_ALERT_N; TP8 TEMP_ALERT_N; TP9 GND
MH1 | 1 | Pending mechanical vendor | TBD_M2_2280_STANDOFF | M.2 2280 standoff and M2 screw | Mechanical hardware | Not applicable | Mechanical retention | Pending_Human_Verification | Height thread plating torque and keepout require connector stack review | Not applicable | Mechanical drawing required | Pending_Human_Verification | Quote_Required | NO_EXACT_BACKUP_BEFORE_STACK_HEIGHT_FREEZE | Required module retention | Pending_Human_Verification | Mechanical | TBD | Do not substitute M2.5 hardware
BR1 | 1 | Pending mechanical vendor | CUSTOM_LOW_PROFILE_PCIE_BRACKET | Low-profile PCIe bracket and fasteners | Mechanical hardware | Not applicable | Mechanical retention | Pending_Human_Verification | CEM hole position thickness material and chassis fit require drawing review | Not applicable | Custom drawing required | Pending_Human_Verification | Quote_Required | NO_STANDARD_DROP_IN_BACKUP | Defines card retention and prevents connector stress | Pending_Human_Verification | Mechanical | TBD | 3D interference and chassis fit remain open

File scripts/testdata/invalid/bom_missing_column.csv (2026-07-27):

Reference_Designator | Quantity | Manufacturer | Manufacturer_Part_Number | Description | Package | Lifecycle | Alternative_Part
U1 | 1 | Texas Instruments | TPS543620RPYR | 6 A synchronous buck | VQFN-HR-14 | Active | TPSM843620SITR

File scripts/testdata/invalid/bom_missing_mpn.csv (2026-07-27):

Reference_Designator | Quantity | Manufacturer | Manufacturer_Part_Number | Description | Package | Lifecycle | Datasheet_Review_Status | Alternative_Part
U1 | 1 | Texas Instruments |  | 6 A synchronous buck | VQFN-HR-14 | Active | Confirmed_Official | TPSM843620SITR

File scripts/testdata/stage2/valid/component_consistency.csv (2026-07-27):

Reference | BOM_Present | Symbol_Pin_Count | Footprint_Pad_Count | Netlist_Present | Allegro_Present | Placed | Inside_Board | Status | Evidence
U1 | YES | 10 | 10 | YES | YES | YES | YES | Engineering_Assumption | component_report.csv

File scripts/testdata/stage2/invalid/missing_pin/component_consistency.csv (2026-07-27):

Reference | BOM_Present | Symbol_Pin_Count | Footprint_Pad_Count | Netlist_Present | Allegro_Present | Placed | Inside_Board | Status | Evidence
J1 | YES | 0 | 0 | YES | YES | YES | YES | Pending_Human_Verification | component_report.csv

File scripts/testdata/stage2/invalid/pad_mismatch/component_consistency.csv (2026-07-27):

Reference | BOM_Present | Symbol_Pin_Count | Footprint_Pad_Count | Netlist_Present | Allegro_Present | Placed | Inside_Board | Status | Evidence
U1 | YES | 10 | 9 | YES | YES | YES | YES | Engineering_Assumption | component_report.csv

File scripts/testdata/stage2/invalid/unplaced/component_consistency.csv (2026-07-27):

Reference | BOM_Present | Symbol_Pin_Count | Footprint_Pad_Count | Netlist_Present | Allegro_Present | Placed | Inside_Board | Status | Evidence
U1 | YES | 10 | 10 | YES | YES | NO | YES | Engineering_Assumption | component_report.csv

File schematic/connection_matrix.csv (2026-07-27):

Source_Component | Source_Pin | Source_Pin_Name | Net_Name | Destination_Component | Destination_Pin | Destination_Pin_Name | Signal_Type | Voltage_Domain | Differential_Pair_Name | Direction | Source_Document | Human_Review_Status | Notes
J1 | B14 | PCIE_TX0_P | PCIE_TX0_P | J2 | 49 | PCIE_RX0_P | PCIE_GEN3_DIFF | PCIE_HS | PCIE_TX0 | HOST_TO_DEVICE | PCI-SIG_CEM_3.0;M2_CONTROLLED_SPEC;NVIDIA_PUBLIC_REFERENCE_DESIGN;NVIDIA_SP-10900-001_v1.2_Table_2-8;Controlled_CEM_Review_Required;NVIDIA_SP-10900-001_v1.2_Table_2-13;Controlled_M2_Review_Required | Engineering_Assumption | Exact pin uses a public-source baseline; governing controlled specification or footprint cross-probe review remains open
J1 | B15 | PCIE_TX0_N | PCIE_TX0_N | J2 | 47 | PCIE_RX0_N | PCIE_GEN3_DIFF | PCIE_HS | PCIE_TX0 | HOST_TO_DEVICE | PCI-SIG_CEM_3.0;M2_CONTROLLED_SPEC;NVIDIA_PUBLIC_REFERENCE_DESIGN;NVIDIA_SP-10900-001_v1.2_Table_2-8;Controlled_CEM_Review_Required;NVIDIA_SP-10900-001_v1.2_Table_2-13;Controlled_M2_Review_Required | Engineering_Assumption | Exact pin uses a public-source baseline; governing controlled specification or footprint cross-probe review remains open
J2 | 43 | PCIE_TX0_P | PCIE_RX0_P | J1 | A16 | PCIE_RX0_P | PCIE_GEN3_DIFF | PCIE_HS | PCIE_RX0 | DEVICE_TO_HOST | PCI-SIG_CEM_3.0;M2_CONTROLLED_SPEC;NVIDIA_PUBLIC_REFERENCE_DESIGN;NVIDIA_SP-10900-001_v1.2_Table_2-8;Controlled_CEM_Review_Required;NVIDIA_SP-10900-001_v1.2_Table_2-13;Controlled_M2_Review_Required | Engineering_Assumption | Exact pin uses a public-source baseline; governing controlled specification or footprint cross-probe review remains open
J2 | 41 | PCIE_TX0_N | PCIE_RX0_N | J1 | A17 | PCIE_RX0_N | PCIE_GEN3_DIFF | PCIE_HS | PCIE_RX0 | DEVICE_TO_HOST | PCI-SIG_CEM_3.0;M2_CONTROLLED_SPEC;NVIDIA_PUBLIC_REFERENCE_DESIGN;NVIDIA_SP-10900-001_v1.2_Table_2-8;Controlled_CEM_Review_Required;NVIDIA_SP-10900-001_v1.2_Table_2-13;Controlled_M2_Review_Required | Engineering_Assumption | Exact pin uses a public-source baseline; governing controlled specification or footprint cross-probe review remains open
J1 | B19 | PCIE_TX1_P | PCIE_TX1_P | J2 | 37 | PCIE_RX1_P | PCIE_GEN3_DIFF | PCIE_HS | PCIE_TX1 | HOST_TO_DEVICE | PCI-SIG_CEM_3.0;M2_CONTROLLED_SPEC;NVIDIA_PUBLIC_REFERENCE_DESIGN;NVIDIA_SP-10900-001_v1.2_Table_2-8;Controlled_CEM_Review_Required;NVIDIA_SP-10900-001_v1.2_Table_2-13;Controlled_M2_Review_Required | Engineering_Assumption | Exact pin uses a public-source baseline; governing controlled specification or footprint cross-probe review remains open
J1 | B20 | PCIE_TX1_N | PCIE_TX1_N | J2 | 35 | PCIE_RX1_N | PCIE_GEN3_DIFF | PCIE_HS | PCIE_TX1 | HOST_TO_DEVICE | PCI-SIG_CEM_3.0;M2_CONTROLLED_SPEC;NVIDIA_PUBLIC_REFERENCE_DESIGN;NVIDIA_SP-10900-001_v1.2_Table_2-8;Controlled_CEM_Review_Required;NVIDIA_SP-10900-001_v1.2_Table_2-13;Controlled_M2_Review_Required | Engineering_Assumption | Exact pin uses a public-source baseline; governing controlled specification or footprint cross-probe review remains open
J2 | 31 | PCIE_TX1_P | PCIE_RX1_P | J1 | A21 | PCIE_RX1_P | PCIE_GEN3_DIFF | PCIE_HS | PCIE_RX1 | DEVICE_TO_HOST | PCI-SIG_CEM_3.0;M2_CONTROLLED_SPEC;NVIDIA_PUBLIC_REFERENCE_DESIGN;NVIDIA_SP-10900-001_v1.2_Table_2-8;Controlled_CEM_Review_Required;NVIDIA_SP-10900-001_v1.2_Table_2-13;Controlled_M2_Review_Required | Engineering_Assumption | Exact pin uses a public-source baseline; governing controlled specification or footprint cross-probe review remains open
J2 | 29 | PCIE_TX1_N | PCIE_RX1_N | J1 | A22 | PCIE_RX1_N | PCIE_GEN3_DIFF | PCIE_HS | PCIE_RX1 | DEVICE_TO_HOST | PCI-SIG_CEM_3.0;M2_CONTROLLED_SPEC;NVIDIA_PUBLIC_REFERENCE_DESIGN;NVIDIA_SP-10900-001_v1.2_Table_2-8;Controlled_CEM_Review_Required;NVIDIA_SP-10900-001_v1.2_Table_2-13;Controlled_M2_Review_Required | Engineering_Assumption | Exact pin uses a public-source baseline; governing controlled specification or footprint cross-probe review remains open
J1 | B23 | PCIE_TX2_P | PCIE_TX2_P | J2 | 25 | PCIE_RX2_P | PCIE_GEN3_DIFF | PCIE_HS | PCIE_TX2 | HOST_TO_DEVICE | PCI-SIG_CEM_3.0;M2_CONTROLLED_SPEC;NVIDIA_PUBLIC_REFERENCE_DESIGN;NVIDIA_SP-10900-001_v1.2_Table_2-8;Controlled_CEM_Review_Required;NVIDIA_SP-10900-001_v1.2_Table_2-13;Controlled_M2_Review_Required | Engineering_Assumption | Exact pin uses a public-source baseline; governing controlled specification or footprint cross-probe review remains open
J1 | B24 | PCIE_TX2_N | PCIE_TX2_N | J2 | 23 | PCIE_RX2_N | PCIE_GEN3_DIFF | PCIE_HS | PCIE_TX2 | HOST_TO_DEVICE | PCI-SIG_CEM_3.0;M2_CONTROLLED_SPEC;NVIDIA_PUBLIC_REFERENCE_DESIGN;NVIDIA_SP-10900-001_v1.2_Table_2-8;Controlled_CEM_Review_Required;NVIDIA_SP-10900-001_v1.2_Table_2-13;Controlled_M2_Review_Required | Engineering_Assumption | Exact pin uses a public-source baseline; governing controlled specification or footprint cross-probe review remains open
J2 | 19 | PCIE_TX2_P | PCIE_RX2_P | J1 | A25 | PCIE_RX2_P | PCIE_GEN3_DIFF | PCIE_HS | PCIE_RX2 | DEVICE_TO_HOST | PCI-SIG_CEM_3.0;M2_CONTROLLED_SPEC;NVIDIA_PUBLIC_REFERENCE_DESIGN;NVIDIA_SP-10900-001_v1.2_Table_2-8;Controlled_CEM_Review_Required;NVIDIA_SP-10900-001_v1.2_Table_2-13;Controlled_M2_Review_Required | Engineering_Assumption | Exact pin uses a public-source baseline; governing controlled specification or footprint cross-probe review remains open
J2 | 17 | PCIE_TX2_N | PCIE_RX2_N | J1 | A26 | PCIE_RX2_N | PCIE_GEN3_DIFF | PCIE_HS | PCIE_RX2 | DEVICE_TO_HOST | PCI-SIG_CEM_3.0;M2_CONTROLLED_SPEC;NVIDIA_PUBLIC_REFERENCE_DESIGN;NVIDIA_SP-10900-001_v1.2_Table_2-8;Controlled_CEM_Review_Required;NVIDIA_SP-10900-001_v1.2_Table_2-13;Controlled_M2_Review_Required | Engineering_Assumption | Exact pin uses a public-source baseline; governing controlled specification or footprint cross-probe review remains open
J1 | B27 | PCIE_TX3_P | PCIE_TX3_P | J2 | 13 | PCIE_RX3_P | PCIE_GEN3_DIFF | PCIE_HS | PCIE_TX3 | HOST_TO_DEVICE | PCI-SIG_CEM_3.0;M2_CONTROLLED_SPEC;NVIDIA_PUBLIC_REFERENCE_DESIGN;NVIDIA_SP-10900-001_v1.2_Table_2-8;Controlled_CEM_Review_Required;NVIDIA_SP-10900-001_v1.2_Table_2-13;Controlled_M2_Review_Required | Engineering_Assumption | Exact pin uses a public-source baseline; governing controlled specification or footprint cross-probe review remains open
J1 | B28 | PCIE_TX3_N | PCIE_TX3_N | J2 | 11 | PCIE_RX3_N | PCIE_GEN3_DIFF | PCIE_HS | PCIE_TX3 | HOST_TO_DEVICE | PCI-SIG_CEM_3.0;M2_CONTROLLED_SPEC;NVIDIA_PUBLIC_REFERENCE_DESIGN;NVIDIA_SP-10900-001_v1.2_Table_2-8;Controlled_CEM_Review_Required;NVIDIA_SP-10900-001_v1.2_Table_2-13;Controlled_M2_Review_Required | Engineering_Assumption | Exact pin uses a public-source baseline; governing controlled specification or footprint cross-probe review remains open
J2 | 7 | PCIE_TX3_P | PCIE_RX3_P | J1 | A29 | PCIE_RX3_P | PCIE_GEN3_DIFF | PCIE_HS | PCIE_RX3 | DEVICE_TO_HOST | PCI-SIG_CEM_3.0;M2_CONTROLLED_SPEC;NVIDIA_PUBLIC_REFERENCE_DESIGN;NVIDIA_SP-10900-001_v1.2_Table_2-8;Controlled_CEM_Review_Required;NVIDIA_SP-10900-001_v1.2_Table_2-13;Controlled_M2_Review_Required | Engineering_Assumption | Exact pin uses a public-source baseline; governing controlled specification or footprint cross-probe review remains open
J2 | 5 | PCIE_TX3_N | PCIE_RX3_N | J1 | A30 | PCIE_RX3_N | PCIE_GEN3_DIFF | PCIE_HS | PCIE_RX3 | DEVICE_TO_HOST | PCI-SIG_CEM_3.0;M2_CONTROLLED_SPEC;NVIDIA_PUBLIC_REFERENCE_DESIGN;NVIDIA_SP-10900-001_v1.2_Table_2-8;Controlled_CEM_Review_Required;NVIDIA_SP-10900-001_v1.2_Table_2-13;Controlled_M2_Review_Required | Engineering_Assumption | Exact pin uses a public-source baseline; governing controlled specification or footprint cross-probe review remains open
J1 | A13 | PCIE_REFCLK_P | PCIE_REFCLK_P | J2 | 55 | PCIE_REFCLK_P | PCIE_REFCLK_DIFF | PCIE_CLOCK | PCIE_REFCLK | HOST_TO_DEVICE | PCI-SIG_CEM_3.0;M2_CONTROLLED_SPEC;NVIDIA_PUBLIC_REFERENCE_DESIGN;NVIDIA_SP-10900-001_v1.2_Table_2-8;Controlled_CEM_Review_Required;NVIDIA_SP-10900-001_v1.2_Table_2-13;Controlled_M2_Review_Required | Engineering_Assumption | Exact pin uses a public-source baseline; governing controlled specification or footprint cross-probe review remains open
J1 | A14 | PCIE_REFCLK_N | PCIE_REFCLK_N | J2 | 53 | PCIE_REFCLK_N | PCIE_REFCLK_DIFF | PCIE_CLOCK | PCIE_REFCLK | HOST_TO_DEVICE | PCI-SIG_CEM_3.0;M2_CONTROLLED_SPEC;NVIDIA_PUBLIC_REFERENCE_DESIGN;NVIDIA_SP-10900-001_v1.2_Table_2-8;Controlled_CEM_Review_Required;NVIDIA_SP-10900-001_v1.2_Table_2-13;Controlled_M2_Review_Required | Engineering_Assumption | Exact pin uses a public-source baseline; governing controlled specification or footprint cross-probe review remains open
J1 | A11 | PERST_N | PCIE_PERST_N | J2 | 50 | PERST_N | PCIE_SIDEBAND | PCIE_SIDEBAND |  | HOST_TO_DEVICE | PCI-SIG_CEM_3.0;M2_CONTROLLED_SPEC;NVIDIA_PUBLIC_REFERENCE_DESIGN;NVIDIA_SP-10900-001_v1.2_Table_2-8;Controlled_CEM_Review_Required;NVIDIA_SP-10900-001_v1.2_Table_2-13;Controlled_M2_Review_Required | Engineering_Assumption | Exact pin uses a public-source baseline; governing controlled specification or footprint cross-probe review remains open
J2 | 52 | CLKREQ_N | PCIE_CLKREQ_N | J1 | B12 | CLKREQ_N | PCIE_SIDEBAND_OPEN_DRAIN | PCIE_SIDEBAND |  | DEVICE_TO_HOST | PCI-SIG_CEM_3.0;M2_CONTROLLED_SPEC;NVIDIA_PUBLIC_REFERENCE_DESIGN;NVIDIA_SP-10900-001_v1.2_Table_2-8;Controlled_CEM_Review_Required;NVIDIA_SP-10900-001_v1.2_Table_2-13;Controlled_M2_Review_Required | Engineering_Assumption | Exact pin uses a public-source baseline; governing controlled specification or footprint cross-probe review remains open
J2 | 54 | PEWAKE_N | PCIE_PEWAKE_N | J1 | B11 | PEWAKE_N | PCIE_SIDEBAND_OPEN_DRAIN | PCIE_SIDEBAND |  | DEVICE_TO_HOST | PCI-SIG_CEM_3.0;M2_CONTROLLED_SPEC;NVIDIA_PUBLIC_REFERENCE_DESIGN;NVIDIA_SP-10900-001_v1.2_Table_2-8;Controlled_CEM_Review_Required;NVIDIA_SP-10900-001_v1.2_Table_2-13;Controlled_M2_Review_Required | Engineering_Assumption | Exact pin uses a public-source baseline; governing controlled specification or footprint cross-probe review remains open
J1 | A1 | PRSNT_A | PCIE_PRSNT_N | J1 | B31 | PRSNT_B | PCIE_PRESENCE | PCIE_SIDEBAND |  | PASSIVE | PCI-SIG_CEM_3.0;NVIDIA_SP-10900-001_v1.2_Table_2-8;Controlled_CEM_Review_Required | Engineering_Assumption | Exact pin uses a public-source baseline; governing controlled specification or footprint cross-probe review remains open
J1 | A2 | P12V_PIN_SET | P12V_SLOT | U1 | 5 | IN | POWER | 12V |  | POWER | PCI-SIG_CEM_3.0;TI_TPS25947_REV_C;NVIDIA_SP-10900-001_v1.2_Table_2-8;Controlled_CEM_Review_Required | Engineering_Assumption | Exact pin uses a public-source baseline; governing controlled specification or footprint cross-probe review remains open
J1 | A3 | P12V_PIN_SET | P12V_SLOT | U1 | 5 | IN | POWER | 12V |  | POWER | PCI-SIG_CEM_3.0;TI_TPS25947_REV_C;NVIDIA_SP-10900-001_v1.2_Table_2-8;Controlled_CEM_Review_Required | Engineering_Assumption | Exact pin uses a public-source baseline; governing controlled specification or footprint cross-probe review remains open
J1 | B1 | P12V_PIN_SET | P12V_SLOT | U1 | 5 | IN | POWER | 12V |  | POWER | PCI-SIG_CEM_3.0;TI_TPS25947_REV_C;NVIDIA_SP-10900-001_v1.2_Table_2-8;Controlled_CEM_Review_Required | Engineering_Assumption | Exact pin uses a public-source baseline; governing controlled specification or footprint cross-probe review remains open
J1 | B2 | P12V_PIN_SET | P12V_SLOT | U1 | 5 | IN | POWER | 12V |  | POWER | PCI-SIG_CEM_3.0;TI_TPS25947_REV_C;NVIDIA_SP-10900-001_v1.2_Table_2-8;Controlled_CEM_Review_Required | Engineering_Assumption | Exact pin uses a public-source baseline; governing controlled specification or footprint cross-probe review remains open
J1 | B3 | P12V_PIN_SET | P12V_SLOT | U1 | 5 | IN | POWER | 12V |  | POWER | PCI-SIG_CEM_3.0;TI_TPS25947_REV_C;NVIDIA_SP-10900-001_v1.2_Table_2-8;Controlled_CEM_Review_Required | Engineering_Assumption | Exact pin uses a public-source baseline; governing controlled specification or footprint cross-probe review remains open
U1 | 6 | OUT | P12V_PROTECTED | U2 | 8 | VIN | POWER | 12V |  | POWER | TI_TPS25947_REV_C;TI_TPS543620_REV_C | Engineering_Assumption | U1 OUT and U2 VIN pin functions are official; this board-level connection is the selected architecture
U1 | 6 | OUT | P12V_PROTECTED | U2 | 12 | VIN | POWER | 12V |  | POWER | TI_TPS25947_REV_C;TI_TPS543620_REV_C | Engineering_Assumption | U1 OUT and U2 VIN pin functions are official; this board-level connection is the selected architecture
U2 | 10 | SW | SW_3V3 | L1 | 1 | POWER_IN | SWITCH_NODE | 12V_SWITCHING |  | POWER | TI_TPS543620_REV_C | Engineering_Assumption | U2 SW pin function is official; L1 local footprint pin numbering still requires audit
U2 | 13 | SW | SW_3V3 | L1 | 1 | POWER_IN | SWITCH_NODE | 12V_SWITCHING |  | POWER | TI_TPS543620_REV_C | Engineering_Assumption | U2 SW pin function is official; this board-level power-stage connection requires layout review
L1 | 2 | POWER_OUT | P3V3_PRE_SENSE | RSH1 | I1 | FORCE_IN | POWER | 3V3 |  | POWER | TI_TPS543620_REV_C;VISHAY_WSK2512_DATASHEET;VISHAY_WSK2512_30108_REV_2023-12-11 | Engineering_Assumption | Exact pin uses a public-source baseline; governing controlled specification or footprint cross-probe review remains open
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

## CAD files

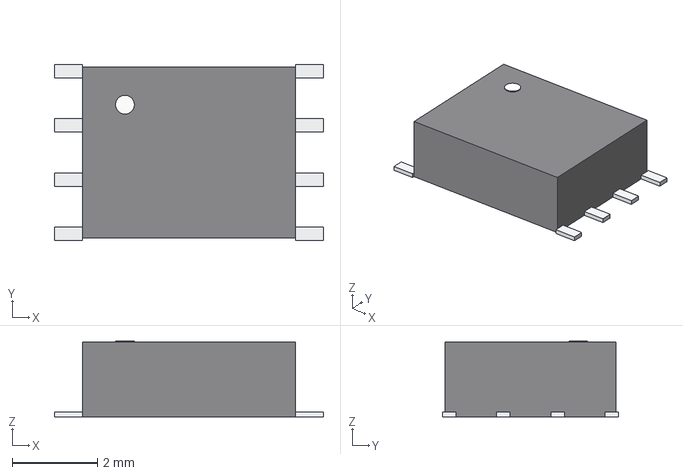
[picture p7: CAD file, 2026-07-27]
pcb/3d_models/stage3/ti_d8_soic.step
6.30 x 4.13 x 1.77 mm

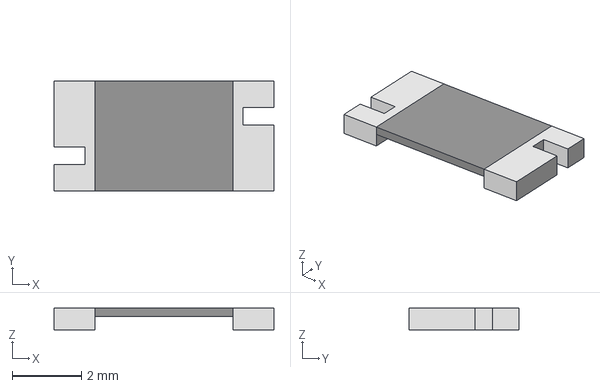
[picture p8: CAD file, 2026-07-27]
pcb/3d_models/vishay_wsk2512_0p005_to_0p2_vendor_30323_2026-07-25.stp
6.35 x 3.18 x 0.635 mm

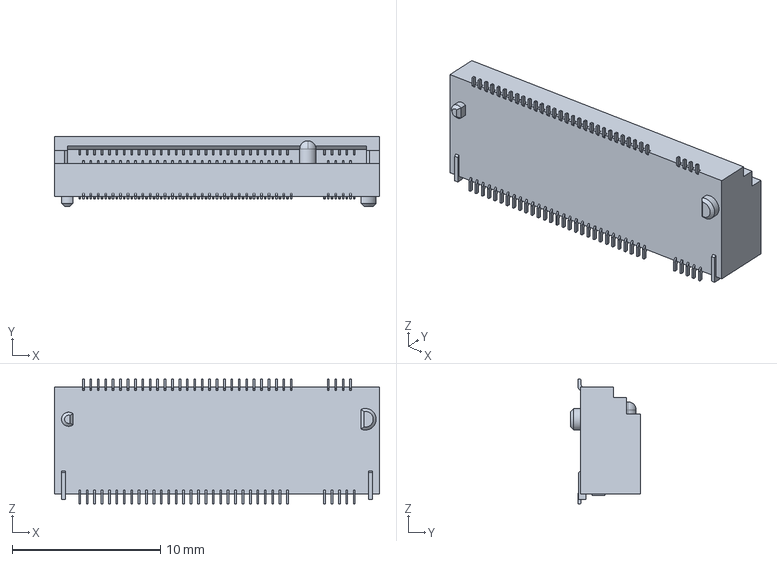
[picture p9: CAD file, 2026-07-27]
pcb/3d_models/amphenol_mdt420m01501_vendor-c3d-rev-unstated_2026-07-24.stp
21.9 x 4.70 x 8.40 mm

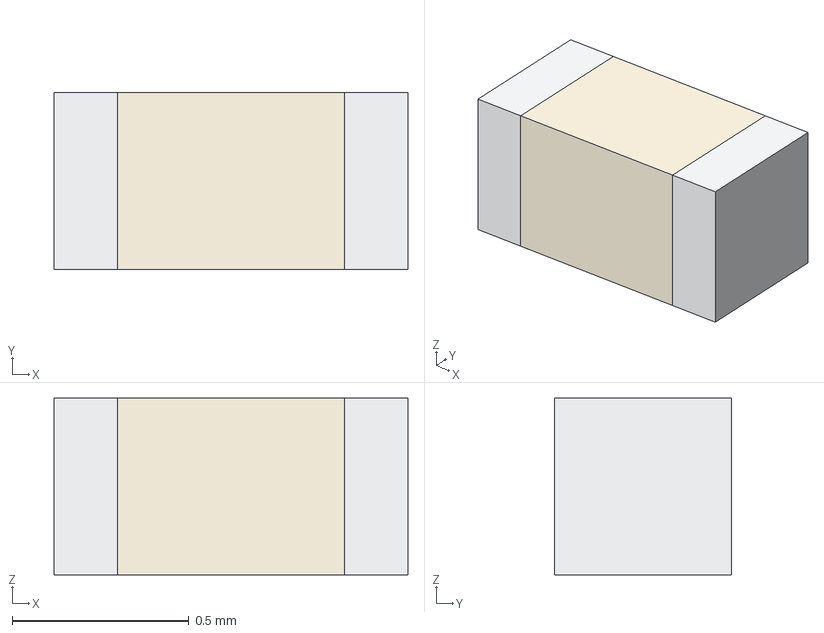
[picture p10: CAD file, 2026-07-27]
pcb/3d_models/stage3/c_0402_1005m.step
1.00 x 0.5 x 0.5 mm

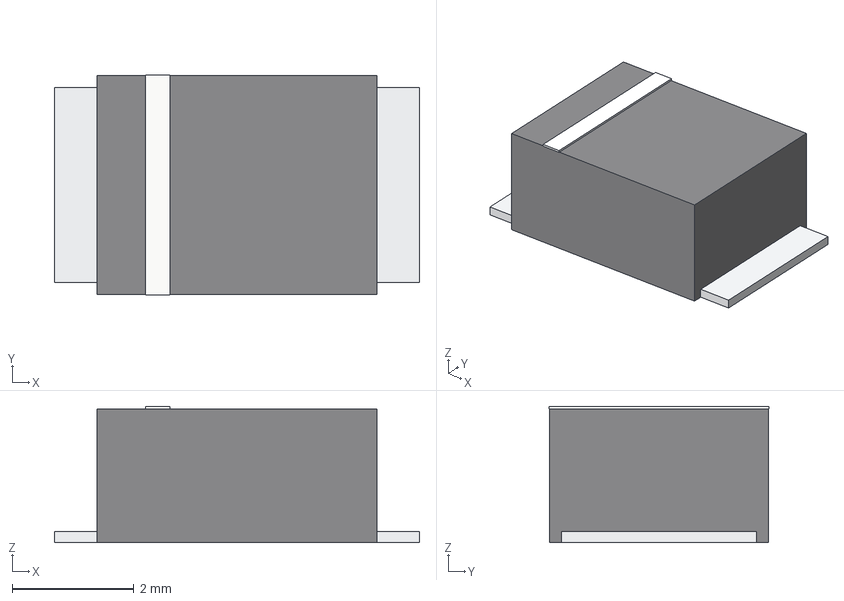
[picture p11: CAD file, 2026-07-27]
pcb/3d_models/stage3/do214aa_smb.step
6.00 x 3.62 x 2.24 mm

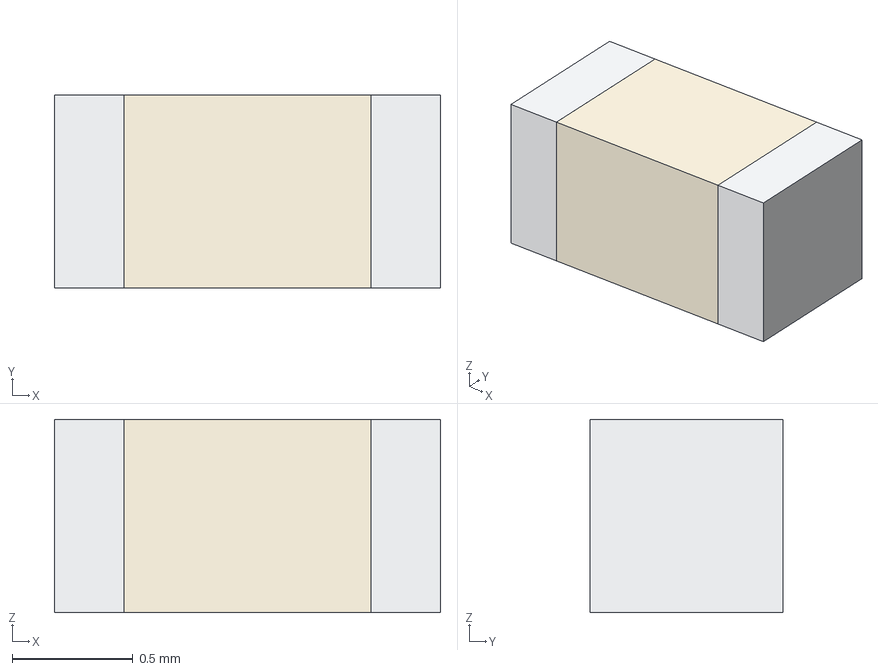
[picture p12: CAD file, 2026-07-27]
pcb/3d_models/stage3/c_0603_1608m_reserved.step
1.60 x 0.8 x 0.8 mm

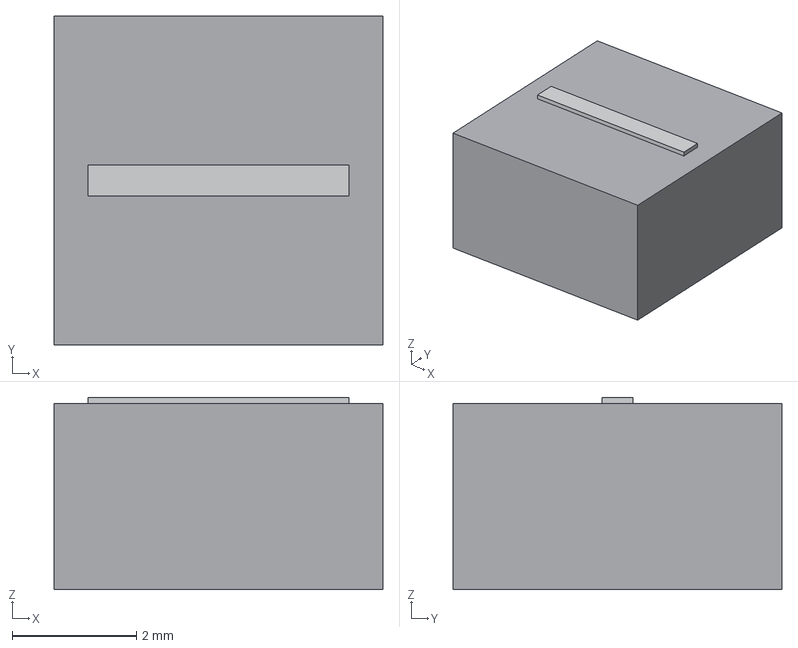
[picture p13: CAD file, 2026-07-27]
pcb/3d_models/stage3/coilcraft_xgl5050.step
5.30 x 5.30 x 3.10 mm

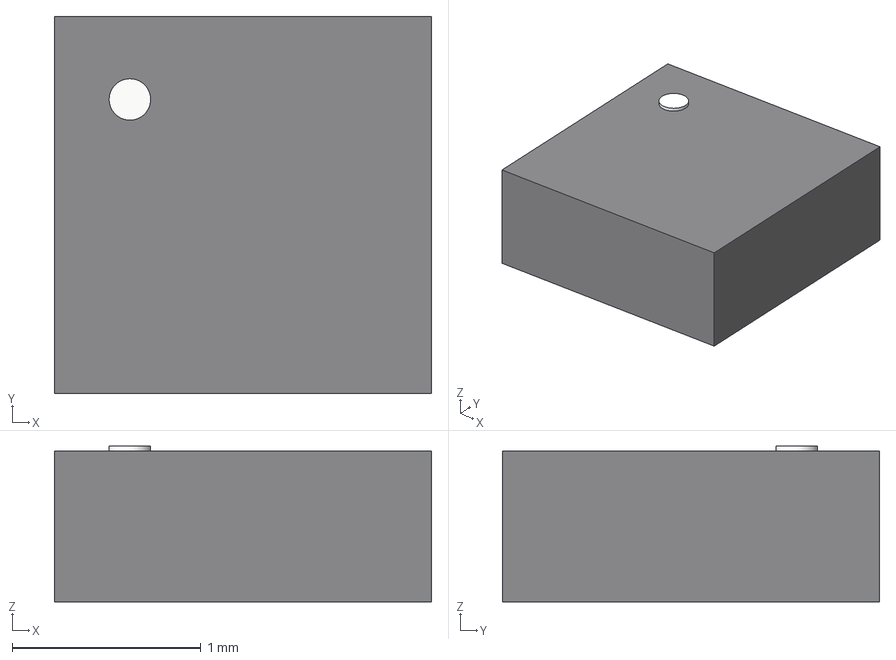
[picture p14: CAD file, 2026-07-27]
pcb/3d_models/stage3/adi_cp_8_10.step
2.00 x 2.00 x 0.825 mm

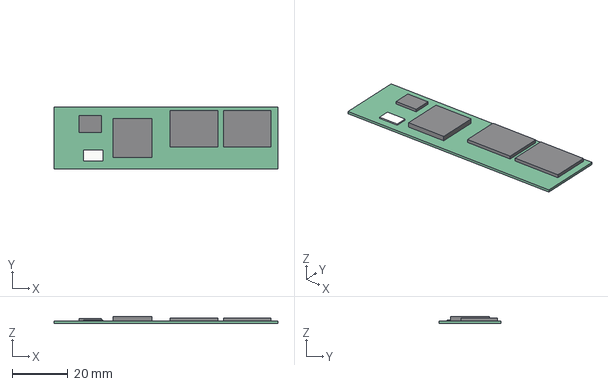
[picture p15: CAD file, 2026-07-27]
pcb/3d_models/stage3/wd_black_sn750_1tb_wds100t3x0c_engineering.step
80.0 x 22.0 x 2.38 mm

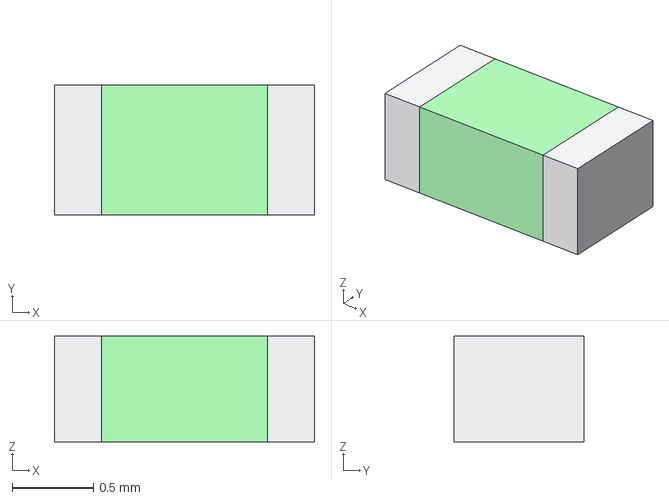
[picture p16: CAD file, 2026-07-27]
pcb/3d_models/stage3/led_0603_1608m.step
1.60 x 0.8 x 0.65 mm

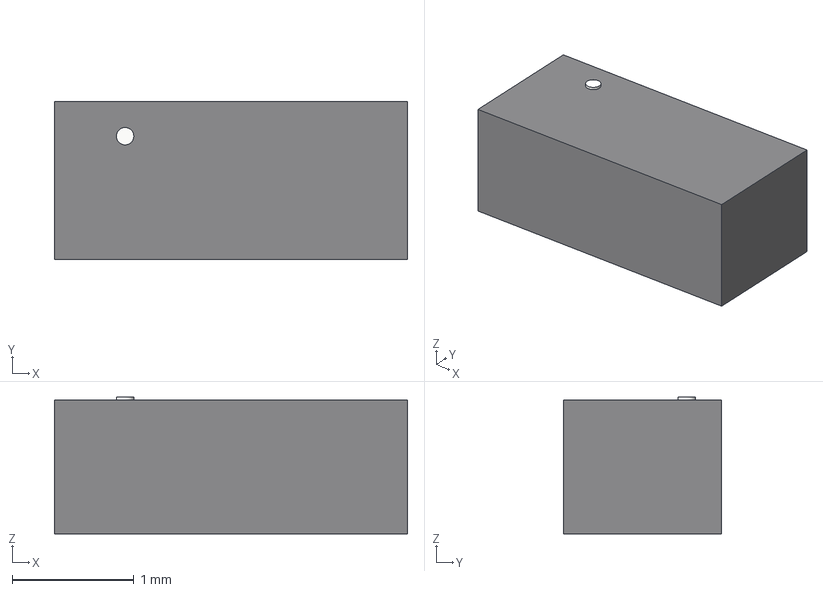
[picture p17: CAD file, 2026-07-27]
pcb/3d_models/stage3/sot23_standard.step
2.90 x 1.30 x 1.12 mm

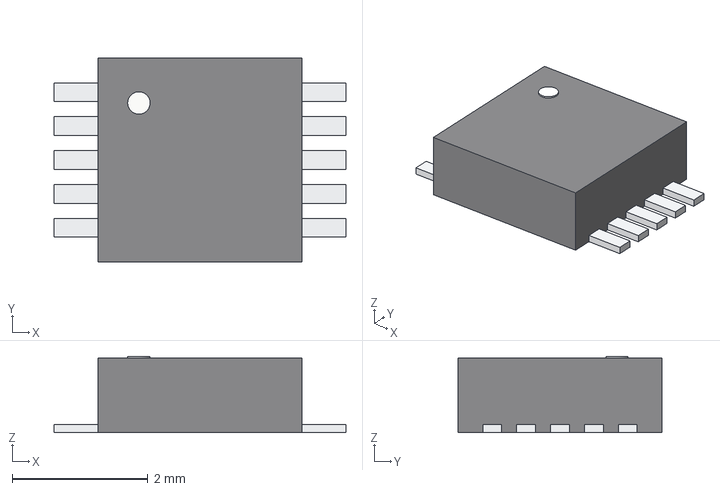
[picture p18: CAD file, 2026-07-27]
pcb/3d_models/stage3/ti_dgs10_vssop.step
4.30 x 3.00 x 1.12 mm

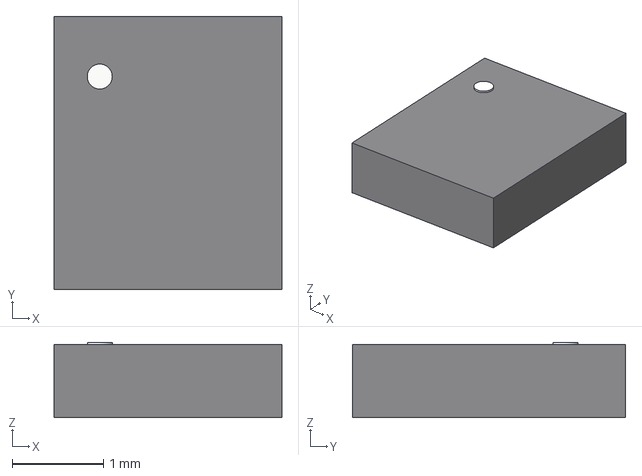
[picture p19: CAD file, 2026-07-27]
pcb/3d_models/stage3/ti_rpy14_2p5x3p0.step
2.50 x 3.00 x 0.825 mm

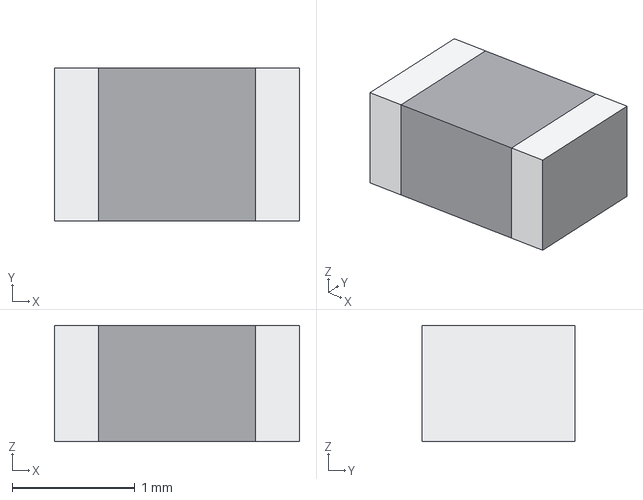
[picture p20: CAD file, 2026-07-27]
pcb/3d_models/stage3/murata_blm21_0805.step
2.00 x 1.25 x 0.95 mm

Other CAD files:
pcb/3d_models/stage3/ti_rpw10_2p0x2p0.step
pcb/3d_models/stage3/harwin_s1751_46r.step
pcb/3d_models/stage3/r_0603_1608m.step
pcb/3d_models/stage3/c_0603_1608m.step
pcb/3d_models/stage3/c_1210_3225m.step
pcb/3d_models/stage3/hdr_1x4_2p54_ra.step
pcb/3d_models/stage3/low_profile_pcie_bracket_engineering.step
pcb/3d_models/stage3/m2_2280_standoff_engineering.step

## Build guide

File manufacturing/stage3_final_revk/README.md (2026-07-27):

# RevK final interview digital package

Status：`Interview_Digital_Complete_Not_For_Fabrication`

Source board：

`pcb/allegro/stage3/pcie_gen3_x4_nvme_adapter_reva_stage3_route_revk_interview_digital_complete.brd`

SHA-256：`C772E9C3CD7A04A2CE3FBD1F5AE659E0935B786B235B17354DB83371BB4FF3EA`

Included：14 Gerber review files、2 NC Drill files、IPC-2581-C、BOM、preliminary P&P、native placement、CAM previews與mm/AP242 assembly STEP。

Known limitations：

- `Fabrication_Ready=false`；JLCPCB stack-up與impedance geometry未凍結。
- IPC-356輸出仍為空，已移到`diagnostics/ipc356_failed/`並排除。
- ODB++為`Not_Supported_By_Installed_Tool`。
- Gerber 0-width outline/text warnings保留於`photoplot.log`與`artwork_console.log`。
- STEP中的部分mechanical models仍為preliminary envelopes；不能作final collision Pass。
- 不得直接將此目錄上傳板廠下單。

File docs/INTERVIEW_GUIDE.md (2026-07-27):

# Interview guide — PCIe Gen3 x4 to M.2 NVMe adapter

語言 / Language：[`繁體中文版`](INTERVIEW_GUIDE_ZH.md)｜English canonical version is this file

Use the short version first, then open the linked evidence only when the interviewer asks for depth. The safe framing is: **digital interview closure, not fabrication release or PCIe compliance**.

## Walkthrough scripts

### 30 seconds

> I designed a six-layer, low-profile PCIe Gen3 x4 add-in card that physically connects a host PCIe slot to an M.2 M-Key 2280 NVMe SSD. It is a passive interposer—not a protocol converter. My engineering focus was the complete traceable workflow: Capture interface definition, protected 12 V to 3.3 V power, PSpice boundary testing, Allegro placement/constraints, native 3DX/STEP, CAM outputs and Python negative tests. The current RevK result is `Interview_Digital_Complete_Not_For_Fabrication`; I can show exactly what is closed and what still needs a controlled spec or hardware measurement.

### 2 minutes

1. Show the [portfolio hero](../portfolio/index.html) and state the function boundary.
2. Show the [system block diagram](system_block_diagram.md) and explain J1 → J2 signal continuity plus the eFuse/buck/shunt power path.
3. Show the [stage3 gate](../evidence/stage3/stage3_delivery_gate.md): DRC/connectivity/shape closure is real, but impedance geometry and exact models are not frozen.
4. Show one [3DX view](../evidence/stage3/3dx_native_revk/revk_top_isometric_detailed_with_ui.png) and the [STEP status](../evidence/stage3/3d_status.md).

### 5 minutes

Add the Architecture B trade-off, Capture connection matrix, PSpice profile table, nine-pair constraint record, and manufacturing status. Explicitly mention the 3.109 V recovery failure and the eFuse validation gap.

### 10 minutes

Use the questions below as a guided design review. Finish with the [Rev L plan](../PROJECT_REPORT.md#12-rev-l--next-revision-plan), not with an unsupported “ready to ship” statement.

## Questions and concise answers

### 1. What problem does the board solve?

It provides a physical PCIe Gen3 x4 host-to-M.2 M-Key 2280 NVMe connection with local power protection/conversion and optional telemetry. It does not translate PCIe protocol. See [`docs/interface_definition.md`](interface_definition.md).

### 2. Why is there no PCIe switch or retimer?

The requested use case is a passive adapter. Adding a switch/retimer would change the architecture, power, firmware, SI and compliance scope. The current host and SSD remain the protocol endpoints.

### 3. Why did you choose 12 V input plus a buck instead of slot 3.3 V?

I compared both in [`docs/architecture_tradeoff.md`](architecture_tradeoff.md). Architecture B exposes protection, conversion, current sensing and layout decisions that are valuable in an LDE interview, while the worksheet also records its complexity and risks.

### 4. What is the normal load target?

3.3 V / 5 A is the engineering normal target. 7 A / 100 µs is a transient study pulse, not a blanket SSD power rating. The calculations are in [`docs/power_budget.md`](power_budget.md).

### 5. Why is a 6 A regulator used if the pulse is 7 A?

The 7 A event is time-limited and relies on output capacitance/control response; it is not a 7 A continuous claim. The model still reaches an 8.656 A peak inductor-current observation and recovery fails, so this is not closed. See [`pspice/stage2/profile_results.csv`](../pspice/stage2/profile_results.csv).

### 6. What failed in PSpice?

The completed official-model combined profile reached 3.109 V in recovery against a 3.135 V lower screen, while PGOOD stayed high. That result is retained as `Fail_Recovery_Undershoot_5pct`; it is not hidden or rewritten as pass.

### 7. Why did the capacitor sweep not close the issue?

The 27 COUT/ESR/CFF cases were terminated by runtime limits, and the 132 µF candidate only reached about 0.255 ms of a requested 1.4 ms run. The hashes and disposition remain in [`pspice/stage3/run_record.md`](../pspice/stage3/run_record.md).

### 8. What does the eFuse contribute?

It is intended to control current, soft-start and fault behavior between slot 12 V and the buck. The isolated encrypted-model run did not reach valid output startup, so inrush/current-limit/latch-off behavior is still a validation task, not a claim.

### 9. Why use a 5 mΩ Kelvin shunt?

It gives a low-loss differential sense element for INA238 while keeping force and sense paths separate. At 5 A the nominal drop is about 25 mV; exact loss, layout parasitics and calibration require bench correlation.

### 10. What is INA238/TMP1075 used for?

INA238 monitors the SSD branch current/voltage across the shunt; TMP1075 monitors local board temperature. J3 is a target-only I²C/debug header and must not back-feed the board. See the [interface definition](interface_definition.md).

### 11. How did you handle PCIe AC coupling and conditioning?

I did not add lane AC capacitors, termination, CMC or ESD before transmitter ownership and the governing CEM/M.2 pin specification were confirmed. This avoids silently changing a high-speed topology, but the final decision remains a controlled-source gate.

### 12. What does DRC=0 prove?

It proves the current native database passed the reported design-rule/connectivity checks. It does not prove SI/PI, impedance, thermal, mechanical fit, PCIe compliance or manufacturing yield. The counters are in [`evidence/stage3/stage3_delivery_gate.md`](../evidence/stage3/stage3_delivery_gate.md).

### 13. How many differential pairs are defined?

Nine native pair objects: eight PCIe data pairs (TX/RX for lanes 0–3) plus one REFCLK pair. Width/gap/via and skew are intentionally pending the fabricator stack-up. See [`pcb/differential_pairs.csv`](../pcb/differential_pairs.csv).

### 14. Why are physical J1/J2 pins still pending?

The controlled CEM/M.2 source documents were not available for legal verification. The repository records a B12/CLKREQ# and M.2 pin-32 conflict instead of guessing. See [`docs/pcie_m2_pin_mapping.md`](pcie_m2_pin_mapping.md).

### 15. Why is the stack-up not frozen?

Controlled impedance depends on the actual JLCPCB dielectric/copper stack-up and calculator output. Until that evidence is attached, a made-up line width/gap would be less credible than an explicit blocker. See [`evidence/stage3/constraint_manager_status.md`](../evidence/stage3/constraint_manager_status.md).

### 16. What did the 3DX/STEP work demonstrate?

It demonstrated a native-board-to-3DX-to-AP242/mm STEP handoff and isolated re-import with a hash-bound record. It did not demonstrate exact chassis fit because several mating models/transforms are preliminary or missing.

### 17. Why do some collision cases say blocked?

Collision Pass requires an exact model, confirmed transform and sourced clearance rule. A conservative envelope can support `Preliminary_Clear`, but a polished image cannot turn a missing controlled model into an engineering Pass. See [`evidence/stage3/3d_status.md`](../evidence/stage3/3d_status.md).

### 18. What manufacturing files are present?

Gerber artwork, NC Drill, IPC-2581-C, BOM, preliminary P&P, assembly drawing evidence and STEP are present. IPC-356 was empty and excluded; ODB++ is unsupported by the installed tool. The package is not direct-fab upload material. See [`manufacturing/stage3_final_revk/README.md`](../manufacturing/stage3_final_revk/README.md).

### 19. What did you automate?

I used standard-library Python to validate CSV schemas, BOM fields, duplicate pins, net naming and Stage 2/3 evidence contracts. Negative fixtures intentionally fail for missing columns/MPN, duplicate pins, invalid nets, stale hashes and false routing claims. See [`scripts/`](../scripts/) and [`PROJECT_REPORT.md`](../PROJECT_REPORT.md#10-automation-and-negative-tests--自動化).

### 20. How do you keep a failed result from being lost?

Every important run records input/output paths, status, limits and hashes. The PSpice recovery failure and runtime-limited sweep are linked from the report and claim matrix rather than overwritten by a later presentation image.

### 21. What would you do before ordering boards?

Freeze CEM/M.2 physical pins, import the current fabricator stack-up, close pair geometry and power recovery, validate eFuse behavior, replace preliminary mechanical models, then rerun DRC/CAM/DFM and review the board-house quote.

### 22. What would you do on the bench?

Use a current-limited supply and no SSD first; verify rails, inrush and PGOOD; then insert the reference SSD, check enumeration/link width/speed/NVMe identify, and finally perform short stress and thermal checks. None of those results are currently claimed.

### 23. Why is this an LDE-relevant project?

It shows the complete loop an LDE must manage: interface ownership, power trade-offs, library/footprint discipline, high-speed constraints, MCAD handoff, manufacturing outputs, automation, failure analysis and honest release gates—not only schematic capture.

### 24. What is the single biggest risk?

The highest-impact cluster is missing controlled source data: connector pin freeze and fabricator stack-up. Without them, a visually convincing board could still encode the wrong physical mapping or impedance geometry.

### 25. What is the next revision called and what changes?

Rev L is a controlled ECO: source-controlled pin freeze, stack-up-derived constraints, power recovery closure, eFuse validation, exact mechanical remapping, then CAM/DFM and physical bring-up. It is not a cosmetic rerender of RevK.

## Evidence quick links

- [Project report](../PROJECT_REPORT.md)
- [Claim/evidence matrix](CLAIM_EVIDENCE_MATRIX.md)
- [Documentation audit](DOCUMENTATION_AUDIT.md)
- [Stage 3 gate](../evidence/stage3/stage3_delivery_gate.md)
- [Final release status](../evidence/stage3/final_release_status.md)

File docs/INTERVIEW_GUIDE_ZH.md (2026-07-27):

# 面試指南（繁體中文）

English version：[`INTERVIEW_GUIDE.md`](INTERVIEW_GUIDE.md)

## 30 秒說法

我設計一張六層 PCIe Gen3 x4 add-in card，將 host PCIe slot 實體連到 M.2 M-Key 2280 NVMe SSD。它是 passive interposer，不是 protocol converter。專題涵蓋 Capture 介面、12 V 保護與 buck power、PSpice、Allegro placement/constraints、3DX/STEP、CAM 與 Python negative tests。現況是 `Interview_Digital_Complete_Not_For_Fabrication`，我能清楚說明哪些已關閉、哪些仍需要受控規格或硬體量測。

## 2 分鐘說法

1. 先展示 [雙語作品集](../portfolio/index.html)，說明 host、board、SSD 的功能邊界。
2. 開啟 [system block diagram](system_block_diagram.md)，解釋 J1→J2 訊號直通與 eFuse/buck/shunt 電源鏈。
3. 開啟 [stage3 gate](../evidence/stage3/stage3_delivery_gate.md)，說明 DRC/connectivity/shape closure 與尚未 freeze 的 impedance/pin gates。
4. 展示 [native 3DX view](../evidence/stage3/3dx_native_revk/revk_top_isometric_detailed_with_ui.png) 與 [STEP status](../evidence/stage3/3d_status.md)。

## 5～10 分鐘說法

加入 Architecture B trade-off、Capture connection matrix、PSpice profile table、nine differential pairs、CAM status，主動說明 3.109 V recovery failure、eFuse validation gap、CEM/M.2 source gate 與 JLCPCB stack-up blocker。最後以 [Rev L plan](../PROJECT_REPORT.md#12-rev-l--next-revision-plan) 結尾。

## 技術問答

### 1. 這張板實際解決什麼問題？

它提供 host PCIe Gen3 x4 到 M.2 M-Key 2280 NVMe 的 physical connection、local power protection/conversion 與 optional telemetry。它不轉換 PCIe protocol。參考 [`docs/interface_definition.md`](interface_definition.md)。

### 2. 為什麼沒有 PCIe switch 或 retimer？

因為需求是 passive adapter。加入 switch/retimer 會改變 power、firmware、SI 與 compliance scope。

### 3. 為什麼選 12 V + buck？

我在 [`docs/architecture_tradeoff.md`](architecture_tradeoff.md) 比較 slot 3.3 V 與 local conversion；Architecture B 能展示 protection、conversion、sensing 與 hot-loop review。

### 4. 正常負載是多少？

3.3 V / 5 A 是 engineering normal target；7 A / 100 µs 是 transient study，不是通用 SSD rating。

### 5. 為什麼 6 A buck 要分析 7 A？

7 A 只是一個短暫電容／控制迴路事件，不是 7 A continuous claim；但模型觀察到 8.656 A peak inductor current，且 recovery 失敗，所以尚未關閉。

### 6. PSpice 失敗在哪裡？

官方 buck model 的 recovery minimum 是 3.109 V，低於 3.135 V lower screen；PGOOD 仍保持 high。結果保留為 `Fail_Recovery_Undershoot_5pct`。

### 7. 為什麼 capacitor sweep 沒有結案？

27 個 COUT/ESR/CFF cases 因 runtime limit 中止；132 µF candidate 只跑到約 0.255 ms，不能推導 pass。

### 8. eFuse 做什麼？

控制 slot 12 V 到 buck 的 current limit、soft-start 與 fault response；isolated model run 沒有有效 output startup，因此 inrush/latch-off 尚未驗證。

### 9. 為什麼使用 5 mΩ Kelvin shunt？

它能在低壓降下提供 INA238 differential sense；5 A 時 nominal drop 約 25 mV，但 calibration 與 layout parasitic 需 bench correlation。

### 10. INA238/TMP1075 的用途？

INA238 量測 SSD branch current/voltage，TMP1075 量測板上溫度；J3 是 target-only I²C header，不能外部回灌供電。

### 11. 為什麼沒有 AC coupling 或 CMC？

在 transmitter ownership 與 governing CEM/M.2 source 確認前，不改變高速 topology，避免自行加入沒有來源的元件。

### 12. DRC=0 證明什麼？

它證明目前 native database 通過報告中的 design-rule/connectivity checks；不證明 SI/PI、impedance、thermal、fit、compliance 或 yield。

### 13. 有幾組 differential pairs？

九組：八組 PCIe data pairs 加一組 REFCLK pair。Width/gap/via/skew 仍等 fabricator stack-up。

### 14. 為什麼 J1/J2 physical pins 還 pending？

受控 CEM/M.2 source 尚未納入 public package；B12/CLKREQ# 與 M.2 pin 32 的版本差異已記錄，沒有猜 pin number。

### 15. 為什麼 stack-up 未 freeze？

Controlled impedance 必須使用當期 JLCPCB dielectric/copper stack-up 與 calculator；填造一組 width/gap 會是假精確。

### 16. 3DX/STEP 證明什麼？

證明 native board → 3DX → AP242/mm STEP → isolated re-import 的 handoff loop；不證明 exact chassis fit。

### 17. 為什麼碰撞案例有 blocked？

Collision Pass 需要 exact model、confirmed transform 與 sourced clearance rule；保守 envelope 只能是 preliminary。

### 18. 有哪些製造檔？

Gerber、NC Drill、IPC-2581-C、BOM、preliminary P&P、assembly evidence 與 STEP；IPC-356 空檔排除，ODB++ 不支援，因此不是 direct-fab release。

### 19. 自動化做了什麼？

Python 檢查 CSV schema、BOM、duplicate pins、net naming、evidence contract 與 negative fixtures；不取代 Cadence native review。

### 20. 如何避免 failure 被覆蓋？

每個重要 run 保存 input/output、status、limitation 與 hash；3.109 V failure 與 runtime-limited sweep 都保留在 report/matrix。

### 21. 下板前要做什麼？

Freeze CEM/M.2 pins、導入 JLCPCB stack-up、關閉 power recovery/eFuse、補 exact models，再做 DFM、CAM 與 board-house review。

### 22. Bench bring-up 順序？

限流上電且不插 SSD → 檢查 rails/inrush/PGOOD → 插入 reference SSD → enumeration/link width/speed/NVMe identify → stress/thermal。這些結果目前未宣稱。

### 23. 為什麼與 LDE 工作相關？

因為它展示從 interface ownership、power、library、constraints、MCAD、CAM、automation 到 failure disclosure 的完整 loop。

### 24. 最大風險是什麼？

Missing controlled source data，尤其是 connector physical pin freeze 與 fabricator stack-up；它們可能讓漂亮的 board encode 錯誤 mapping 或 impedance。

### 25. Rev L 要改什麼？

Rev L 是 controlled ECO：pin freeze、stack-up-derived constraints、power recovery/eFuse closure、exact mechanical remapping、DFM/fabrication 與 bring-up，不是單純重新 render。

## 快速證據連結

- [中文技術報告](../PROJECT_REPORT_ZH.md)
- [English technical report](../PROJECT_REPORT_EN.md)
- [中文 claim matrix](CLAIM_EVIDENCE_MATRIX_ZH.md)
- [English claim matrix](CLAIM_EVIDENCE_MATRIX.md)

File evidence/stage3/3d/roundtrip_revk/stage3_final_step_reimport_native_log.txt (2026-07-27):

REVK INTERVIEW DIGITAL COMPLETE
PRELIMINARY MECHANICAL PLACEMENT - NOT FAB READY
Result: NATIVE_DRA_STEP_ASSIGNMENT_OK
Source_STEP: C:/project/orcad_project/nvidia-lde-orcad-portfolio/manufacturing/stage3_final_revk/pcie_gen3_x4_nvme_adapter_reva_revk_final_preliminary.step
Output_DRA: pcie_gen3_x4_nvme_adapter_reva_revk_final_step_reimport
Wrapper_Units: millimeters
Wrapper_Place_Bound_mm: 120.000 x 64.000
Mapping_Readback: (nil objType "step" rotation_z 0.0 rotation_y 0.0 rotation_x 0.0 offset_z 0.0 offset_y 0.0 offset_x 0.0 color 0 type primary step_name "pcie_gen3_x4_nvme_adapter_reva_revk_final_preliminary.step")

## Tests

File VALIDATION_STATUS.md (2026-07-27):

# Public package validation status

Validation run on 2026-07-27 for the curated RevK interview package.

| Check | Result | Notes |
|---|---|---|
| `python scripts/validate_csv.py --root .` | PASS | 33 CSV files checked; 0 format issues. |
| `python scripts/check_bom_fields.py manufacturing/bom.csv` | PASS | Required manufacturer/MPN/package/quantity/reference/lifecycle fields present. |
| `python scripts/check_net_names.py schematic/connection_matrix.csv` | PASS | Naming and lane/sideband checks passed. |
| `python scripts/check_duplicate_pins.py ...` | PASS with review warnings | 0 errors; 31 shared-net duplicate-appearance warnings require engineering review. |
| `python -m unittest discover -s scripts -p 'test_*.py' -v` | PARTIAL | 42 tests passed; 3 Stage 2 repository-specific tests are not green because the public package intentionally excludes raw CSDF and historical Stage 2 evidence. |
| `python scripts/check_stage3_delivery.py --root .` | NOT USED AS A GATE | The legacy checker is hard-coded for the older RevI directory names. This public package is the RevK interview release; the native reports and current evidence are kept under the RevK paths. |

## Interpretation

This repository is an interview portfolio release, not a fabrication release. The published evidence preserves the actual limitations: the PSpice recovery case is disclosed, controlled fabricator stack-up confirmation is pending, some mechanical models are preliminary, and ODB++ is not supported by the installed toolchain. No PCIe compliance or universal SSD-support claim is made.

The Stage 2 test failures are not hidden as a green result. They reflect the deliberately curated public package boundary; the full private working directory remains the source of the excluded raw simulation and historical evidence files.

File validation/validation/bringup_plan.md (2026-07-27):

# Bring-up Plan

> 狀態：`Planned / Not_Yet_Measured`。任何實際值必須連同儀器、探棒、SSD、host、日期與原始證據記錄。

## 安全條件

- 不在主機通電時插拔 PCIe card 或 M.2 SSD。
- 第一次上電不得直接由未知主機板供電；先使用經 review 的 current-limited bench injection 方法。
- Bench supply 注入點不得反向回灌 PCIe edge；若無法證明隔離，停止測試。
- 示波器接地不可造成 12V、3.3V 或 host chassis 短路。
- 所有 pass/fail limit 必須在測試前由 requirements、datasheet 或 PSpice 結果凍結。

## Phase 0 — 文件與目視

1. 核對 board revision、BOM、assembly drawing、ECO。
2. 目視 QFN、M.2 connector、shunt、電感、極性與 gold finger。
3. 量測未裝 SSD 時 `P12V_SLOT`、`P12V_PROTECTED`、`P3V3_NVME` 對 GND 阻抗；記錄時間相關變化與雙向讀值。
4. 確認沒有明顯短路、錯件或 mechanical interference。

## Phase 1 — 無 SSD 受控上電

5. 設定 bench supply 電壓與 current limit；兩者必須來自已核准測試卡，不能現場猜測。
6. 上電並觀察 supply current、`P12V_PROTECTED`、`P3V3_NVME`、`PGOOD_EFUSE`、`PGOOD_3V3`。
7. 確認 3.3V startup、steady-state、no-load current 與 ripple。
8. 測試 shutdown、re-start 與 protection latch reset；任何異常立即斷電。
9. 以外部 I²C master 讀 INA238／TMP1075；確認 Header 不會 back-power。

## Phase 2 — 安裝 SSD

10. 斷電、放電後安裝已核准且資料可清除的 NVMe SSD。
11. 重複 power-to-ground sanity check。
12. 捕捉 SSD 啟動電流、3.3V droop、PGOOD、eFuse/buck response。
13. 確認沒有 nuisance trip、hiccup、過熱或異常聲音。

## Phase 3 — 主機功能

14. 主機完全關機後安裝 card，確認 bracket 與 slot seating。
15. 開機後依 `pcie_enumeration_test.md` 保存 kernel-log before／after，再收集
    `lspci`、`lspci -vv`、`nvme list`、`nvme id-ctrl`；不得清除 host kernel log。
16. 記錄 negotiated speed、width、BDF、AER／link reset 訊息。
17. 先做非破壞讀取，再對專用 test namespace 做短時間 verified read/write。

## Phase 4 — 壓力、熱與相容性

18. 依 `storage_stress_test.md` 與 `test_profiles.csv` 執行 staged workload；先
    `--parse-only`，read case保留 `--readonly`，同步記錄電壓、電流、溫度、SMART 與 kernel log。
19. 依 `BOOT-COLD-10`／`BOOT-WARM-10` 各執行十次，兩種 evidence分開保存。
20. 使用第二顆已核准 SSD 重複 power、enumeration、speed、width 與短測。
21. 每項失敗建立 debug log；只有在證據支持時才提出 ECO。

## Stop Conditions

- 可見煙霧、異味、異常聲音、快速升溫。
- Bench supply 進入未預期 current limit。
- 3.3V 超出已核准 operating window。
- PGOOD、buck switching 或 input protection 出現未解釋 oscillation。
- 主機反覆 reset、PCIe fatal AER、SSD 消失或資料錯誤。

## 完成定義

- 測試矩陣每一列有 Pass、Fail、Blocked 或 Not_Run 結果及證據。
- 實測與 Simulated／Estimated 值分欄比較。
- 所有 failure 有 reproducibility、diagnostic evidence、disposition 與 regression plan。

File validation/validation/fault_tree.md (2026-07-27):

# Fault Tree

> Probability 與 Severity 是 Rev A 工程排序，不是 field-return 統計。根因只有在診斷證據支持後才能確認。

| Symptom | Possible Cause | Probability | Severity | Diagnostic Test | Required Instrument | Expected Observation | Corrective Action | ECO Impact |
|---|---|---|---|---|---|---|---|---|
| 完全無法辨識 SSD | 無 3.3V、PERST#／REFCLK／lane pin map 錯、SSD/host 問題 | Medium assumption | Critical | 依序查 power→sideband→clock→lane continuity→換 SSD/slot | DMM、scope、lspci、TDR/continuity | 將 failure 隔離到電源、介面或外部平台 | 修正 power或 pin map；外部問題則更新 AVL | 可能重佈關鍵網路，High |
| SSD 偶爾消失 | droop、thermal、connector、AER、marginal SI | Medium assumption | High | 同步 log power、temperature、AER、mechanical perturbation | Scope、logger、thermal sensor | 消失時間與至少一項事件相關 | 依證據調電容、散熱、connector或 routing | Medium～High |
| Link Width 只有 x1 | lane 1～3 open/short、pin map、host bifurcation、SSD能力 | Medium assumption | High | 比對 LnkCap/LnkSta、continuity、lane swap、第二 host | lspci、DMM、TDR | 找到缺失 lane 或 platform限制 | 修正 lane connectivity或文件化 host限制 | High if PCB |
| Link Speed 只能 Gen1/Gen2 | host/SSD setting、loss/return path、clock、via discontinuity | Medium assumption | Medium | 強制/自動 link比較、AER、第二 host/SSD、layout review | lspci、scope、SI review | 降速可由平台或通道相關條件重現 | 修正 constraint／routing或支援清單 | Medium～High |
| 開機後卡住 | short、slot power trip、BIOS compatibility、PRSNT錯 | Low assumption | Critical | 無卡/無SSD/有卡分段啟動並監視12V | Bench supply、DMM、POST log | 卡住只在特定配置出現 | 修正 power/PRSNT；更新相容性 | High |
| 3.3V 無輸出 | eFuse disabled/latched、Buck EN/UVLO、assembly fault | Medium assumption | Critical | 量 VIN/EN/PG/SW/VOUT 並查 latch reset | DMM、scope | 第一個失效節點被定位 | 修正設定、焊接或 power chain | Medium |
| 3.3V 啟動後掉壓 | current limit、soft-start、inductor saturation、SSD peak | High assumption | Critical | 捕捉 startup current、SW、PG、eFuse status | Current probe、scope | 掉壓與限流/峰值同步 | 調整經驗證的 limit、L/C或限制 SSD | Medium～High |
| Ripple 過高 | layout loop、電容 derating、control mode、probe artifact | Medium assumption | High | 短 ground 重測、不同帶寬、檢查 SW/L/C | Scope、LCR meter | 區分真實 ripple 與 probing artifact | 修正 layout/component或量測程序 | Medium |
| Buck 過熱 | 損耗、SW頻率、copper/thermal via不足、過載 | Medium assumption | High | 量 input/output power與case/board溫度 | DMM、current probe、thermocouple | 溫升與負載／損耗相關 | 改頻率、copper、散熱或器件 | Medium～High |
| SSD 壓測降速 | SSD thermal、SLC cache、power cap、link error | High assumption | Medium | 同步 SMART、temperature、power、AER、workload phase | smartctl、fio、thermal logger | throttle原因與 log對應 | 改散熱；若板級則修正 power/SI | Low～Medium |
| I²C Telemetry 無法讀取 | 地址、pull-up、供電、header、bus stuck | Medium assumption | Low | 查 VCC、SCL/SDA idle、scan approved address | DMM、logic analyzer | 無 ACK或線被拉低 | 修正 strap/pull-up/接線 | Low |
| 電流讀值不準 | shunt tolerance、Kelvin錯、calibration、offset | Medium assumption | Medium | 以 reference load/DMM多點比對 | DMM、electronic load | error隨 offset/gain/temperature呈特徵 | 校正或修正 shunt routing/value | Low～Medium |
| 部分 PCIe Lane 開路 | connector solder、via/pad、fab defect、symbol錯 | Low assumption | High | Bare-board net test、X-ray、TDR、cross-probe | DMM、X-ray、TDR | 明確 open位置 | 返修僅作診斷；PCB ECO修正 | High |
| 不同主機板相容性不同 | BIOS、slot routing/power、ASPM、mechanical seating | Medium assumption | Medium | 固定 SSD/card，比較 host config與log | 多主機、lspci、scope | failure聚集於特定 host條件 | 更新 AVL/BIOS設定或改善 margin | Medium |

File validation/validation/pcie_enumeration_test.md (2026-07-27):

# PCIe Enumeration Test

> 目標：驗證功能性 enumeration 與 negotiated link，不宣稱 PCI-SIG compliance。

## Linux

```bash
TEST_START="$(date --iso-8601=seconds)"
journalctl -k -b 0 -o short-iso > <evidence-dir>/kernel-before.txt
lspci -nn
lspci -vv -s <BDF>
sudo nvme list
sudo nvme id-ctrl /dev/nvmeX
journalctl -k -b 0 --since "$TEST_START" -o short-iso > <evidence-dir>/kernel-after.txt
```

`<BDF>`、`/dev/nvmeX` 與 `<evidence-dir>` 必須由 reviewer 逐項確認。流程禁止使用
`dmesg --clear` 或其他清除 host kernel log 的操作。若 host 沒有 persistent
systemd journal，改在測試前後分別保存 `dmesg --time-format iso` 全量 snapshot，
不得清空 ring buffer。

保存：

- Host motherboard、BIOS version、slot、OS/kernel。
- SSD manufacturer、model、firmware、capacity。
- BDF、Vendor／Device ID。
- `LnkCap` 與 `LnkSta` speed／width。
- ASPM 狀態、AER counter、retrain／reset 訊息。

## Windows

- Device Manager：Hardware IDs、driver、event status。
- HWiNFO：PCIe link speed／width。
- CrystalDiskInfo：model、firmware、SMART。
- Event Viewer：WHEA／storage／PCIe warning。

## 判定

- Enumeration：端點出現且在觀察期間沒有重複消失／重現。
- Link width：只有 host slot 與 SSD 都支援 x4 時才以 x4 為 pass 條件。
- Link speed：只有 host、SSD、BIOS 皆允許 Gen3 時才以 Gen3 為 pass 條件。
- x1、x2、Gen1、Gen2 或 link down 均進入 fault tree；不得直接判定為 SI 根因。

## Evidence

- 原始 command output／screenshots。
- Cold boot 與 warm boot 分開命名。
- 任何 BIOS setting 變更寫入 debug log。
- 使用 [test profiles](test_profiles.csv) 的 case ID、trial count 與 evidence prefix。

## 工具來源

- [journalctl manual](https://www.man7.org/linux/man-pages/man1/journalctl.1.html)：
  `-k` 篩選 kernel message、`--since`／`--until` 限定時間範圍。
- [dmesg manual](https://man7.org/linux/man-pages/man1/dmesg.1.html)：
  `--time-format` 可保留有時間標記的 snapshot；本計畫不使用 clear action。

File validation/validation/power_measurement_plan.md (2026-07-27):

# Power Measurement Plan

## 量測節點

| Node | 目的 | 儀器 | Probe 方法 | 狀態 |
|---|---|---|---|---|
| P12V_SLOT | 插槽輸入與 inrush | Differential probe／DMM | Edge 後第一個 test point | Planned |
| P12V_PROTECTED | eFuse 壓降與 fault response | Differential probe | eFuse OUT Kelvin point | Planned |
| P3V3_PRE_SENSE | Buck regulation | Low-noise probe | Buck output capacitor端 | Planned |
| P3V3_NVME | SSD 實際供電 | Low-noise probe | Shunt load-side capacitor端 | Planned |
| VSHUNT_P/N | SSD current | INA238＋differential probe | Kelvin sense pads | Planned |
| PGOOD_EFUSE | Protection timing | Logic probe | 10× high-impedance | Planned |
| PGOOD_3V3 | Buck timing | Logic probe | 10× high-impedance | Planned |
| SW_3V3 | Switch-node行為 | Rated probe | 極短 ground spring；僅由合格操作者量測 | Planned |

## Measurement Discipline

- 每次 capture 記錄 scope、probe、bandwidth、sample rate、time base、coupling、ground method。
- Ripple 同時保留 full-bandwidth 與明確 bandwidth-limited capture，不混用。
- Current probe 在測試前 degauss／zero；INA238 讀值以 shunt tolerance 與 reference DMM 交叉驗證。
- 溫升測試前記錄 ambient、airflow、SSD heatsink、case orientation。
- 不把 bench wire injection 的結果直接等同 PCIe slot 實際供電。

## Planned Conditions

- No-load、10% load、100% design load。
- Startup、shutdown、line ramp、load step、load release。
- 5A normal target。
- 7A／100µs engineering pulse，用於瞬態承受驗證，不等同 SSD 實測波形。
- Protection short／overcurrent 只在 current-limited fixture 與已核准程序中進行。

## Pass／Fail

具體電壓、ripple、droop、inrush、timing 與 temperature limit 必須在以下資料完成後寫入：

1. PCIe CEM slot power review。
2. Target SSD official power data。
3. TPS543620／TPS259472L 計算與 PSpice。
4. JLCPCB copper／thermal stack-up。

在此之前所有數值欄均為 `Pending_Human_Verification`，不得用示意值判定 Pass。

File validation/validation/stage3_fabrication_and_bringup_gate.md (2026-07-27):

# Stage 3 fabrication 與 bring-up gate

- Interview status：`Interview_Digital_Complete`
- Fabrication_Ready: `false`
- PCIe compliance：`Not_Claimed`
- Bench qualification：`Not_Yet_Measured`
- ODB++：`Not_Supported_By_Installed_Tool`
- IPC-356：`Failed_Empty_Output_Excluded`

## 已完成的 OrCAD 數位 closure

- [x] RevK native board 可 save、close、reopen，且 SHA-256 已綁定 manifest。
- [x] Native DRC 0，無 hidden/waived DRC 宣稱。
- [x] Unconnected 0、active rats 0、PCIe unconnected nets 0。
- [x] L2/L5 GND與 L4 power shapes 已建立；shape islands 0、unassigned shapes 0。
- [x] 9 組 PCIe/REFCLK native differential pairs，每組兩個 members。
- [x] Gerber、NC Drill、IPC-2581、BOM、P&P、assembly artwork、CAM previews與STEP已由同一 RevK board hash產生。
- [x] Assembly STEP 已隔離重新指派至 native DRA並讀回 mapping。
- [x] RevK native 3DX證據與八張黑背景portfolio圖已寫入hash-bound manifests。
- [x] PSpice 3.109 V recovery failure與27案 runtime limit已保存且明示。
- [x] IPC-356空檔已排除；ODB++安裝限制已明示。

## Fabrication release 尚未完成

- [ ] 取得並封存 JLCPCB 當期 1.6 mm 六層 controlled-impedance stack-up與quote。
- [ ] 以 PCIe CEM／M.2受控規格完成 critical pin、mechanical與impedance sign-off。
- [ ] 依板廠calculator凍結九組 pair的width/gap/via/anti-pad/reference-layer規則。
- [ ] 完成最終 Constraint Manager report、SI/return-path人工審查與全層CAM review。
- [ ] 凍結 eFuse current limit/inrush、有效輸出電容與 supported-SSD power envelope。
- [ ] 以exact SSD/standoff/bracket/cable/chassis/heatsink CAD重跑3D-01～3D-08。
- [ ] 根據上述ECO重新產生所有製造輸出並由第二人覆核。
- [ ] 使用者明確核准板廠、數量、價格與上傳archive hash。

## 實體 bring-up

1. 記錄板號、批次、目視與bare-board short檢查。
2. 無SSD，以current-limited bench supply驗證12 V、protected 12 V、3.3 V與PGOOD。
3. 驗證I²C telemetry與header不可回灌。
4. 電源Gate通過後才安裝核准的sacrificial SN750。
5. 記錄startup current、3.3 V droop、PGOOD與溫度。
6. Host關機後安裝卡，確認bracket與connector seating。
7. 記錄enumeration、BDF、negotiated speed/width、AER與NVMe Identify。
8. 依序執行read-only、短I/O、stress與thermal測試。
9. 所有異常寫入`debug_log_template.md`，變更使用`eco_template.md`。

實體量測前，所有bring-up結果只可標示`Planned`或`Not_Yet_Measured`。

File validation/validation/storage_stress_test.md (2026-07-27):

# Storage Stress Test

> 狀態：`Planned`。僅能使用可清除的測試 SSD／namespace；禁止對使用者資料執行破壞性 workload。

## 前置條件

- Power、enumeration、link speed／width、NVMe identify 與短時間讀寫已通過。
- 測試容量、時間、I/O pattern、queue depth、block size、驗證模式在執行前凍結。
- 同步 log：P3V3_NVME、INA238 current、TMP1075、SSD SMART、ambient、`dmesg`。

## Profile freeze

所有 case 的 runtime、block size、queue depth、verify、trial count、stop conditions 與
evidence prefix 定義於 [test_profiles.csv](test_profiles.csv)。這些數字是預先凍結的
`Engineering_Assumption` 測試設定，不是 NVMe／PCIe 規格要求，也不是已執行結果。

每次執行前必須產生 reviewer-approved `.fio` job file，且至少記錄：

- exact host、BDF、controller、namespace、SSD model／capacity／firmware；
- `lsblk`／mount 狀態、serial-to-device mapping、資料可清除批准；
- job file SHA-256、fio version、reviewer、日期與 evidence directory；
- power／thermal limits與 emergency stop operator。

## Staged Workload

1. Sequential read。
2. Sequential verified write to test namespace。
3. Random read。
4. Mixed read/write。
5. Sustained workload until預定時間或 stop condition。

先只解析 job file，不進行 I/O：

```bash
fio --parse-only <reviewed-read-job.fio>
```

read-only case 執行時額外保留 fio safety guard：

```bash
fio --readonly --output=<evidence-file.json> --output-format=json <reviewed-read-job.fio>
```

`--parse-only` 只驗證 option parsing，不證明 target 安全；`--readonly` 只允許
read-only profile。Repository **刻意不提供可直接複製執行的 write／trim command**。
`FIO-WRITE-VERIFY-SHORT` 與 `FIO-MIXED-STRESS` 只有在 exact disposable namespace、
unmounted state、backup／data-loss approval、job hash與 second-person review全部完成後，
才由 lab procedure 產生一次性執行命令。不得在 system disk、使用者資料或未核准
namespace 上移除 `--readonly`。

## Stop Conditions

- I/O verification error、namespace 消失、controller reset。
- PCIe AER／WHEA fatal error。
- P3V3_NVME 超出核准範圍或 protection 動作。
- 元件溫度接近核准 derated limit。
- SMART critical warning 或 host stability 受影響。

## Evidence／判定

- 不以 throughput 數字作為主要設計成功宣稱。
- Pass 需要零 verification error、零未解釋 reset、電源與溫度在核准範圍。
- 降速必須同時檢查 SSD thermal、power、host、workload cache 與 PCIe link，不能直接歸因 PCB。

## 工具來源

- [fio official documentation](https://fio.readthedocs.io/en/master/fio_doc.html)：
  `--parse-only` 不啟動 I/O；`--readonly` 阻止 write／trim workload。這兩項是額外
  safety guard，不能替代 exact-target 人工核准。

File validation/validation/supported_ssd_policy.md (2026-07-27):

# Rev A Supported SSD Policy

## Current support statement

**目前沒有任何 SSD 被列為 Rev A supported device。**

5 A steady-state 與 7 A／100 µs 只是本板的設計與驗證 stimulus，不是任一 SSD 的
官方 power envelope，也不是通用 M.2 支援宣告。在 Power、Pin、Mechanical 與
hardware validation Gate 全部關閉前，對外說法只能是：

> Designed for evaluation with a single M.2 2280 M-Key NVMe SSD; the qualified
> device list is pending specification, simulation, and bench validation.

## Qualification states

| State | 必要證據 | 對外可宣稱內容 |
|---|---|---|
| `Candidate` | Exact manufacturer、model、capacity、firmware與官方 datasheet／power資料已保存 | 只可說列入評估 |
| `Power_Screened` | Normal、startup、peak、duration、power-state資料已與已確認的 slot／board envelope比較 | 只可說通過文件篩選 |
| `Simulated` | 使用該 SSD envelope 的 startup、inrush、steady、load pulse與 tolerance profiles均有可重現 pass結果 | 只可說通過指定模型與條件的模擬 |
| `Mechanically_Reviewed` | 2280 envelope、connector／standoff Z-chain、top／bottom keepout與散熱空間完成審查 | 只可說指定機構配置已審查 |
| `Bench_Qualified` | 指定 host、board revision、SSD firmware／capacity通過安全上電、enumeration、link、stress、power與thermal測試 | 只可說該明確配置通過功能驗證 |
| `Supported_RevA` | 上述證據齊全，所有 exception／ECO 關閉並由 reviewer簽核 | 才可進 Rev A supported list；仍不代表 PCIe compliance |

`Candidate`、`Power_Screened`、`Mechanically_Reviewed`、`Bench_Qualified` 與
`Supported_RevA` 是 qualification workflow labels，不取代 repository 的 evidence
status tokens。每筆證據仍須標示 `Confirmed_Official`、`Simulated`、
`Not_Yet_Measured` 等適用狀態。

## Mandatory screening criteria

任何 SSD 必須同時滿足：

1. Exact device 是 M.2 2280、M-Key、PCIe NVMe；容量、firmware與 hardware revision
   均可追溯。
2. Governing M.2 revision、Pin mapping、3.3 V tolerance、sideband與mechanical
   requirements已完成 Gate review。
3. Vendor official data 足以定義 normal、startup與peak power；沒有官方 envelope時，
   不以通路頁、平均功耗或其他容量版本替代。
4. Normal SSD current不得超過已驗證 continuous envelope；目前 5 A只是 design point。
5. Peak current與duration不得超過實際通過的 transient envelope；目前
   7 A／100 µs只是 planned stress case。
6. eFuse current limit、dV/dt、ITIMER、SOA與 slot inrush／power budget已協調。
7. 3.3 V rail、shunt range、inductor peak、PGOOD與元件額定在所有 tolerance corner
   均通過。
8. Connector、standoff、component keepout、heatsink／airflow與 low-profile chassis
   配置無干涉。
9. 在明確 host/platform 上完成 enumeration、negotiated link width／speed、
   NVMe identify、short test、stress、power與thermal validation。
10. 測試失敗、firmware差異或容量版本差異都建立 exception；不得外推到未測型號。

## Automatic exclusion conditions

符合任一條件即不得列為 `Supported_RevA`：

- 非 2280 M-Key NVMe，或需要本板未實作的 sideband／power feature；
- 缺少可追溯的 exact-device power envelope；
- normal、startup或peak demand超過已確認的 slot／board envelope；
- canonical PSpice profile出現 rail超限、current limit、hiccup、PGOOD fault或
  unacceptable inrush；
- `|VSHUNT|`、inductor peak、thermal margin或元件額定不通過；
- connector／SSD／standoff／bracket／heatsink存在未處置干涉；
- 無法在指定 host穩定 enumerate為預期 link width／speed；
- stress test出現 reset、AER、link downshift、I/O error、thermal throttling超出
  release criterion或不可解釋的 power fault；
- 任何必要證據仍是 `Pending_Human_Verification`、
  `Pending_Fabricator_Confirmation` 或 `Not_Yet_Measured`。

## Supported-device table

此表在 qualification evidence成立前刻意保持空白。

| Manufacturer | Exact model | Capacity | Firmware | Official power source | Simulation run IDs | Host／link result | Power／thermal result | Qualification state | Reviewer／date |
|---|---|---|---|---|---|---|---|---|---|

空表表示「尚無 qualified SSD」，不是缺少文件。

## Per-device evidence record

新增候選時，至少記錄：

- Manufacturer、exact model、capacity、hardware revision、firmware；
- datasheet URL、revision、download date、local path與SHA-256；
- normal／idle／startup／peak current or power，以及duration與測試條件；
- board revision、host、BIOS／OS／driver、airflow與ambient；
- PSpice run IDs及所有 pass/fail measurements；
- connector／standoff／heatsink mechanical review evidence；
- enumeration、BDF、VID／DID、negotiated speed／width與NVMe identify；
- workload、duration、error counters、rail min/max、input current與temperature；
- deviation、ECO、reviewer、date與最終qualification state。

## Release Gate

Rev A release checklist 必須同時確認：

- supported-device table不是空表，或 release notes明確宣告「無 qualified SSD，
  evaluation only」；
- 每個 `Supported_RevA` row都有完整 evidence record；
- marketing、README、slides與resume沒有把候選、模擬或單一樣品結果外推；
- functional qualification沒有被描述為 PCIe compliance。

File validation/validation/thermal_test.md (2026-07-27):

# Basic Thermal Test

> 這是工程溫升調查，不是安全、可靠度或產品認證。

## 測點

- Ambient／host inlet。
- TPS543620 package top 與附近 PCB。
- Inductor。
- TPS259472L。
- 5mΩ shunt。
- M.2 connector power-pin 區。
- SSD controller、NAND／PMIC 可接近位置。

## 方法

1. 記錄 board orientation、case、fan、airflow、SSD heatsink、ambient。
2. Idle 穩定後記錄 baseline。
3. 執行已核准 staged workload，同步記錄 power、SMART、TMP1075。
4. 使用細線 thermocouple 為主要定量方法；IR camera 僅在 emissivity 已處理時作交叉檢查。
5. 記錄溫度隨時間曲線，不只記最高單點。
6. 冷卻後檢查是否有 permanent offset、discoloration 或 connector damage。

## 判定

- 每顆元件的 limit 來自其 datasheet junction／case guidance與實際量測方法。
- SSD limit 來自該 SSD 原廠資料；不存在通用假設值。
- Engineering margin 在測試前定義。
- 任何 thermal throttling 都同時比對 SMART、performance、power 和 link log。

## 狀態

所有結果目前為 `Not_Yet_Measured`。

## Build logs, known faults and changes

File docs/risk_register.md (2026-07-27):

# Risk Register

評分方式：Probability（P）與 Severity（S）各為 1–5，初始優先度為 `P × S`。分數是專案管理用 `Engineering_Assumption`，不代表實測失效率。

| ID | 風險 | P | S | 觸發條件／早期訊號 | 預防與緩解 | 驗證／關閉證據 | Owner | 狀態 |
|---|---|---:|---:|---|---|---|---|---|
| RSK-001 | PCIe TX/RX、lane 或 polarity mapping 錯誤 | 3 | 5 | 來源間命名視角不一致；pin row 無雙來源 | 建立 board-centric net naming；逐 pin 雙人覆核；Gate 1 前禁止正式接線 | signed pin-map review、netlist audit | Schematic | `Pending_Human_Verification` |
| RSK-002 | AC coupling ownership 判斷錯誤，造成重複或缺少 capacitor | 3 | 5 | host／SSD transmitter ownership 未明；相近 reference design 作法不同 | 只依 governing spec 與 endpoint implementation evidence 決策；Rev A 不任意加料 | source excerpt reference、schematic review | SI | `Pending_Human_Verification` |
| RSK-003 | PCIe slot 12 V power／inrush 不足 | 3 | 5 | power budget 接近 CEM limit；eFuse startup 觸發保護 | 先完成 CEM power review、target SSD envelope 與 inrush model；必要時限制 SSD | Gate 2 record、supported SSD list | Power | `Pending_Human_Verification` |
| RSK-004 | 6 A buck 無法承受 5 A steady-state thermal condition | 3 | 5 | estimated junction／board temperature margin 不足 | 使用 [TPS543620 datasheet](https://www.ti.com/lit/ds/symlink/tps543620.pdf) 計算 loss／thermal；改善 copper 或降額 | calculation review、planned thermal test | Power／PCB | `Planned` |
| RSK-005 | 7 A / 100 µs pulse 造成 droop、current limit 或 instability | 4 | 4 | PSpice rail droop 超出 SSD requirement；inductor saturation | 以可追溯 model 做 load-step；調整 Cout／inductor／limit 或限制 SSD | PSpice run package；planned bench correlation | Power | `Planned` |
| RSK-006 | TPS259472L 系統設定或模型 variant 不一致，fault response 不符需求 | 3 | 5 | 472L 在 ITIMER後是 active current limit，`L` latch發生於 thermal shutdown後；若被誤當 474L circuit-breaker，fault energy與recovery會錯估 | 依 [power budget](power_budget.md) 與官方資料鎖定 fault policy；BOM／symbol／model／設定四方比對；必要時以 474L ECO重做 overvoltage／fault驗證 | configuration review、SOA與fault-profile correlation | Power／Library | `Planned` |
| RSK-007 | eFuse SOA 在 startup／short condition 超限 | 3 | 5 | large Cout、slow slew 或 short event 使 die heating 過高 | 計算 inrush、timer、SOA；PSpice 與 planned current-limited bench test | SOA worksheet、fault test log | Power | `Planned` |
| RSK-008 | 5 mΩ shunt 壓降、功耗或 telemetry range 不合 | 3 | 3 | INA238 full-scale／calibration 不匹配；shunt 溫升過高 | 建立 error budget、power／TCR／Kelvin review；確認 exact WSK2512 suffix | calculation、layout inspection、planned DMM correlation | Telemetry | `Planned` |
| RSK-009 | I²C header 外部回灌 3.3 V rail | 3 | 4 | external controller 帶電且板卡未上電 | 使用 U5 ADP198 reverse-current blocker 加 RISO1；header 標示 sense-only；檢查 pull-up ownership | schematic review、reverse leakage calculation、unpowered injection／short test | Telemetry／Validation | `Planned` |
| RSK-010 | M.2 connector footprint 或 standoff 高度錯誤 | 3 | 5 | exact drawing 不可得；使用相近 suffix footprint | 不從 family drawing 猜測 land pattern；保存 exact drawing；1:1 print、3D 與實體零件核對 | signed footprint validation | Mechanical／Library | `Pending_Human_Verification` |
| RSK-011 | JLCPCB stack-up 改版導致 impedance geometry 失效 | 3 | 5 | quote 時 laminate／copper／prepreg 與設計假設不同 | release 當天重新取得 stack-up 與 calculator evidence；geometry change 重新跑 constraints | fabricator evidence、constraint diff | PCB／Manufacturing | `Pending_Fabricator_Confirmation` |
| RSK-012 | 高速 pair 跨 plane split 或缺 return path | 3 | 5 | placement 迫使 layer transition／L4 split reference | 優先 L1/L2；必要 transition 成對且加鄰近 GND vias；逐 pair return-path review | layout screenshots、constraint report | PCB／SI | `Planned` |
| RSK-013 | Buck switch node／hot loop 耦合至 PCIe lane | 3 | 4 | power stage 靠近 connector breakout；lane 經過 SW keepout | floorplan 先隔離 power 與 high-speed；最小化 hot loop；建立 SW keepout | placement review、layout review | PCB／Power | `Planned` |
| RSK-014 | PSpice vendor model 不收斂或不支援目標分析 | 4 | 3 | startup failed、hidden limits、loop model 不可用 | 保存 model version／hash；先跑 vendor example；記錄 solver／limitation；不偽造結果 | run log 或 `Not_Supported_By_Model` record | Simulation | `Planned` |
| RSK-015 | OrCAD 25.1 license／feature 不足 | 2 | 4 | Capture、Advanced Analysis、ODB++ export 無法啟動 | 先做 license smoke test；將 optional output 明示；不以手工檔案替代 native data | tool/version/license log | CAD | `Pending_Human_Verification` |
| RSK-016 | 供應或 lifecycle 變化使 selected part 不可採購 | 3 | 3 | manufacturer status／stock 改變；alternative 未驗證 | release 前重新查原廠 lifecycle 與 AVL；備選料需獨立 footprint／electrical review | dated AVL／BOM review | Component／Manufacturing | `Planned` |
| RSK-017 | Enumeration 成功被誤寫成 compliance 通過 | 2 | 5 | slide／resume 使用「compliant」字樣但無 lab report | 全 repository claim audit；固定用 functional bring-up／link verification 語句 | document grep、review sign-off | Project owner | `Planned` |
| RSK-018 | 將 simulation／estimate 誤當 measurement | 2 | 5 | 圖表缺 evidence type、instrument、date 或 conditions | 每張圖標 `Simulated`／`Estimated`／`Not_Yet_Measured`；量測才記 instrument／setup | evidence audit | Project owner | `Planned` |

## Top-five review focus

目前最高關注為 RSK-001、RSK-003、RSK-004、RSK-007、RSK-010／011／012。它們共同特徵是一次錯誤可能造成無法 enumerate、電源保護誤動作、熱失效、機構不相容或整板重製，因此必須在對應 design gate 前關閉，不接受「layout 後再看」。

## 升級與 ECO 規則

- `P × S ≥ 15`：必須在 PDR／CDR 明確 review，未關閉不得 release。
- 新 evidence 推翻既有假設時，先更新 requirement、assumption 與 source log，再修改 CAD。
- 實體測試失敗時建立 debug log，先保存 symptom、conditions 與 observation，再提出 corrective action。
- 任何改動若影響 pin、power、stack-up、footprint 或 manufacturing output，必須新建 ECO 並重新跑相依檢查。

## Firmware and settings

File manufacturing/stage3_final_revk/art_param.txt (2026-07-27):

DEVICE-TYPE             GERBER_RS274X
OUTPUT-UNITS            MM
FILM-SIZE               600 600
FORMAT                  4.6
ABORT-ON-ERROR          NO
SCALE                   1
SUPPRESS-LEAD-ZEROES    NO
SUPPRESS-TRAIL-ZEROES   NO
SUPPRESS-EQUAL          YES
UNDEF-APT-CONT          NO

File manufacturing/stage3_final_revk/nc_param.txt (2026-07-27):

INTEGER-PLACES          3
DECIMAL-PLACES          5
X-OFFSET                0.000000
Y-OFFSET                0.000000
FEEDRATE                1
COORDINATES             ABSOLUTE
OUTPUT-UNITS            METRIC
TOOL-ORDER              INCREASING
REPEAT-CODES            NO
SUPPRESS-LEAD-ZEROES    NO
SUPPRESS-TRAIL-ZEROES   NO
SUPPRESS-EQUAL          NO
TOOL-SELECT             YES
OPTIMIZE_DRILLING       YES
ENHANCED-EXCELLON       YES
HEADER                  none
LEADER                  12
CODE                    ASCII
SEPARATE                YES
SEPARATE-ROUTING        NO
DRILLING                LAYER-PAIR
BACKDRILL               NO
CAVITY                  NO
COUNTER                 NO
TOLERANCE_DRILL         NO
TOLERANCE_TRAVEL        NO
TOOL_SIZE               YES
ROTATION                NO
NON_STANDARD            NO
TOTAL_DRILL             YES
SEPARATE_SLOT           YES
SUPPRESS_TOLERANCE      NO
SUPPRESS_TOOLSIZE       NO
SUPPRESS_ROTATION       NO

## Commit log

2026-07-27 publish RevK interview portfolio
    [3d_model_mapping.csv, PACKAGE_MANIFEST.csv, PCIE_GEN3_X4_NVME_ADAPTER_REVA_STAGE2.DSN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]
2026-07-27 transform portfolio into traceable PCB case study
